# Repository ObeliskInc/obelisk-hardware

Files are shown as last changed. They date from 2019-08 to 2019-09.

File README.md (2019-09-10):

# Obelisk Hardware Files

## Overview
This repository contains the enclosure, control board, and hashing board designs of both generations of Obelisk miners. The files herein give
you the ability to manufacture Obelisk enclosures or PCBs. You are welcome to modify the designs and use them in your own projects.

This repository does not contain the designs for SC1 or DCR1 ASICs, which are proprietary IP.

*NOTE: This document is not yet complete.  We expect to add more information over the following weeks.*

## File Organization

The files in this repository are split into two sections:

* Generation 1 Mining Hardware
* Generation 2 Mining Hardware

Each section includes **Mechanical** and **Electrical** designs.

Mechanical designs include the following file types:

* PDF files: these are typically engineering drawings, which are helpful to manufacturers
* EASM files: these are SolidWorks eDrawings files, which provide a view of the entire assembly that cannot be edited
* DXF files: these are 2-dimentional drawings files, which are typically used for components that are cut (and not bent)
* SLDPRT files: these are SolidWorks part files, which can easily be modified
* SLDASM files: these are SolidWorks assembly files, which references individual SLDPRT files and can be easily modified

To modify our mechanical designs, you can make changes to SLDPRT files in SolidWorks, create a new SLDASM assembly, and generate PDF drawings as needed.
There are numerous tools to convert SolidWorks files to other file formats, some of which can be used by open source CAD editors.

## Generation 1 Mining Hardware

Our first generation of miners, these are also referred to as "Batch 1" hardware. These Gen 1 miners use 120mm fans and resemble
a more traditional ASIC miner form factor.

The Gen 1 enclosure consists of four individual pieces of powder-coated sheet metal, as well as plastic PCB guides and sheet metal airflow guides.

The Gen 1 control board utilizes a SOM (system on module) made by Microchip, and its size is intended to serve as a bottom rest for the hashing boards.

The Gen 1 hashing board consists of 15 ASICs powered in series, each with individual heatsinks.

## Generation 2 Mining hardware

Our second generation of miners, these are also referred to as "Batch 2" or "slim" hardware. These Gen 2 miners use 60mm fans and are approximately half
the width of a traditional ASIC miner. Internally, we referred to Gen 2 miners as the "slimmy" design.

The Gen 2 enclosure consists of five individual pieces of powder-coated sheet metal, and utilizes several standoffs in lieu of screws for easy dissasembly.

The Gen 2 control board is extremely compact and utilizes a microcontroller made by STMicroelectronics.

The Gen 2 hashing board consists of 32 ASICs powered in series, with a large uniform heatsink for better resilience and easier install.

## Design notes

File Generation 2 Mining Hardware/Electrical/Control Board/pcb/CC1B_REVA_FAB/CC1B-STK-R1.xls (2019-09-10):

Customer: |  | Orchid
Project Name: |  | CC1B
 | Revision: | 1.0
Material: |  | IT-180A OR EQUIVALENT
Layer Structure: |  | 8L
Finished Thickness: |  | 72mil+/-10%
Date: |  | 2018-07-30
 |  |  | Stack-up Guideline
Layer |  | Cu Weight | Proposed Nominal Thickness (mils) | Single ended |  | Diff Pairs
 |  |  |  | 50ohm+/-10% |  | 100ohm+/-10%
 |  |  |  | Target LW | Finished LW | Target LW/SP | Finished LW/SP
 | Soldermask
L1 | Top | 1/2oz w/1oz Plating | 2.10 | 5.0 | 5.0 | 4.1/10.9 | 4.1/10.9
 | Prepreg |  | 4.00
L2 | GND | 1/2oz | 0.65
 | Core |  | 6
L3 | Signal | 1/2oz | 0.65 | 5.0 | 4.5 | 4.1/10.9 | 4.1/10.9
 | Prepreg |  | 6.00
L4 | PWR | 1/2oz | 0.65
 | Core |  | 32
L5 | PWR | 1/2oz | 0.65
 | Prepreg |  | 6.00
L6 | Signal | 1/2oz | 0.65 | 5.0 | 4.5 | 4.1/10.9 | 4.1/10.9
 | Core |  | 6
L7 | GND | 1/2oz | 0.65
 | Prepreg |  | 4.00
L8 | Bottom | 1/2oz w/1oz Plating | 2.10 | 5.0 | 5.0 | 4.1/10.9 | 4.1/10.9
 | Soldermask
Finished Thickness (mils) |  |  | 72.10
Stack-up Guideline Notes:
 | Design line width and spacing need to be verified by manufacturing to achieve desired impedance.

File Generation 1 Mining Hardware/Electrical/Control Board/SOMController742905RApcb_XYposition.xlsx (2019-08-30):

PartType | RefDes | PartDecal | Pins | Layer | Orient. | X | Y | SMD | Glued
17-000018 | C1 | CC0603A | 2 | Top | 180 | 190 | 40 | Yes | No
17-000018 | C2 | CC0603A | 2 | Top | 0 | 204.2 | 36.2 | Yes | No
17-000018 | C3 | CC0603A | 2 | Top | 0 | 204.2 | 38 | Yes | No
17-000018 | C4 | CC0603A | 2 | Top | 0 | 200.2 | 32.4 | Yes | No
17-000064 | C5 | 0805 | 2 | Top | 270 | 241.6 | 47.2 | Yes | No
17-000112 | C6 | RAD6_3MM | 2 | Top | 180 | 249.6 | 46 | Yes | No
17-000075 | C7 | CC0402A | 2 | Top | 180 | 149.813 | 33.01 | Yes | No
17-000014 | C8 | CC0402A | 2 | Top | 270 | 83.8 | -48.8 | Yes | No
17-000075 | C9 | CC0402A | 2 | Top | 0 | 103.8 | -31.2 | Yes | No
17-000075 | C10 | CC0402A | 2 | Top | 180 | 91.2 | 4.4 | Yes | No
17-000075 | C11 | CC0402A | 2 | Top | 270 | 106.6 | -23 | Yes | No
17-000075 | C12 | CC0402A | 2 | Top | 180 | 91.2 | 3 | Yes | No
17-000075 | C13 | CC0402A | 2 | Top | 270 | 114.6 | -23 | Yes | No
17-000075 | C14 | CC0402A | 2 | Top | 180 | 91.253 | 5.713 | Yes | No
17-000075 | C15 | CC0402A | 2 | Top | 270 | 146.321 | 14.124 | Yes | No
17-000075 | C16 | CC0402A | 2 | Top | 180 | 67 | 11.6 | Yes | No
17-000075 | C17 | CC0402A | 2 | Top | 0 | 134 | 31.55 | Yes | No
17-000075 | C18 | CC0402A | 2 | Top | 270 | 111.8 | -45 | Yes | No
17-000075 | C19 | CC0402A | 2 | Top | 270 | 33 | -7.6 | Yes | No
17-000090 | C20 | 1206 | 2 | Top | 180 | 18.6 | 8 | Yes | No
17-000075 | C21 | CC0402A | 2 | Top | 0 | 107.75 | -51.1 | Yes | No
17-000075 | C22 | CC0402A | 2 | Top | 180 | 104 | -45 | Yes | No
17-000018 | C23 | CC0603A | 2 | Top | 90 | 186.2 | 36.8 | Yes | No
17-000018 | C24 | CC0603A | 2 | Top | 0 | 194.6 | 30.4 | Yes | No
17-000018 | C25 | CC0603A | 2 | Top | 180 | 205.4 | 30.4 | Yes | No
17-000054 | C26 | CC0402A | 2 | Top | 90 | 106.8 | -45 | Yes | No
17-000079 | C27 | DSK-614 | 2 | Top | 0 | 102.25 | -36.95 | Yes | No
17-000006 | C28 | 0603 | 2 | Top | 0 | 107.55 | -49.3 | Yes | No
17-000080 | C29 | CC0603A | 2 | Top | 180 | 89.665 | 7.142 | Yes | No
17-000080 | C30 | CC0603A | 2 | Top | 270 | 104.8 | -23.2 | Yes | No
17-000080 | C31 | CC0603A | 2 | Top | 180 | 91 | 1.2 | Yes | No
17-000080 | C32 | CC0603A | 2 | Top | 270 | 112.6 | -23.2 | Yes | No
17-000084 | C33 | CC1206 | 2 | Top | 0 | 294.8 | -40.8 | Yes | No
17-000084 | C34 | CC1206 | 2 | Top | 180 | 288.4 | -29.4 | Yes | No
17-000084 | C35 | CC1206 | 2 | Top | 180 | 291.2 | -5.8 | Yes | No
17-000084 | C36 | CC1206 | 2 | Top | 180 | 288.4 | 5.6 | Yes | No
17-000084 | C37 | CC1206 | 2 | Top | 180 | 291.4 | 29.2 | Yes | No
17-000084 | C38 | CC1206 | 2 | Top | 180 | 288.4 | 40.4 | Yes | No
17-000081 | C39 | CC0402A | 2 | Top | 0 | 87 | -42.4 | Yes | No
17-000081 | C40 | CC0402A | 2 | Top | 0 | 296 | -47.8 | Yes | No
17-000018 | C41 | CC0603A | 2 | Top | 180 | 167.132 | -21.908 | Yes | No
17-000075 | C42 | CC0402A | 2 | Top | 180 | 167.45 | -23.495 | Yes | No
17-000054 | C43 | CC0402A | 2 | Top | 180 | 212.25 | -1.5 | Yes | No
17-000054 | C44 | CC0402A | 2 | Top | 180 | 212.25 | -4.5 | Yes | No
17-000054 | C45 | CC0402A | 2 | Top | 180 | 212.25 | -7.5 | Yes | No
17-000054 | C46 | CC0402A | 2 | Top | 180 | 212.25 | -10.5 | Yes | No
17-000054 | C47 | CC0402A | 2 | Top | 0 | 230.75 | -11 | Yes | No
17-000054 | C48 | CC0402A | 2 | Top | 0 | 230.75 | -8 | Yes | No
17-000075 | C49 | CC0402A | 2 | Top | 90 | 223.25 | 0.75 | Yes | No
17-000090 | C50 | 1206 | 2 | Top | 270 | 17.7 | -8.1 | Yes | No
17-000064 | C51 | 0805 | 2 | Top | 270 | 244.4 | 47.2 | Yes | No
17-000036 | C52 | CC0603A | 2 | Top | 0 | 222.5 | 39.25 | Yes | No
17-000083 | C53 | CC1206 | 2 | Top | 180 | 226 | 34.6 | Yes | No
17-000083 | C54 | CC1206 | 2 | Top | 180 | 226 | 32 | Yes | No
17-000084 | C55 | CC1206 | 2 | Top | 180 | 222 | 48.4 | Yes | No
17-000084 | C56 | CC1206 | 2 | Top | 180 | 222 | 45.8 | Yes | No
17-000014 | C57 | CC0402A | 2 | Top | 90 | 298.4 | -48.6 | Yes | No
17-000054 | C58 | CC0402A | 2 | Top | 180 | 80.25 | -39.25 | Yes | No
17-000054 | C59 | CC0402A | 2 | Top | 90 | 265.8 | -46.4 | Yes | No
17-000055 | C60 | CC0402A | 2 | Top | 0 | 72.2 | -38.4 | Yes | No
17-000055 | C61 | CC0402A | 2 | Top | 180 | 277 | -47.4 | Yes | No
17-000036 | C62 | CC0603A | 2 | Top | 180 | 72.25 | -46.25 | Yes | No
17-000036 | C63 | CC0603A | 2 | Top | 180 | 283.5 | -46.5 | Yes | No
17-000075 | C64 | CC0402A | 2 | Top | 270 | 20.2 | -7.6 | Yes | No
17-000075 | C65 | CC0402A | 2 | Top | 90 | 113.4 | -47.8 | Yes | No
17-000075 | C66 | CC0402A | 2 | Top | 180 | 224.6 | 9.6 | Yes | No
53-000021 | D1 | LED2T1_RT | 4 | Top | 90 | 7.24 | -18.27 | No | Yes
34-000023 | D2 | SOT23 | 3 | Top | 270 | 100.2 | -31.2 | Yes | No
34-000024 | D3 | SOD-123F | 2 | Top | 270 | 97.25 | -29.95 | Yes | No
34-000026 | D4 | SMB | 2 | Top | 180 | 295.2 | -29.4 | Yes | No
34-000026 | D5 | SMB | 2 | Top | 180 | 295.2 | 5.6 | Yes | No
34-000026 | D6 | SMB | 2 | Top | 180 | 295.2 | 40.4 | Yes | No
34-000023 | D7 | SOT23 | 3 | Top | 270 | 299.2 | -45.2 | Yes | No
TP-PIN | FID1 | FIDUCIAL-GT | 1 | Top | 0 | 2 | 53 | Yes | No
TP-PIN | FID2 | FIDUCIAL-GT | 1 | Top | 0 | 2 | -53 | Yes | No
TP-PIN | FID3 | FIDUCIAL-GT | 1 | Top | 0 | 318 | 53 | Yes | No
TP-PIN | FID4 | FIDUCIAL-GT | 1 | Bottom | 0 | 2 | 53 | Yes | No
TP-PIN | FID5 | FIDUCIAL-GT | 1 | Bottom | 0 | 2 | -53 | Yes | No
TP-PIN | FID6 | FIDUCIAL-GT | 1 | Bottom | 0 | 318 | 53 | Yes | No
TP-PIN | FID7 | FIDUCIAL-GT | 1 | Top | 0 | 93.34 | 22.66 | Yes | No
TP-PIN | FID8 | FIDUCIAL-GT | 1 | Top | 0 | 136.54 | 22.66 | Yes | No
23-000030 | J1 | AMPHENOL_20021121-00010 | 10 | Top | 0 | 70 | -23.8 | Yes | No
23-000036 | J2 | B04B-PASK | 4 | Top | 0 | 152.083 | -18.098 | No | Yes
23-000046 | J3 | M0850400012 | 34 | Bottom | 0 | 274 | 34.52 | No | Yes
23-000046 | J4 | M0850400012 | 34 | Bottom | 0 | 274 | -0.48 | No | Yes
23-000046 | J5 | M0850400012 | 34 | Bottom | 0 | 274 | -35.48 | No | Yes
23-000052 | J6 | HDR100SIP6 | 6 | Top | 270 | 78.75 | 15.55 | No | No
23-000052 | J7 | HDR100SIP6 | 6 | Top | 270 | 82.75 | 15.55 | No | No
23-000004 | J8 | HDR100SIP3 | 3 | Top | 270 | 74.75 | 14.3 | No | No
23-000026 | J9 | 10118192 | 11 | Top | 0 | 116.25 | -53 | Yes | No
23-000048 | J10 | RJE73-188 | 16 | Top | 270 | 6 | 0 | No | Yes
23-000059 | J11 | FTSH-105-01-F-DV-K | 10 | Top | 90 | 88.2 | -23.7 | Yes | No
OBELISK_LOGO | J12 | OBELISK_LOGO | 0 | Bottom | 0 | 162 | 42 | Yes | No
23-000053 | J13 | HDR20P2X10-FEMALE | 20 | Top | 270 | 195 | -27 | No | No
23-000051 | J14 | M0470531000 | 5 | Bottom | 0 | 78 | -48.75 | No | No
23-000051 | J15 | M0470531000 | 5 | Bottom | 0 | 289.25 | -48.75 | No | No
23-000053 | J16 | HDR20P2X10-FEMALE | 20 | Top | 270 | 159 | -27 | No | Yes
23-000006 | JP1 | HDR100SIP2RA | 2 | Top | 0 | 135.8 | -21.6 | No | No
23-000006 | JP2 | HDR100SIP2RA | 2 | Top | 90 | 145.36 | 7.031 | No | No
41-000027 | L1 | LC0805 | 2 | Top | 90 | 184 | 37.2 | Yes | No
41-000027 | L2 | LC0805 | 2 | Top | 270 | 76.75 | -45.08 | Yes | No
41-000022 | L3 | LC1210 | 2 | Top | 180 | 189.4 | 33.2 | Yes | No
41-000023 | L4 | 0603 | 2 | Top | 180 | 107.6 | -47.6 | Yes | No
41-000027 | L5 | LC0805 | 2 | Top | 270 | 191.4 | 29 | Yes | No
41-000022 | L6 | LC1210 | 2 | Top | 180 | 195.4 | 33.2 | Yes | No
41-000027 | L7 | LC0805 | 2 | Top | 270 | 208.4 | 29 | Yes | No
41-000022 | L8 | LC1210 | 2 | Top | 0 | 205 | 33.2 | Yes | No
41-000023 | L9 | 0603 | 2 | Top | 0 | 6.75 | 9.5 | Yes | No
41-000023 | L10 | 0603 | 2 | Top | 90 | 123.2 | -50.6 | Yes | No
41-000029 | L11 | L7165 | 2 | Top | 90 | 227.8 | 39.8 | Yes | No
41-000027 | L12 | LC0805 | 2 | Top | 270 | 288 | -45.08 | Yes | No
41-000030 | L13 | 0603 | 2 | Top | 270 | 79.25 | -45.5 | Yes | No
41-000030 | L14 | 0603 | 2 | Top | 270 | 81.75 | -45.75 | Yes | No
41-000030 | L15 | 0603 | 2 | Top | 270 | 290.5 | -45.4 | Yes | No
41-000030 | L16 | 0603 | 2 | Top | 270 | 293 | -45.2 | Yes | No
41-000031 | L17 | LC0805 | 2 | Top | 0 | 166.878 | -19.368 | Yes | No
41-000023 | L18 | 0603 | 2 | Top | 0 | 120 | -48.2 | Yes | No
57-000014 | MH1 | MH093PTH | 1 | Top | 0 | 5 | -50 | No | Yes
57-000014 | MH2 | MH093PTH | 1 | Top | 0 | 5 | 50 | No | Yes
57-000014 | MH3 | MH093PTH | 1 | Top | 0 | 315 | 50 | No | Yes
57-000014 | MH4 | MH093PTH | 1 | Top | 0 | 315 | -50 | No | Yes
57-000014 | MH5 | MH093PTH | 1 | Top | 0 | 160 | 0 | No | Yes
57-000014 | MH6 | MH093PTHA | 1 | Top | 0 | 57.5 | 31.1 | No | Yes
42-000071 | MOD1 | SAMA5D27_SOM1 | 176 | Top | 0 | 115 | 0 | Yes | Yes
87-000021 | Q1 | SOT-23 | 3 | Top | 90 | 11 | -22.8 | Yes | No
87-000021 | Q2 | SOT-23 | 3 | Top | 90 | 11 | -19.3 | Yes | No
87-000021 | Q3 | SOT-23 | 3 | Top | 90 | 87 | -44.9 | Yes | No
87-000021 | Q4 | SOT-23 | 3 | Top | 90 | 295.8 | -45.2 | Yes | No
87-000021 | Q5 | SOT-23 | 3 | Top | 270 | 65 | -41 | Yes | No
87-000021 | Q6 | SOT-23 | 3 | Top | 180 | 271.4 | -49.6 | Yes | No
87-000022 | Q7 | SOT-23 | 3 | Top | 270 | 72.2 | -41 | Yes | No
87-000022 | Q8 | SOT-23 | 3 | Top | 90 | 277 | -45 | Yes | No
62-000042 | R1 | RC0402A | 2 | Top | 0 | 139.954 | 1.27 | Yes | No
62-000041 | R2 | RC0402A | 2 | Top | 0 | 215.25 | 0 | Yes | No
62-000041 | R3 | RC0402A | 2 | Top | 0 | 215.25 | -3 | Yes | No
62-000041 | R4 | RC0402A | 2 | Top | 0 | 215.25 | -6 | Yes | No
62-000041 | R5 | RC0402A | 2 | Top | 0 | 215.25 | -9 | Yes | No
62-000041 | R6 | RC0402A | 2 | Top | 180 | 227.75 | -9.5 | Yes | No
62-000103 | R7 | RC0402A | 2 | Top | 90 | 83.8 | -45.6 | Yes | No
62-000103 | R8 | RC0402A | 2 | Top | 180 | 296 | -49.4 | Yes | No
62-000096 | R9 | RC0402A | 2 | Top | 180 | 188.6 | 35.8 | Yes | No
62-000096 | R10 | RC0402A | 2 | Top | 90 | 206.2 | 28 | Yes | No
62-000097 | R11 | RC0402A | 2 | Top | 0 | 191.6 | 35.8 | Yes | No
62-000097 | R12 | RC0402A | 2 | Top | 90 | 204.6 | 28 | Yes | No
62-000096 | R13 | RC0402A | 2 | Top | 90 | 193.8 | 28 | Yes | No
62-000097 | R14 | RC0402A | 2 | Top | 90 | 195.4 | 28 | Yes | No
62-000044 | R15 | RC0402A | 2 | Top | 90 | 221.75 | 7 | Yes | No
62-000041 | R16 | RC0402A | 2 | Top | 180 | 15 | -25.4 | Yes | No
62-000100 | R17 | RC0402A | 2 | Top | 0 | 64.8 | -20.8 | Yes | No
62-000100 | R18 | RC0402A | 2 | Top | 0 | 64.8 | -22.3 | Yes | No
62-000100 | R19 | RC0402A | 2 | Top | 0 | 64.8 | -23.8 | Yes | No
62-000100 | R20 | RC0402A | 2 | Top | 0 | 64.8 | -25.3 | Yes | No
62-000100 | R21 | RC0402A | 2 | Top | 0 | 75.5 | -20.9 | Yes | No
62-000100 | R22 | RC0402A | 2 | Top | 0 | 75.5 | -22.4 | Yes | No
62-000114 | R23 | RC0402A | 2 | Top | 270 | 4.8 | -21.2 | Yes | No
62-000114 | R24 | RC0402A | 2 | Top | 270 | 7.2 | -21.2 | Yes | No
62-000114 | R25 | RC0402A | 2 | Top | 0 | 13.667 | 6.952 | Yes | No
62-000014 | R26 | RC0402A | 2 | Top | 270 | 110.2 | -45 | Yes | No
62-000041 | R27 | RC0402A | 2 | Top | 0 | 194.2 | 41.6 | Yes | No
62-000091 | R28 | RC0402A | 2 | Top | 270 | 67.8 | -41 | Yes | No
62-000091 | R29 | RC0402A | 2 | Top | 180 | 277 | -50.6 | Yes | No
62-000041 | R30 | RC0402A | 2 | Top | 90 | 203.2 | 40.4 | Yes | No
62-000110 | R31 | RC0402A | 2 | Top | 270 | 23.2 | 7.4 | Yes | No
62-000110 | R32 | RC0402A | 2 | Top | 270 | 29.6 | 7.4 | Yes | No
62-000028 | R33 | 1206 | 2 | Top | 0 | 72.25 | -44 | Yes | No
62-000044 | R34 | RC0402A | 2 | Top | 90 | 110.6 | -22.8 | Yes | No
62-000028 | R35 | 1206 | 2 | Top | 0 | 283.5 | -44 | Yes | No
62-000041 | R36 | RC0402A | 2 | Top | 0 | 65.6 | -36.8 | Yes | No
62-000041 | R37 | RC0402A | 2 | Top | 0 | 83 | -26.45 | Yes | No
62-000041 | R38 | RC0402A | 2 | Top | 270 | 145 | 14.05 | Yes | No
62-000041 | R39 | RC0402A | 2 | Top | 180 | 134 | 30.05 | Yes | No
62-000041 | R40 | RC0402A | 2 | Top | 0 | 120.2 | 29 | Yes | No
62-000013 | R41 | RC0402A | 2 | Top | 180 | 141.35 | 8.6 | Yes | No
62-000041 | R42 | RC0402A | 2 | Top | 180 | 96 | -46.5 | Yes | No
62-000041 | R43 | RC0402A | 2 | Top | 90 | 86.015 | 4.285 | Yes | No
62-000041 | R44 | RC0402A | 2 | Top | 90 | 270.6 | -46.4 | Yes | No
62-000041 | R45 | RC0402A | 2 | Top | 0 | 96 | -48 | Yes | No
62-000041 | R46 | RC0402A | 2 | Top | 180 | 227.75 | -6.5 | Yes | No
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

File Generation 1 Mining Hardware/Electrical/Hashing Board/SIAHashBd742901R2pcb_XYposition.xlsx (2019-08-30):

PartType | RefDes | PartDecal | Pins | Layer | Orient. | X | Y | SMD | Glued
17-000073 | C1 | 0805 | 2 | Top | 90 | 128.4 | 93.6 | Yes | Yes
17-000073 | C2 | 0805 | 2 | Top | 90 | 128.4 | 55.6 | Yes | Yes
17-000073 | C3 | 0805 | 2 | Top | 0 | 134.8 | 96.4 | Yes | Yes
17-000074 | C4 | CC0603 | 2 | Top | 180 | 106.25 | 115 | Yes | Yes
17-000074 | C5 | CC0603 | 2 | Top | 90 | 128.8 | 114.6 | Yes | Yes
17-000074 | C6 | CC0603 | 2 | Top | 0 | 106.25 | 77 | Yes | Yes
17-000074 | C7 | CC0603 | 2 | Top | 90 | 128.8 | 76.6 | Yes | Yes
17-000074 | C8 | CC0603 | 2 | Top | 0 | 155.75 | 74 | Yes | Yes
17-000074 | C9 | CC0603 | 2 | Top | 270 | 133.4 | 74.6 | Yes | Yes
17-000086 | C10 | CC0603A | 2 | Bottom | 180 | 113.4 | 109.4 | Yes | Yes
17-000086 | C11 | CC0603A | 2 | Bottom | 0 | 119.8 | 97.8 | Yes | Yes
17-000086 | C12 | CC0603A | 2 | Top | 0 | 113 | 93 | Yes | Yes
17-000086 | C13 | CC0603A | 2 | Top | 90 | 105.6 | 97.8 | Yes | Yes
17-000086 | C14 | CC0603A | 2 | Bottom | 180 | 113.4 | 71.4 | Yes | Yes
17-000086 | C15 | CC0603A | 2 | Bottom | 0 | 119.8 | 59.8 | Yes | Yes
17-000086 | C16 | CC0603A | 2 | Top | 0 | 113 | 55 | Yes | Yes
17-000086 | C17 | CC0603A | 2 | Top | 90 | 105.6 | 59.8 | Yes | Yes
17-000086 | C18 | CC0603A | 2 | Bottom | 0 | 148.6 | 79.6 | Yes | Yes
17-000086 | C19 | CC0603A | 2 | Bottom | 180 | 142.2 | 91.2 | Yes | Yes
17-000086 | C20 | CC0603A | 2 | Top | 180 | 149 | 96 | Yes | Yes
17-000086 | C21 | CC0603A | 2 | Top | 270 | 156.4 | 91.2 | Yes | Yes
17-000087 | C22 | CC0402A | 2 | Top | 180 | 128.4 | 104 | Yes | Yes
17-000087 | C23 | CC0402A | 2 | Top | 180 | 128.4 | 98 | Yes | Yes
17-000087 | C24 | CC0402A | 2 | Bottom | 270 | 117 | 101.6 | Yes | Yes
17-000087 | C25 | CC0402A | 2 | Bottom | 270 | 117 | 104 | Yes | Yes
17-000087 | C26 | CC0402A | 2 | Bottom | 270 | 117 | 106.4 | Yes | Yes
17-000087 | C27 | CC0402A | 2 | Top | 180 | 121.2 | 93 | Yes | Yes
17-000087 | C28 | CC0402A | 2 | Top | 0 | 107 | 93 | Yes | Yes
17-000087 | C29 | CC0402A | 2 | Bottom | 180 | 118.2 | 109 | Yes | Yes
17-000087 | C30 | CC0402A | 2 | Bottom | 0 | 120.6 | 109 | Yes | Yes
17-000087 | C31 | CC0402A | 2 | Bottom | 0 | 113.4 | 98.2 | Yes | Yes
17-000087 | C32 | CC0402A | 2 | Bottom | 180 | 115.8 | 98.2 | Yes | Yes
17-000087 | C33 | CC0402A | 2 | Top | 180 | 128.4 | 66 | Yes | Yes
17-000087 | C34 | CC0402A | 2 | Bottom | 270 | 117 | 63.6 | Yes | Yes
17-000087 | C35 | CC0402A | 2 | Bottom | 270 | 117 | 66 | Yes | Yes
17-000087 | C36 | CC0402A | 2 | Bottom | 270 | 117 | 68.4 | Yes | Yes
17-000087 | C37 | CC0402A | 2 | Top | 180 | 128.4 | 60 | Yes | Yes
17-000087 | C38 | CC0402A | 2 | Top | 0 | 121.4 | 55 | Yes | Yes
17-000087 | C39 | CC0402A | 2 | Bottom | 180 | 118.2 | 71 | Yes | Yes
17-000087 | C40 | CC0402A | 2 | Bottom | 0 | 120.6 | 71 | Yes | Yes
17-000087 | C41 | CC0402A | 2 | Bottom | 0 | 113.4 | 60.2 | Yes | Yes
17-000087 | C42 | CC0402A | 2 | Bottom | 180 | 115.8 | 60.2 | Yes | Yes
17-000087 | C43 | CC0402A | 2 | Top | 0 | 107 | 55 | Yes | Yes
17-000087 | C44 | CC0402A | 2 | Bottom | 180 | 148.6 | 90.8 | Yes | Yes
17-000087 | C45 | CC0402A | 2 | Bottom | 0 | 146.2 | 90.8 | Yes | Yes
17-000087 | C46 | CC0402A | 2 | Top | 180 | 155 | 96 | Yes | Yes
17-000087 | C47 | CC0402A | 2 | Top | 0 | 141 | 96 | Yes | Yes
17-000087 | C48 | CC0402A | 2 | Bottom | 90 | 145 | 87.4 | Yes | Yes
17-000087 | C49 | CC0402A | 2 | Bottom | 90 | 145 | 85 | Yes | Yes
17-000087 | C50 | CC0402A | 2 | Bottom | 90 | 145 | 82.6 | Yes | Yes
17-000087 | C51 | CC0402A | 2 | Top | 0 | 133.8 | 91 | Yes | Yes
17-000087 | C52 | CC0402A | 2 | Top | 0 | 133.8 | 85 | Yes | Yes
17-000087 | C53 | CC0402A | 2 | Bottom | 0 | 143.8 | 80 | Yes | Yes
17-000087 | C54 | CC0402A | 2 | Bottom | 180 | 141.4 | 80 | Yes | Yes
17-000013 | C55 | CC0402A | 2 | Top | 270 | 115.4 | 115.2 | Yes | Yes
17-000013 | C56 | CC0402A | 2 | Top | 270 | 112.6 | 115.2 | Yes | Yes
17-000013 | C57 | CC0402A | 2 | Top | 270 | 114 | 115.2 | Yes | Yes
17-000013 | C58 | CC0402A | 2 | Top | 270 | 116.6 | 115.2 | Yes | Yes
17-000013 | C59 | CC0402A | 2 | Top | 270 | 115.4 | 77.2 | Yes | Yes
17-000013 | C60 | CC0402A | 2 | Top | 270 | 112.6 | 77.2 | Yes | Yes
17-000013 | C61 | CC0402A | 2 | Top | 270 | 114 | 77.2 | Yes | Yes
17-000013 | C62 | CC0402A | 2 | Top | 270 | 116.6 | 77.2 | Yes | Yes
17-000013 | C63 | CC0402A | 2 | Top | 90 | 146.6 | 73.8 | Yes | Yes
17-000013 | C64 | CC0402A | 2 | Top | 90 | 149.4 | 73.8 | Yes | Yes
17-000013 | C65 | CC0402A | 2 | Top | 90 | 148 | 73.8 | Yes | Yes
17-000013 | C66 | CC0402A | 2 | Top | 90 | 145.4 | 73.8 | Yes | Yes
17-000073 | C67 | 0805 | 2 | Top | 270 | 133.4 | 133.4 | Yes | Yes
17-000074 | C68 | CC0603 | 2 | Top | 0 | 155.75 | 112 | Yes | Yes
17-000074 | C69 | CC0603 | 2 | Top | 270 | 133.4 | 112.6 | Yes | Yes
17-000086 | C70 | CC0603A | 2 | Bottom | 0 | 148.6 | 117.6 | Yes | Yes
17-000086 | C71 | CC0603A | 2 | Bottom | 180 | 142.2 | 129.2 | Yes | Yes
17-000086 | C72 | CC0603A | 2 | Top | 180 | 145 | 134 | Yes | Yes
17-000086 | C73 | CC0603A | 2 | Top | 0 | 157.425 | 127.825 | Yes | Yes
17-000087 | C74 | CC0402A | 2 | Bottom | 180 | 148.6 | 128.8 | Yes | Yes
17-000087 | C75 | CC0402A | 2 | Bottom | 0 | 146.2 | 128.8 | Yes | Yes
17-000087 | C76 | CC0402A | 2 | Top | 0 | 152 | 134 | Yes | Yes
17-000087 | C77 | CC0402A | 2 | Top | 0 | 139 | 134 | Yes | Yes
17-000087 | C78 | CC0402A | 2 | Bottom | 90 | 145 | 125.4 | Yes | Yes
17-000087 | C79 | CC0402A | 2 | Bottom | 90 | 145 | 123 | Yes | Yes
17-000087 | C80 | CC0402A | 2 | Bottom | 90 | 145 | 120.6 | Yes | Yes
17-000087 | C81 | CC0402A | 2 | Top | 0 | 133.8 | 129 | Yes | Yes
17-000087 | C82 | CC0402A | 2 | Top | 0 | 133.8 | 123 | Yes | Yes
17-000087 | C83 | CC0402A | 2 | Bottom | 0 | 143.8 | 118 | Yes | Yes
17-000087 | C84 | CC0402A | 2 | Bottom | 180 | 141.4 | 118 | Yes | Yes
17-000013 | C85 | CC0402A | 2 | Top | 90 | 146.6 | 111.8 | Yes | Yes
17-000013 | C86 | CC0402A | 2 | Top | 90 | 149.4 | 111.8 | Yes | Yes
17-000013 | C87 | CC0402A | 2 | Top | 90 | 148 | 111.8 | Yes | Yes
17-000013 | C88 | CC0402A | 2 | Top | 90 | 145.4 | 111.8 | Yes | Yes
17-000073 | C89 | 0805 | 2 | Top | 90 | 184.4 | 93.6 | Yes | Yes
17-000074 | C90 | CC0603 | 2 | Top | 180 | 162.25 | 115 | Yes | Yes
17-000074 | C91 | CC0603 | 2 | Top | 90 | 184.4 | 114.6 | Yes | Yes
17-000086 | C92 | CC0603A | 2 | Bottom | 180 | 169.4 | 109.4 | Yes | Yes
17-000086 | C93 | CC0603A | 2 | Bottom | 0 | 175.8 | 97.8 | Yes | Yes
17-000086 | C94 | CC0603A | 2 | Top | 0 | 169 | 93 | Yes | Yes
17-000086 | C95 | CC0603A | 2 | Top | 90 | 161.6 | 97.8 | Yes | Yes
17-000087 | C96 | CC0402A | 2 | Bottom | 0 | 169.4 | 98.2 | Yes | Yes
17-000087 | C97 | CC0402A | 2 | Bottom | 180 | 171.8 | 98.2 | Yes | Yes
17-000087 | C98 | CC0402A | 2 | Top | 180 | 184.4 | 104 | Yes | Yes
17-000087 | C99 | CC0402A | 2 | Top | 180 | 184.4 | 98 | Yes | Yes
17-000087 | C100 | CC0402A | 2 | Bottom | 270 | 173 | 101.6 | Yes | Yes
17-000087 | C101 | CC0402A | 2 | Bottom | 270 | 173 | 104 | Yes | Yes
17-000087 | C102 | CC0402A | 2 | Bottom | 270 | 173 | 106.4 | Yes | Yes
17-000087 | C103 | CC0402A | 2 | Top | 180 | 177.4 | 93 | Yes | Yes
17-000087 | C104 | CC0402A | 2 | Top | 0 | 163 | 93 | Yes | Yes
17-000087 | C105 | CC0402A | 2 | Bottom | 180 | 174.2 | 109 | Yes | Yes
17-000087 | C106 | CC0402A | 2 | Bottom | 0 | 176.6 | 109 | Yes | Yes
17-000013 | C107 | CC0402A | 2 | Top | 270 | 171.4 | 115.2 | Yes | Yes
17-000013 | C108 | CC0402A | 2 | Top | 270 | 168.6 | 115.2 | Yes | Yes
17-000013 | C109 | CC0402A | 2 | Top | 270 | 170 | 115.2 | Yes | Yes
17-000013 | C110 | CC0402A | 2 | Top | 270 | 172.6 | 115.2 | Yes | Yes
17-000073 | C111 | 0805 | 2 | Top | 270 | 184.4 | 55.6 | Yes | Yes
17-000074 | C112 | CC0603 | 2 | Top | 180 | 162.25 | 77 | Yes | Yes
17-000074 | C113 | CC0603 | 2 | Top | 90 | 184.4 | 76.6 | Yes | Yes
17-000086 | C114 | CC0603A | 2 | Bottom | 180 | 169.4 | 71.4 | Yes | Yes
17-000086 | C115 | CC0603A | 2 | Bottom | 0 | 175.8 | 59.8 | Yes | Yes
17-000086 | C116 | CC0603A | 2 | Top | 0 | 169 | 55 | Yes | Yes
17-000086 | C117 | CC0603A | 2 | Top | 90 | 161.6 | 59.8 | Yes | Yes
17-000087 | C118 | CC0402A | 2 | Bottom | 0 | 169.4 | 60.2 | Yes | Yes
17-000087 | C119 | CC0402A | 2 | Bottom | 180 | 171.8 | 60.2 | Yes | Yes
17-000087 | C120 | CC0402A | 2 | Top | 180 | 184.4 | 66 | Yes | Yes
17-000087 | C121 | CC0402A | 2 | Top | 0 | 184.4 | 59 | Yes | Yes
17-000087 | C122 | CC0402A | 2 | Bottom | 270 | 173 | 63.6 | Yes | Yes
17-000087 | C123 | CC0402A | 2 | Bottom | 270 | 173 | 66 | Yes | Yes
17-000087 | C124 | CC0402A | 2 | Bottom | 270 | 173 | 68.4 | Yes | Yes
17-000087 | C125 | CC0402A | 2 | Top | 0 | 177.4 | 55 | Yes | Yes
17-000087 | C126 | CC0402A | 2 | Top | 0 | 163 | 55 | Yes | Yes
17-000087 | C127 | CC0402A | 2 | Bottom | 180 | 174.2 | 71 | Yes | Yes
17-000087 | C128 | CC0402A | 2 | Bottom | 0 | 176.6 | 71 | Yes | Yes
17-000013 | C129 | CC0402A | 2 | Top | 270 | 171.4 | 77.2 | Yes | Yes
17-000013 | C130 | CC0402A | 2 | Top | 270 | 168.6 | 77.2 | Yes | Yes
17-000013 | C131 | CC0402A | 2 | Top | 270 | 170 | 77.2 | Yes | Yes
17-000013 | C132 | CC0402A | 2 | Top | 270 | 172.6 | 77.2 | Yes | Yes
17-000073 | C133 | 0805 | 2 | Top | 180 | 190.8 | 96.4 | Yes | Yes
17-000074 | C134 | CC0603 | 2 | Top | 0 | 211.8 | 74 | Yes | Yes
17-000074 | C135 | CC0603 | 2 | Top | 270 | 189.6 | 74.6 | Yes | Yes
17-000086 | C136 | CC0603A | 2 | Bottom | 0 | 204.6 | 79.6 | Yes | Yes
17-000086 | C137 | CC0603A | 2 | Bottom | 180 | 198.2 | 91.2 | Yes | Yes
17-000086 | C138 | CC0603A | 2 | Top | 180 | 205 | 96 | Yes | Yes
17-000086 | C139 | CC0603A | 2 | Top | 270 | 212.4 | 91.2 | Yes | Yes
17-000087 | C140 | CC0402A | 2 | Bottom | 180 | 204.6 | 90.8 | Yes | Yes
17-000087 | C141 | CC0402A | 2 | Bottom | 0 | 202.2 | 90.8 | Yes | Yes
17-000087 | C142 | CC0402A | 2 | Top | 180 | 189.8 | 85 | Yes | Yes
17-000087 | C143 | CC0402A | 2 | Top | 180 | 189.8 | 91.9 | Yes | Yes
17-000087 | C144 | CC0402A | 2 | Bottom | 90 | 201 | 87.4 | Yes | Yes
17-000087 | C145 | CC0402A | 2 | Bottom | 90 | 201 | 85 | Yes | Yes
17-000087 | C146 | CC0402A | 2 | Bottom | 90 | 201 | 82.6 | Yes | Yes
17-000087 | C147 | CC0402A | 2 | Top | 180 | 196.7 | 95.9 | Yes | Yes
17-000087 | C148 | CC0402A | 2 | Top | 180 | 211 | 96 | Yes | Yes
17-000087 | C149 | CC0402A | 2 | Bottom | 0 | 199.8 | 80 | Yes | Yes
17-000087 | C150 | CC0402A | 2 | Bottom | 180 | 197.4 | 80 | Yes | Yes
17-000013 | C151 | CC0402A | 2 | Top | 90 | 202.6 | 73.8 | Yes | Yes
17-000013 | C152 | CC0402A | 2 | Top | 90 | 205.4 | 73.8 | Yes | Yes
17-000013 | C153 | CC0402A | 2 | Top | 90 | 204 | 73.8 | Yes | Yes
17-000013 | C154 | CC0402A | 2 | Top | 90 | 201.4 | 73.8 | Yes | Yes
17-000073 | C155 | 0805 | 2 | Top | 270 | 189.4 | 133.4 | Yes | Yes
17-000074 | C156 | CC0603 | 2 | Top | 0 | 211.75 | 112 | Yes | Yes
17-000074 | C157 | CC0603 | 2 | Top | 270 | 189.4 | 112.6 | Yes | Yes
17-000086 | C158 | CC0603A | 2 | Bottom | 0 | 204.6 | 117.6 | Yes | Yes
17-000086 | C159 | CC0603A | 2 | Bottom | 180 | 198.2 | 129.2 | Yes | Yes
17-000086 | C160 | CC0603A | 2 | Top | 180 | 201 | 134 | Yes | Yes
17-000086 | C161 | CC0603A | 2 | Top | 0 | 213.4 | 127.8 | Yes | Yes
17-000087 | C162 | CC0402A | 2 | Bottom | 180 | 204.6 | 128.8 | Yes | Yes
17-000087 | C163 | CC0402A | 2 | Bottom | 0 | 202.2 | 128.8 | Yes | Yes
17-000087 | C164 | CC0402A | 2 | Top | 180 | 189.8 | 123 | Yes | Yes
17-000087 | C165 | CC0402A | 2 | Top | 0 | 189.8 | 129 | Yes | Yes
17-000087 | C166 | CC0402A | 2 | Bottom | 90 | 201 | 125.4 | Yes | Yes
17-000087 | C167 | CC0402A | 2 | Bottom | 90 | 201 | 123 | Yes | Yes
17-000087 | C168 | CC0402A | 2 | Bottom | 90 | 201 | 120.6 | Yes | Yes
17-000087 | C169 | CC0402A | 2 | Top | 0 | 194.5 | 134 | Yes | Yes
17-000087 | C170 | CC0402A | 2 | Top | 0 | 207.5 | 134 | Yes | Yes
17-000087 | C171 | CC0402A | 2 | Bottom | 0 | 199.8 | 118 | Yes | Yes
17-000087 | C172 | CC0402A | 2 | Bottom | 180 | 197.4 | 118 | Yes | Yes
17-000013 | C173 | CC0402A | 2 | Top | 90 | 202.6 | 111.8 | Yes | Yes
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

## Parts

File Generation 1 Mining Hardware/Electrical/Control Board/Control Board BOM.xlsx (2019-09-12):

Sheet: RevHist
Obelisk Miner Controller PCB BOM
Client: | Obelisk
Project: | Digital Currency Miner
Job: | 06009-00
Contact: | Mr. Zach Herbert
File: | BOM_06009_Obelisk_Controller PCB
Rev: | 2018-07-24
SCOPE; | This spreadsheet contains BOM and component catalog information for the Obelisk Digital Currency Miner
NOTES:
 | 1. Customer, Project, Job etc (B3 - B8) are entered on this sheet only!!
 | 2. R27A to be placed on top of R27
REVISION HISTORY:
 | RevA: 06/13/18: MPL Production release BOM imported from 742902Rev5 Prototype release with Updates
 | RevB: 07/23/188: MPL Production Revision Modified to correct issue with U1 power up

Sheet: REV B - Production Revision
Obelisk Blake2B Control Board
Client: | Obelisk
Project: | Blake2Miner
Date: | 2018-07-23
Schematic: | 742904
Revision: | B
Build
Job | 6009
 |  |  |  |  |  |  |  | 100K Piece Price |  | Price | Order |  |  |  |  | Comments
Item | TechEn P/N | Qty | Reference | Schematic Value | Part Description | Manufacturer | MFG Part number | Cost | Ext Cost | Source | Qty | Vendor | Vendor Part Number | Vendor Part Number | Footprint
1 | 17-000014 | 2 | , R27 | 1µF | CAP CER 1UF 16V X5R 0402 | Kemet | C0402C105K4PAC7867 | $0.02200 | $0.04400 | On-Line |  | Digi-Key | 399-12289-1-ND | 399-12289-2-ND | CC0402A | Qty Change
 |  |  |  |  |  | TDK | C1005X6S1C105K050BC
2 | 17-000018 | 8 | C1, C2, C3, C4, C23, C24, C25, C41 | 10µF | CAP CER 10UF 16V X5R 0603 | Murata | GRM188R61C106MA73D | $0.09201 | $0.73608 | On-Line |  | Digi-Key | 490-7201-1-ND | 490-7201-2-ND | CC0603
 |  |  |  |  |  | Taiyo Yuden | EMK107BBJ106MA-T
3 | 17-000036 | 3 | C52, C62, C63 | 0.1uF | CAP CER 0.1UF 25V X7R 0603 | Murata | GRM188R71E104KA01D | $0.08325 | $0.24975 | On-Line |  | Digi-Key | 490-1524-1-ND | 490-1524-2-ND | CC0603
 |  |  |  |  |  | Murata | GRM188R71E104KA01D
 |  |  |  |  |  | Murata | GCM188R71E104KA57D
 |  |  |  |  |  | TDK | C1608X8R1E104K080AA
4 | 17-000054 | 2 | C58, C59 | 100pF | Capacitor Ceramic 100pF ±5% 50V C0G, NP0 0402 | Murata | GRM1555C1H101JA01D | $0.02200 | $0.04400 | On-Line |  | Digi-Key | 490-5922-1-ND | 490-5922-2-ND | CC0402A
 |  |  |  |  |  | AVX CORPORATION | 04025A101FAT2A
5 | 17-000055 | 2 | C60, C61 | 0.01uF | Capacitor Ceramic 10000pF ±10% 50V X7R 0402 | Murata | GRM155R71H103KA88D | $0.09201 | $0.18402 | On-Line |  | Digi-Key | 490-4516-1-ND | 490-4516-2-ND | CC0402A
6 | 17-000064 | 2 | C5, C51 | 0.1µF | Capacitor Ceramic 0.1µF ±10% 25V X7R 0805 | AVX | 08053C104KAT2A | $0.08325 | $0.16650 | On-Line |  | Digi-Key | 478-3755-1-ND | 478-3755-2-ND | CC0805
 |  |  |  |  |  | AVX CORPORATION | 08051C104JAT2A
7 | 17-000075 | 13 | C9, C10, C11, C12, C13, C14, C15, C17, C19, C42, C49, C64, C66 | 0.1µF | CAP CER 0.1UF 16V X7R 0402 | Murata | GRM155R71C104KA88J | $0.01838 | $0.23894 | On-Line |  | Digi-Key | 490-6328-1-ND | 490-6328-2-ND | CC0402A
 |  |  |  |  |  | TDK CORPORATION | C1005X7R1H104K050BB
 |  |  |  |  |  | TDK CORPORATION | CGJ2B2X7R1C104K050BA
8 | 17-000080 | 4 | C29, C30, C31, C32 | 2.2uF | Capacitor Ceramic 2.2µF ±10% 10V X7R 0603 | Taiyo Yuden | LMK107B7225KA-T | $0.05940 | $0.23760 | On-Line |  | Digi-Key | 587-2983-1-ND | 587-2983-2-ND | CC0603
 |  |  |  |  |  | TDK CORPORATION (VA) | C1608X7R1A225K080AC
9 | 17-000081 | 2 | C39, C40 | 1200pF | Capacitor Ceramic 1200pF ±10% 50V X7R 0402 | Samsung | CL05B122KB5NNNC | $0.00341 | $0.00682 | On-Line |  | Digi-Key | 1276-1515-1-ND | 1276-1515-2-ND | CC0402A
10 | 17-000083 | 2 | C53, C54 | 22uF | Capacitor Ceramic 22µF ±20% 10V Ceramic X7R 1206 | Taiyo Yuden | LMK316AB7226ML-TR | $0.12915 | $0.25830 | On-Line |  | Digi-Key | 587-2782-1-ND | 587-2782-2-ND | CC1206
 |  |  |  |  |  | Taiyo Yuden | EMK316BB7226ML-T
11 | 17-000084 | 8 | C33, C34, C35, C36, C37, C38, C55, C56 | 10uF | Capacitor Ceramic 10µF ±10% 25V X7R 1206 | Samsung | CL31B106KAHNNNE | $0.05960 | $0.47680 | On-Line |  | Digi-Key | 1276-1804-1-ND | 1276-1804-2-ND | CC1206
 |  |  |  |  |  | TDK CORPORATION | C3216X7R1E106K160AB
12 | 17-000090 | 2 | C20, C50 | 1000pF | Capacitor Ceramic 1000pF ±10% 2kV X7R 1206 | Knowles Novacap | 1206B102K202NT | $0.12854 | $0.25708 | On-Line |  | Digi-Key | 1763-1102-1-ND | 1763-1102-2-ND | CC1206
 |  |  |  |  |  | AVX CORPORATION | 1206GC102KAZ1A
13 | 17-000112 | 1 | C6 | 100µF | Capacitor Radial Aluminum Polymer 100µF 16V Can SMD | Panasonic | 16SVPC100M | $0.25500 | $0.25500 | On-Line |  | Digi-Key | P16468CT-ND | P16468TR-ND | RAD6_3MM
14 | 23-000015 | 1 | SD1 |  | CONN MICRO SD CARD PUSH-PULL R/A | Molex | 5040771891 | $0.94962 | $0.94962 | On-Line |  | Digi-Key | WM9315CT-ND | WM9315TR-ND | MOLEXMICROSD
15 | 23-000046 | 3 | J3, J4, J5 | DIN 32P | Connector DIN41612 32P Style B/2 FEMALE | Molex | 0850400012 | $1.27778 | $3.83334 | On-Line |  | Digi-Key | WM4350-ND |  | M0850400012
 |  |  |  |  |  | TE | 5650858-5
 |  |  |  |  |  | Harting | 09222326825
16 | 23-000048 | 1 | J10 |  | Jack Modular Connector 8p8c RJ45 RtAng Shielded, EMI Finger | Amphenol | RJE73-188-00410 | $2.22460 | $2.22460 | On-Line |  | Digi-Key | RJE73-188-00410CT-ND | RJE73-188-00410TR-ND | RJE73-188
 |  |  |  |  |  | Amphenol | RJE73-188-00310
17 | 23-000051 | 2 | J14, J15 | CON4 | Connector Header 4 Positions 0.100" Through Hole Tin | Molex | 0470531000 | $0.18320 | $0.36640 | On-Line |  | Digi-Key | WM4330-ND |  | M0470531000
18 | 23-000053 | 1 | J16 |  | 20 Position Header Connector 0.100" (2.54mm) Through Hole Tin | Sullins | PPTC102LFBN-RC | $0.64870 | $0.64870 | On-Line |  | Digi-Key | S7078-ND |  | HDR20P2X10-FEMALE
19 | 34-000023 | 1 | D2 | Schottky | Diode Array 1 Pair Common Cathode Schottky 30V 200mA SOT-23-3 | Diodes Inc | BAT54C-7-F | $0.03238 | $0.03238 | On-Line |  | Digi-Key | BAT54C-FDICT-ND | BAT54C-FDITR-ND | SOT23
20 | 34-000026 | 3 | D4, D5, D6 | CGRB201 | Diode Standard 50V 2A Surface Mount DO-214AA (SMB) | Comchip | CGRB201-G | $0.05880 | $0.17640 | On-Line |  | Digi-Key | 641-1165-1-ND | 641-1165-2-ND | SMB
21 | 41-000022 | 3 | L3, L6, L8 | 1µH | Inductor Unshielded Wirewound 1µH 2.2A 51.6 mOhm Max 1210 | Taiyo Yuden | BRL3225T1R0M | $0.08525 | $0.25575 | On-Line |  | Digi-Key | 587-2164-1-ND | 587-2164-2-ND | LC1210
22 | 41-000023 | 1 | L9 | BLM18 | FERRITE BEAD 180 OHM 0603 1LN | Murata | BLM18PG181SN1D | $0.01932 | $0.01932 | On-Line |  | Digi-Key | 490-5263-1-ND | 490-5263-2-ND | 603
 |  |  |  |  |  | Abracon LLC | AISC-1210H-1R0N-T
23 | 41-000027 | 5 | L1, L2, L5, L7, L12 | MPZ2012 | FERRITE BEAD 220 OHM 0805 1LN | TDK | MPZ2012S221AT000 | $0.02352 | $0.11760 | On-Line |  | Digi-Key | 445-1568-1-ND | 445-1568-2-ND | LC0805
24 | 41-000029 | 1 | L11 | 3.3uH | Inductor Wirewound 3.3µH Shielded 6.8A 29.7 mOhm | TDK | SPM6530T-3R3M | $0.52500 | $0.52500 | On-Line |  | Digi-Key | 445-4119-1-ND | 445-4119-2-ND | L7165
25 | 41-000030 | 4 | L13, L14, L15, L16 | MMZ1608 | FERRITE BEAD 1 KOHM 0603 1LN | TDK | MMZ1608S102ATA00 | $0.01560 | $0.06240 | On-Line |  | Digi-Key | 445-1550-1-ND | 445-1550-2-ND | 603
26 | 41-000031 | 1 | L17 | 10uH | Inductor Multilayer 10µH Shielded 500mA 390 mOhm Max 0805 | TDK | MLZ2012N100LT000 | $0.04250 | $0.04250 | On-Line |  | Digi-Key | 445-6762-1-ND | 445-6762-2-ND | LC0805
27 | 42-000071 | 1 | MOD1 | ATSAMA5D27-SOM1 | IC, Embedded Module ARM® Cortex®-A5 500MHz 1Gb (128K x 8) 64Mb Flash, 1Kb EEPROM | Microchip | ATSAMA5D27-SOM1 | $28.60000 | $28.60000 | Factory |  | Digi-Key | ATSAMA5D27-SOM1-ND |  | SAMA5D27_SOM1
28 | 42-000072 | 1 | U1 | MIC23451 | IC Buck Switching Regulator Positive Adjustable 1V 3 Output 2A | Microchip | MIC23451-AAAYFL-T5 | $1.8800 | $1.88000 | On-Line |  | Digi-Key | 576-4355-1-ND | 576-4355-2-ND | QFN26_4X4MM_2PADS
29 | 42-000076 | 2 | U4, U14 | NL17SZ125 | IC Buffer, Non-Inverting 1 Element 1 Bit per Element Push-Pull Output SOT23-5 | ON Semi | NL17SZ125DTT1G | $0.0747 | $0.14940 | On-Line |  | Digi-Key | NL17SZ125DTT1GOSCT-ND | NL17SZ125DTT1GOSTR-ND | SOT23-5
30 | 42-000082 | 1 | U3 | TCA9546A | IC I2C Bus Switch 2 x 1:4 16-TSSOP | Texas Instruments | TCA9546APWR | $0.54131 | $0.54131 | On-Line |  | Digi-Key | 296-40578-1-ND | 296-40578-2-ND | TSSOP16
31 | 42-000090 | 1 | U2 | TPS563208 | IC Buck Switching Regulator Positive Adjustable 0.768V 1 Output 3A SOT-23-6 | Texas Instruments | TPS563208DDCR | $0.68400 | $0.68400 | On-Line |  | Digi-Key | 296-44844-1-ND | 296-44844-2-ND | SOT23-6
32 | 42-000095 | 1 | U9 | MX25L25635 | IC FLASH - NAND Memory 256Mb (32M x 8) SPI 8-U-PDFN (8x6) | Macronix | MX25L25635FZ2I-10G | $4.61358 | $4.61358 | On-Line |  | Digi-Key | 1092-1150-ND |  | 8WSON_8X6
33 | 53-000021 | 1 | D1 | 5530121F | LED, Circuit Board Indicator 2, High Green / Red Diffused, Tinted 2.1V Green, 2V Red 10mA Round with Domed Top, 3mm (T-1) Through Hole, Right Angle | Dialight | 5530121F | $0.54600 | $0.54600 | On-Line |  | Digi-Key | 350-1822-ND |  | LED2T1_RT
34 | 57-000006 | 0 | TP28, TP81, TP82, TP130, TP131 |  | PCB Feature Test Point - 65mil Sq pad / 20mil drill |  |  | $0.00000 | $0.00000 | On-Line |  |  |  |  | TP_PTH65D20
35 | 57-000014 | 0 | MH1, MH2, MH3, MH4, MH5, MH6 |  | PCB Feature, Mounting Hole MH093PTH |  |  | $0.00000 | $0.00000 | On-Line |  |  |  |  | MH093PTH
36 | 57-000017 | 0 | TP1, TP2, TP3, TP4, TP5, TP6, TP7, TP8, TP9, TP10, TP11, TP12, TP13, TP14, TP15, TP16, TP17, TP18, TP19, TP20, TP21, TP22, TP23, TP24, TP25, TP26, TP27, TP29, TP30, TP31, TP32, TP33, TP34, TP35, TP36, TP37, TP38, TP39, TP40, TP41, TP42, TP43, TP44, TP45, TP46, TP47, TP48, TP49, TP50, TP51, TP52, TP53, TP54, TP55, TP56, TP57, TP58, TP59, TP60, TP61, TP62, TP63, TP64, TP65, TP66, TP67, TP68, TP69, TP70, TP71, TP72, TP73, TP74, TP75, TP76, TP77, TP78, TP79, TP80, TP83, TP84, TP89, TP90, TP91, TP92, TP93, TP94, TP95, TP96, TP97, TP98, TP99, TP100, TP101, TP102, TP103, TP104, TP105, TP106, TP107, TP108, TP109, TP110, TP111, TP112, TP113, TP114, TP115, TP116, TP117, TP118, TP119, TP120, TP121, TP122, TP123, TP124, TP125, TP126, TP127, TP128, TP129, TP132, TP133, TP134, TP135, TP136, TP137, TP138, TP139, TP140, TP141, TP142 |  | PCB Feature, Test point PTH .025" pad .012" drill |  |  | $0.00000 | $0.00000 | On-Line |  |  |  |  | PAD25RD12D
37 | 62-000012 | 3 | R75, R76, R98 | 0 | RES SMD 0.0OHM JUMPER 1/16W 0402 | Yageo | RC0402FR-070RL | $0.00255 | $0.00765 | On-Line |  | Digi-Key |  | 311-0.0LRTR-ND | RC0402A | Qty Change
 |  |  |  |  |  | PANASONIC | ERJ-2GE0R00X
38 | 62-000013 | 3 | R41, R60, R61 | 1K | RES SMD 1K OHM 1% 1/16W 0402 | Yageo | RC0402FR-071KL | $0.00127 | $0.00381 | On-Line |  | Digi-Key | 311-1.00KLRCT-ND | 311-1.00KLRTR-ND | RC0402A
39 | 62-000014 | 10 | R26, R89, R90, R91, R120, R121, R122, R123, R124, R135 | 100K | RES SMD 100K OHM 1% 1/16W 0402 | Yageo | RC0402FR-07100KL | $0.00127 | $0.01270 | On-Line |  | Digi-Key | 311-100KLRCT-ND | 311-100KLRTR-ND | RC0402A
40 | 62-000017 | 6 | R99, R100, R101, R102, R103, R104 | 49.9 | RES SMD 49.9 OHM 1% 1/16W 0402 | Yageo | RC0402FR-0749R9L | $0.00127 | $0.00762 | On-Line |  | Digi-Key | 311-49.9LRCT-ND | 311-49.9LRTR-ND | RC0402A
41 | 62-000041 | 28 | R2, R3, R4, R5, R6, R30, R36, R38, R39, R40, R42, R43, R45, R46, R47, R48, R49, R50, R62, R63, R77, R78, R79, R80, R109, R132, R133, R134 | 10K | Resistor Chip 10KOhm ±1% 1/16W 0402 Thick Film | Yageo | RC0402FR-0710KL | $0.00124 | $0.03472 | On-Line |  | Digi-Key | 311-10.0KLRCT-ND | 311-10.0KLRTR-ND | RC0402A
42 | 62-000042 | 1 | R1 | 20 | Resistor Chip 20 Ohm ±1% 1/16W 0402 Thick Film | Yageo | RC0402FR-0720RL | $0.00124 | $0.00124 | On-Line |  | Digi-Key | 311-20LRCT-ND | 311-20LRTR-ND | RC0402A
43 | 62-000043 | 6 | R51, R52, R53, R54, R55, R56 | 10 | Resistor Chip 10 Ohm ±1% 1/16W 0402 Thick Film | Yageo | RC0402FR-0710RL | $0.00127 | $0.00762 | On-Line |  | Digi-Key | 311-10.0LRCT-ND | 311-10.0LRTR-ND | RC0402A
44 | 62-000044 | 18 | R15, R64, R66, R67, R69, R70, R71, R72, R96, R115, R116, R117, R118, R119, R126, R127, R128, R130 | 100 | Resistor Chip 100 Ohm ±1% 1/16W 0402 Thick Film | Yageo | RC0402FR-07100RL | $0.00124 | $0.02232 | On-Line |  | Digi-Key | 311-100LRCT-ND | 311-100LRTR-ND | RC0402A
45 | 62-000045 | 4 | R73, R83, R88, R97 | 56K | Resistor Chip 56k Ohm ±1% 1/16W 0402 Thick Film | Yageo | RC0402FR-0756KL | $0.00138 | $0.00552 | On-Line |  | Digi-Key | 311-56.0KLRCT-ND | 311-56.0KLRTR-ND | RC0402A
46 | 62-000086 | 2 | R74, R110 | 54.9 KOhms | Resistor Chip 54.9 KOhms ±1% 1/16W 0402 Thick Film | Vishay Dale | CRCW040254K9FKED | $0.00454 | $0.00908 | On-Line |  | Digi-Key | 541-54.9KLCT-ND | 541-54.9KLTR-ND | RC0402A | Qty Change
47 | 62-000091 | 2 | R28, R29 | 2.00K | Resistor Chip 2 KOhms ±1% 1/16W 0402 Thick Film | Yageo | RC0402FR-072KL | $0.00158 | $0.00316 | On-Line |  | Digi-Key | 311-2KLRCT-ND | 311-2KLRTR-ND | RC0402A
48 | 62-000096 | 3 | R9, R10, R13 | 309K | Resistor Chip 309 KOhms ±1% 1/16W 0402 Moisture Resistant Thick Film | Yageo | RC0402FR-07309KL | $0.00122 | $0.00366 | On-Line |  | Digi-Key | YAG3108CT-ND | YAG3108TR-ND | RC0402A
49 | 62-000097 | 3 | R11, R12, R14 | 71.5K | Resistor Chip 71.5 KOhms ±1% 1/16W 0402 Moisture Resistant Thick Film | Yageo | RC0402FR-0771K5L | $0.00122 | $0.00366 | On-Line |  | Digi-Key | YAG3222CT-ND | YAG3222TR-ND | RC0402A
50 | 62-000103 | 2 | R7, R8 | 3.30K | Resistor Chip 3.3 KOhms ±1% 1/16W 0402 Moisture Resistant Thick Film | Yageo | RC0402FR-073K3L | $0.00158 | $0.00316 | On-Line |  | Digi-Key | 311-3.30KLRCT-ND | 311-3.30KLRTR-ND | RC0402A
51 | 62-000110 | 2 | R31, R32 | 75 | Resistor Chip 75 Ohms ±1% 1/16W 0402 Moisture Resistant Thick Film | Yageo | RC0402FR-0775RL | $0.00158 | $0.00316 | On-Line |  | Digi-Key | 311-75.0LRCT-ND | 311-75.0LRTR-ND | RC0402A
52 | 62-000114 | 4 | R23, R24, R25, R93 | 220 | Resistor Chip 220 Ohms ±1% 1/16W 0402 Thick Film | Yageo | RC0402FR-07220RL | $0.00158 | $0.00632 | On-Line |  | Digi-Key | 311-220LRCT-ND | 311-220LRTR-ND | RC0402A
53 | 77-000010 | 2 | S3,S4 |  | Switch Tactile SPST-NO Side Actuated Through Hole, Right Angle | Panasonic | EVQ-PF008K | $0.10585 | $0.21170 | On-Line |  | Digi-Key | P10880S-ND |  | SW_EVQ-PF008K
54 | 79-000002 | 1 | U8 | LAN 10/100 Base-T | MODULE XFRMR LAN 10/100B-TX SMD | Bel Fuse | S558-5999-U7-F | $1.08750 | $1.08750 | On-Line |  | Digi-Key | 507-1463-1-ND | 507-1463-2-ND | QBS001
55 | 87-000021 | 6 | Q1, Q2, Q3, Q4, Q5, Q6 |  | MOSFET N-Channel 50V 200mA 350mW SOT23-3 | ON Semi | BSS138L | $0.04391 | $0.26346 | On-Line |  | Digi-Key | BSS138LCT-ND | BSS138LTR-ND | SOT-23
56 | 87-000022 | 2 | Q7, Q8 | AO3407A | MOSFET P-Channel 30V 4.3A (Ta) 1.4W (Ta) SOT-23 | Alpha & Omega | AO3407A | $0.09315 | $0.18630 | On-Line |  | Digi-Key | 785-1006-1-ND | 785-1006-2-ND | SOT-23
57 | TP-PIN | 0 | FID1, FID2, FID3, FID4, FID5, FID6, FID7, FID8 |  |  |  |  | $0.00000 | $0.00000 |  |  |  |  |  | FIDUCIAL-GT
NEW | 62-000016 | 1 | R27A | 20.0K | RES SMD 20K OHM 1% 1/16W 0402 | Yageo | RC0402FR-0720KL | $0.00122 | $0.00122 | On-Line |  | Digi-Key | 311-20.0KLRCT-ND | 311-20.0KLRTR-ND | RC0402A | Place R27A on top of R27 (item1)
58 | 17-000006 | DNI | C28 | 10µF | CAP CER 10UF 6.3V X5R 0603 | Murata | GRM188R60J106ME47J |  |  |  |  | Digi-Key | 490-6405-1-ND | 490-6405-2-ND | CC0603
59 | 17-000054 | DNI | C26, C43, C44, C45, C46, C47, C48 | 100pF | Capacitor Ceramic 100pF ±5% 50V C0G, NP0 0402 | Murata | GRM1555C1H101JA01D |  |  |  |  | Digi-Key | 490-5922-1-ND | 490-5922-2-ND | CC0402A
60 | 17-000075 | DNI | C7, C16, C18, C21, C22, C65 | 0.1µF | CAP CER 0.1UF 16V X7R 0402 | Murata | GRM155R71C104KA88J |  |  |  |  | Digi-Key | 490-6328-1-ND | 490-6328-2-ND | CC0402A
61 | 17-000079 | DNI | C27 | 200mF | Super capacitor 200mF (EDLC) 3.3V Coin, Wide Terminals2 00 Ohm | Elna | DSK-3R3H204T614-H2L |  |  |  |  | Digi-Key | 604-1147-1-ND | 604-1147-2-ND | DSK-614
62 | 23-000004 | DNI | J8 |  | CONN HEADER VERT SGL 3POS GOLD | 3M | 961103-6404-AR |  |  |  |  | Digi-Key | 3M9448-ND |  | HDR100SIP3
63 | 23-000006 | DNI | JP1, JP2 |  | CONN HEADR BRKWAY .100 02POS R/A | TE | 9-146305-0-02 |  |  |  |  |  | A34265-02-ND |  | HEADER02
64 | 23-000026 | DNI | J9 |  | Connector Micro B USB 2.0 Receptacle 5 Position Surface Mount, Right Angle W Flange | Amphenol FCI | 10118192-0001LF |  |  |  |  | Digi-Key | 609-4613-1-ND | 609-4613-2-ND | 10118192
65 | 23-000030 | DNI | J1 |  | Connector Header 10 Positions 0.050" SMD Gold | Amphenol | 20021121-00010C4LF |  |  |  |  | Digi-Key | 609-3695-1-ND | 609-3695-2-ND | AMPHENOL_20021121-00010
66 | 23-000036 | DNI | J2 | CON4 | Connector Header 4 Positions 2.00mm Through Hole Tin | JST | B04B-PASK(LF)(SN) |  |  |  |  | Digi-Key | 455-1819-ND |  | B04B-PASK
67 | 23-000052 | DNI | J6, J7 | CON6 | 6 Positions Header Connector Through Hole | 3M | 961106-6404-AR |  |  |  |  | Digi-Key | 3M9457-06-ND |  | HDR100SIP6
68 | 23-000053 | DNI | J13 |  | 20 Position Header Connector 0.100" (2.54mm) Through Hole Tin | Sullins | PPTC102LFBN-RC |  |  |  |  | Digi-Key | S7078-ND |  | HDR20P2X10-FEMALE
69 | 23-000059 | DNI | J11 |  | CONN HEADER 10POS DUAL .05" SMD | Samtec Inc. | FTSH-105-01-F-DV-K |  |  |  |  | Digi-Key | SAM8796-ND |  | FTSH-105-01-F-DV-K | Changed
70 | 34-000023 | DNI | D7 | Schottky | Diode Array 1 Pair Common Cathode Schottky 30V 200mA SOT-23-3 | Diodes Inc | BAT54C-7-F |  |  |  |  | Digi-Key | BAT54C-FDICT-ND | BAT54C-FDITR-ND | SOT23
71 | 34-000024 | DNI | D3 | SDM160 | Diode Schottky 60V 1A SOD-123F | Diodes Inc | SDM160S1FQ-7 |  |  |  |  | Digi-Key | SDM160S1FQ-7DICT-ND | SDM160S1FQ-7DITR-ND | SOD-123F
72 | 41-000023 | DNI | L4, L10, L18 | BLM18 | FERRITE BEAD 180 OHM 0603 1LN | Murata | BLM18PG181SN1D |  |  |  |  | Digi-Key | 490-5263-1-ND | 490-5263-2-ND | 603
73 | 42-000077 | DNI | U5 | ATECC508A | IC Authentication Chip Networking and Communications 8-SOIC | Microchip | ATECC508A-SSHDA-T |  |  |  |  | Digi-Key | ATECC508A-SSHDA-TCT-ND | ATECC508A-SSHDA-TTR-ND | SOIC8
74 | 42-000078 | DNI | U13 | MIC2025 | IC DISTRIBUTION SW SGL 8-SOIC | Microchip | MIC2025-1YM-TR |  |  |  |  | Digi-Key | MIC2025-1YM-CT-ND | MIC2025-1YM-TR-ND | SOIC8
75 | 42-000096 | DNI | U9A | MX25L25673GM2 | IC FLASH - NAND Memory 256Mb (32M x 8) SPI 8SOIC (.208") | Macronix | MX25L25673GM2I-08G |  |  |  |  | Digi-Key | MX25L25673GM2I-08G-ND |  | SOIC08-200
76 | 62-000012 | DNI | R82, R85, R86, R87, R129 | 0 | RES SMD 0.0OHM JUMPER 1/16W 0402 | Yageo | RC0402FR-070RL |  |  |  |  | Digi-Key |  | 311-0.0LRTR-ND | RC0402A
77 | 62-000017 | DNI | R105, R106, R107, R108, R125 | 49.9 | RES SMD 49.9 OHM 1% 1/16W 0402 | Yageo | RC0402FR-0749R9L |  |  |  |  | Digi-Key | 311-49.9LRCT-ND | 311-49.9LRTR-ND | RC0402A
78 | 62-000028 | DNI | R33, R35 | 0 | RES SMD 0.0 OHM JUMPER 1/2W 1206 | Vishay Dale | CRCW12060000Z0EAHP |  |  |  |  | Digi-Key | 541-0.0UBCT-ND | 541-0.0UBTR-ND | RC1206
79 | 62-000041 | DNI | R16, R37, R44, R81, R94, R95, R131 | 10K | Resistor Chip 10KOhm ±1% 1/16W 0402 Thick Film | Yageo | RC0402FR-0710KL |  |  |  |  | Digi-Key | 311-10.0KLRCT-ND | 311-10.0KLRTR-ND | RC0402A
80 | 62-000042 | DNI | R84, R111, R112, R113 | 20 | Resistor Chip 20 Ohm ±1% 1/16W 0402 Thick Film | Yageo | RC0402FR-0720RL |  |  |  |  | Digi-Key | 311-20LRCT-ND | 311-20LRTR-ND | RC0402A
81 | 62-000043 | DNI | R57, R58, R59, R114 | 10 | Resistor Chip 10 Ohm ±1% 1/16W 0402 Thick Film | Yageo | RC0402FR-0710RL |  |  |  |  | Digi-Key | 311-10.0LRCT-ND | 311-10.0LRTR-ND | RC0402A
82 | 62-000044 | DNI | R34, R65, R68 | 100 | Resistor Chip 100 Ohm ±1% 1/16W 0402 Thick Film | Yageo | RC0402FR-07100RL |  |  |  |  | Digi-Key | 311-100LRCT-ND | 311-100LRTR-ND | RC0402A
83 | 62-000045 | DNI | R92 | 56K | Resistor Chip 56k Ohm ±1% 1/16W 0402 Thick Film | Yageo | RC0402FR-0756KL |  |  |  |  | Digi-Key | 311-56.0KLRCT-ND | 311-56.0KLRTR-ND | RC0402A
84 | 62-000100 | DNI | R17, R18, R19, R20, R21, R22 | 330 | Resistor Chip 330 Ohms ±1% 1/16W 0402 Thick Film | Yageo | RC0402FR-07330RL |  |  |  |  | Digi-Key | 311-330LRCT-ND | 311-330LRTR-ND | RC0402A
85 | 77-000008 | DNI | S1,S2 |  | Tactile Switch SPST-NO Top Actuated SMD | C&K | PTS645SM43SMTR92 LFS |  |  |  |  | Digi-Key | CKN9112CT-ND | CKN9112TR-ND | SW_PTS645
85 | 14-742905rA | 1 | PCB |  | PCB, 12.6" X 4.33" X 0.062", 4 layer, 1 Oz Cu, FR4 |  | 742905rA | $15.00000 | $15.00000 | est | 5760
 |  |  |  |  |  |  |  |  | $66.30877
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

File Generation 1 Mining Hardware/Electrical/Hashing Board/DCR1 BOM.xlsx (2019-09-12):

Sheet: Rev02.3
Obelisk Blake256 Decred (DCR1) Hashing Board Production Release
Client: | Obelisk
Project: | Blake2Miner
Date: | 2018-06-28
Assemby | 742909
Revision: | 2.3
Build | 11000
Job | 6009
Item | TechEn P/N | Qty | Reference | Schematic Value | Part Description | Manufacturer | MFG Part number | Vendor | Vendor Part Number | Vendor Part Number | Footprint | Comments
1 | 17-000013 | 60 | C55, C56, C57, C58, C59, C60, C61, C62, C63, C64, C65, C66, C85, C86, C87, C88, C107, C108, C109, C110, C129, C130, C131, C132, C151, C152, C153, C154, C173, C174, C175, C176, C195, C196, C197, C198, C217, C218, C219, C220, C239, C240, C241, C242, C261, C262, C263, C264, C283, C284, C285, C286, C305, C306, C307, C308, C332, C333, C334, C335 | 10000pF | CAP CER 10000PF 16V X7R 0402 | Kemet | C0402C103J4RACTU | Digi-Key | 399-1039-1-ND | 399-1039-2-ND | CC0402A
 |  |  |  |  |  | Murata | GCM155R71H103KA55D
 |  |  |  |  |  | AVX Corporation | 0402YC103MAT2A
 |  |  |  |  |  | Murata | GCM155R71E103KA37D
2 | 17-000014 | 1 | C417 | 1µF | CAP CER 1UF 16V X5R 0402 | Kemet | C0402C105K4PAC7867 | Digi-Key | 399-12289-1-ND | 399-12289-2-ND | CC0402A
 |  |  |  |  |  | AVX | CGB2A1X5R1E105K033BC
3 | 17-000015 | 14 | C403, C404, C405, C406, C407, C408, C409, C410, C411, C412, C413, C414, C415, C416 | 1000pF | CAP CER 1000PF 16V X7R 0402 | Kemet | C0402C102J4RACTU | Digi-Key | 399-7753-1-ND | 399-7753-2-ND | CC0402A
 |  |  |  |  |  | Samsung | CL05B102KO5NNNC
 |  |  |  |  |  | Kemet | C0402C102J3GACTU
4 | 17-000018 | 1 | C345 | 10µF | CAP CER 10UF 16V X5R 0603 | Murata | GRM188R61C106MA73D | Digi-Key | 490-7201-1-ND | 490-7201-2-ND | CC0603
 |  |  |  |  |  | Taiyo Yuden | EMK107BBJ106MA-T
5 | 17-000025 | 2 | C314, C338 | 0.10µF | CAP CER 0.1UF 25V X7R 0603 | TDK Corporation | C1608X7R1E104K080AA | Digi-Key | 445-1316-1-ND | 445-1316-2-ND | CC0603 | Qty Change
 |  |  |  |  |  | TDK | CGJ3E2X7R1C104K080AA
6 | 17-000029 | 2 | C309, C385 | 1µF | CAP CER 1UF 25V X5R 0603 | TDK | C1608X5R1E105K080AC | Digi-Key | 445-5146-1-ND | 445-5146-2-ND | CC0603
 |  |  |  |  |  | TDK | C1608X7R1E105K080AB
7 | 17-000036 | 2 | C310, C350 | 0.1UF | CAP CER 0.1UF 25V X7R 0603 | Murata | GRM188R71E104KA01D | Digi-Key | 490-1524-1-ND | 490-1524-2-ND | CC0603
 |  |  |  |  |  | TDK | CGJ3E2X7R1C104K080AA
8 | 17-000043 | 3 | C377, C378, C379 | 1000pF | CAP CER 1000PF 16V X7R 0603 | KEMET | C0603C102K4RACTU | Digi-Key | 399-7835-1-ND | 399-7835-2-ND | 603
 |  |  |  |  |  | Murata | GRM188R71H102KA01D
9 | 17-000053 | 1 | C384 | 1000pF | Capacitor Ceramic 1000pF ±10% 50V X7R 0402 | Murata | GRM155R71H102KA01D | Digi-Key | 490-1303-1-ND | 490-1303-2-ND | CC0402A
 |  |  |  |  |  | TDK | C1005X7R1E102K050BA
 |  |  |  |  |  | TDK | CGA2B2X7R1H102K050BE
10 | 17-000073 | 17 | C1, C2, C3, C67, C89, C111, C133, C155, C177, C199, C221, C243, C265, C287, C311, C346, C370 | 10µF | Capacitor Ceramic 10µF ±20% 16V X7R 0805 | Taiyo Yuden | EMK212BB7106MG-T | Digi-Key | 587-3319-1-ND | 587-3319-2-ND | 805
 |  |  |  |  |  | Kemet | C0805C106M4PACTU
 |  |  |  |  |  | TDK | C2012X6S1C106M085AC
11 | 17-000074 | 36 | C4, C5, C6, C7, C8, C9, C68, C69, C90, C91, C112, C113, C134, C135, C156, C157, C178, C179, C200, C201, C222, C223, C244, C245, C266, C267, C288, C289, C312, C313, C371, C372, C373, C374, C375, C376 | 1µF | Capacitor Ceramic 1µF ±10% 16V X7R 0603 | AVX | 0603YC105KAT2A | Digi-Key | 478-5010-1-ND | 478-5010-2-ND | CC0603
 |  |  |  |  |  | TDK | C1608X7R1E105K080AB
 |  |  |  |  |  | Taiyo Yuden | TMK107B7105KA-T
 |  |  |  |  |  | Kemet | C0603X105M4RAC7411
12 | 17-000086 | 51 | C12, C13, C16, C17, C20, C21, C72, C73, C94, C95, C116, C117, C138, C139, C160, C161, C182, C183, C204, C205, C226, C227, C248, C249, C270, C271, C292, C293, C319, C320, C348, C349, C351, C352, C353, C354, C355, C356, C357, C358, C359, C360, C361, C362, C363, C364, C365, C366, C367, C368, C369 | 0.1µF | CAP CER 0.1UF 10V X7R 0603 | KEMET | C0603X104K8RACTU | Digi-Key | 399-5343-1-ND | 399-5343-2-ND | CC0603
 |  |  |  |  |  | TDK | CGJ3E2X7R1C104K080AA
 |  |  |  |  |  | Vishay | C1608X8R1E104K080AA
 |  |  |  |  |  | Murata | CL10B104KO8NNND
 |  |  |  |  |  | Murata | GCM188R71C104KA37D
13 | 17-000087 | 61 | C22, C23, C27, C28, C33, C37, C38, C43, C46, C47, C51, C52, C76, C77, C81, C82, C98, C99, C103, C104, C120, C121, C125, C126, C142, C143, C147, C148, C164, C165, C169, C170, C186, C187, C191, C192, C208, C209, C213, C214, C230, C231, C235, C236, C252, C253, C257, C258, C274, C275, C279, C280, C296, C297, C301, C302, C323, C324, C329, C330, C402 | 0.1µF | CAP CER 0.1UF 10V X7R 0402 | KEMET | C0402C104J8RACTU | Digi-Key | 399-8942-1-ND | 399-8942-2-ND | CC0402A
 |  |  |  |  |  | Murata | GCM155R71C104KA55D
14 | 17-000115 | 1 | C340 | 1500pF | Capacitor Ceramic 1500pF 50V C0G, NP0 0603 | KEMET | C0603C152J5GACTU | Digi-Key | 399-9010-1-ND | 399-9010-2-ND | CC0603 | NEW
 |  |  |  |  |  | Murata | GCM1885C1H152JA16D
15 | 17-000089 | 1 | C341 | 390PF | CAP CER 390PF 50V C0G/NP0 0603 | SAMSUNG | CL10C391JB8NNNC | Digi-Key | 1276-1297-1-ND | 1276-1297-2-ND | CC0603
16 | 17-000091 | 2 | C382, C383 | 0.1UF | CAP CER 0.1UF 25V X7R 0805 | KEMET | C0805C104K3RACTU | Digi-Key | 399-1168-1-ND | 399-1168-2-ND | CC0805
 |  |  |  |  |  | Murata | GRM21BR71E104KA01L
17 | 17-000100 | 2 | C387, C388 | 270UF | CAP ALUM POLY 270UF 20% 25V SMD | Nichicon | PCV1E271MCL2GS | Digi-Key | 493-4543-1-ND | 493-4543-2-ND | RAD10MM
18 | 17-000101 | 4 | C389, C390, C391, C392 | 22UF | CAP CER 22UF 25V X7R 1210 | Taiyo Yuden | TMK325B7226MM-TR | Digi-Key | 587-2784-1-ND | 587-2784-2-ND | CC1210
 |  |  |  |  |  | Taiyo Yuden | TMK325BJ226MM-T
19 | 17-000103 | 1 | C393 | 0.056uF | CAP CER 0.056UF 6.3V X7R 0402 | KEMET | C0402C563K9RACTU | Digi-Key | 399-4903-1-ND | 399-4903-2-ND | CC0402A
20 | 17-000105 | 1 | C397 | 4.7UF | CAP CER 4.7UF 16V X7R 0805 | TDK Corporation | CGA4J1X7R1C475K125AC | Digi-Key | 445-12738-1-ND | 445-12738-2-ND | CC0805
 |  |  |  |  |  | Taiyo Yuden | TMK212AB7475KG-T
 |  |  |  |  |  | Kemet | C0805X475J4RACAUTO
21 | 17-000107 | 2 | C400, C401 | 470UF | CAP ALUM POLY 470UF 20% 16V SMD | Wurth Electronics Inc. | 875115000000 | Digi-Key | 732-6461-1-ND | 732-6461-2-ND | RAD10MM
 |  |  |  |  |  | Nichicon | PCG1C471MCL1GS
22 | 17-000108 | 1 | C380 | 100PF | CAP CER 100PF 50V X7R 0402 | KEMET | C0402C101K5RAC7867 | Digi-Key | 399-15291-1-ND | 399-15291-2-ND | CC0402A
 |  |  |  |  |  | Kemet | C0402C101K5RACAUTO
23 | 17-000109 | 1 | C396 | 56pF | CAP CER 56PF 50V C0G/NPO 0402 | Yageo | CC0402JRNPO9BN560 | Digi-Key | 311-1022-1-ND | 311-1022-2-ND | CC0402A
24 | 17-000110 | 2 | C315, C316 | 1000PF | CAP CER 1000PF 25V C0G/NP0 0603 | KEMET | C0603C102K3GACTU | Digi-Key | 399-7833-1-ND | 399-7833-2-ND | CC0603
25 | 17-000111 | 2 | C394, C395 | 220pF | CAP CER 220PF 25V X7R 0402 | KEMET | C0402C221K3RAC7867 | Digi-Key | 399-15311-1-ND | 399-15311-2-ND | CC0402A
26 | 23-000038 | 2 | J1, J2 |  | Connector Header 6 Positions 0.165" Through Hole, Right Angle Tin | Molex | 455580003 | Digi-Key | WM10869-ND |  | M455580003
27 | 23-000047 | 1 | J3 |  | Connector DIN 41612 Male 32Pin RtAng | Molex | 850010012 | Digi-Key | WM3570-ND |  | M0850010012
 |  |  |  |  |  | Harting | 9221326921
 |  |  |  |  |  | TE | 5536053-5
28 | 34-000025 | 1 | D78 | SCHOTTKY | DIODE SCHOTTKY 40V 1A SOD123 | DIODES INC | 1N5819HW-7-F | Digi-Key | 1N5819HW-FDICT-ND | 1N5819HW-FDITR-ND | SOD123_12
29 | 34-000027 | 78 | D1, D2, D3, D4, D5, D6, D7, D8, D9, D10, D11, D12, D13, D14, D15, D16, D17, D18, D19, D20, D21, D22, D23, D24, D25, D26, D27, D28, D29, D30, D31, D32, D33, D34, D35, D36, D37, D38, D39, D40, D41, D42, D43, D44, D45, D46, D47, D48, D49, D50, D51, D52, D53, D54, D55, D56, D57, D58, D59, D60, D61, D62, D63, D64, D65, D66, D67, D68, D69, D70, D71, D72, D73, D74, D75, D79, D80, D81 | Schottky | DIODE ARRAY SCHOTTKY 30V SOT323 | Nexperia | BAT54SW,115 | Digi-Key | 1727-2905-1-ND | 1727-2905-2-ND | SC-70
30 | 34-000028 | 1 | D76 | Standard | DIODE ARRAY GP 75V 300MA SOT23-3 | Diodes Inc | BAV99-7-F | Digi-Key | BAV99-FDICT-ND | BAV99-FDITR-ND | SOT23
31 | 41-000024 | 3 | FB1, FB2, FB3 | 120 Ohms @ 100MHz | FERRITE BEAD 120 OHM 0804 4LN | Murata | BLA2AAG121SN4D | Digi-Key | 490-4006-1-ND | 490-4006-2-ND | FB_BLA2AA_4LN
 |  |  |  |  |  | Panasonic | EXC-28BB121U
32 | 41-000036 | 1 | L1 | 1.0uH | Inductor 1µH Shielded Molded 48A 1.38 mOhm Max Nonstandard | Vishay Dale | IHLP6767GZER1R0M01 | Digi-Key | 541-1250-1-ND | 541-1250-2-ND | L_IHLP6767
 |  |  |  |  |  | Vishay Dale | IHLP6767GZER1R0M51
33 | 42-000058-32 | 15 | U1, U2, U3, U4, U5, U6, U7, U8, U9, U10, U11, U12, U13, U14, U15 |  | Custom ASIC, BLAKE256, Decred | CSS | BLAKE256 | Custom | NA |  | BGA144C80P12X12_1100X1100X140A
34 | 42-000062 | 1 | U18 |  | IC Voltage Level Translator Bidirectional 2 Circuit 2 Channel 380Mbps 16-TSSOP | Nexperia | 74AVC4T245PW,118 | Digi-Key | 1727-6573-1-ND | 1727-6573-2-ND | TSSOP16-4.4MM
 |  |  |  |  |  | TI | SN74AVC4T245PWR
35 | 42-000063 | 6 | U19, U20, U21, U22, U23, U24 |  | IC Voltage Level Translator Bidirectional 1 Circuit 8 Channel 380Mbps 24-TSSOP | Nexperia | 74AVC8T245PW,118 | Digi-Key | 1727-4181-1-ND | 1727-4181-2-ND | TSSOP24-4.4mm
 |  |  |  |  |  | TI | SN74AVC8T245PWR
36 | 42-000065 | 1 | U36 |  | IC AND Gate IC 1 Channel 5-TSSOP | Nexperia | 74LVC1G08GV,125 | Digi-Key | 1727-4115-1-ND | 1727-4115-2-ND | SC-74A
37 | 42-000066 | 1 | U35 | MCP4017 | IC Digital Potentiometer 5k Ohm 1 Circuit 128 Taps I²C SC-70-6 | Microchip | MCP4017T-502E/LT | Digi-Key | MCP4017T-502E/LTCT-ND | MCP4017T-502E/LTTR-ND | SC-70-6
38 | 42-000070 | 1 | U16 |  | IC General Purpose Amplifier 1 Circuit Rail-to-Rail SOT-23-5 | Texas Instruments | LM7321MF/NOPB | Digi-Key | LM7321MF/NOPBCT-ND | 296-35181-2-ND | SOT23-5
39 | 42-000080 | 2 | U25, U26 |  | IC GATE AND 4CH 2-INP 14-SO | Nexperia | 74LVC08AD,118 | Digi-Key | 1727-3078-2-ND | 1727-3078-1-ND | SOIC14
 |  |  |  |  |  | TI | SN74LVC08ADR
40 | 42-000083 | 3 | U27, U28, U29 |  | IC I/O EXPANDER SPI 16B 28SOIC | Microchip | MCP23S17T-E/SO | Digi-Key | MCP23S17T-E/SOTR-ND |  | SOIC28-W_MC
41 | 42-000085 | 1 | U30 |  | IC REG LIN POS ADJ 1A UDFN3030-8 | DIODES INC | AP7361C-FGE-7 | Digi-Key | AP7361C-FGE-7DITR-ND |  | UDFN3030-8
42 | 42-000086 | 1 | U31 |  | IC INVERTER HEX 1-INPUT 14SOIC | Texas Instrument | SN74LVC04ADRG3 | Digi-Key | 296-27875-1-ND |  | SOIC14
 |  |  |  |  |  | Nexperia | 74LVC04AD,118
 |  |  |  |  |  | ON Semiconductor | 74LVC04ADTR2G
43 | 42-000087 | 1 | U32 |  | IC 3-8 DECOD/DEMUX INV 16-TSSOP | Nexperia | 74LVC138APW,118 | Digi-Key | 1727-4026-1-ND | 1727-4026-2-ND | TSSOP16-4.4MM
 |  |  |  |  |  | TI | SN74LVC138APWR
44 | 42-000091 | 1 | U17 |  | IC TRIPLE TEMP SENSOR 10VDFN | Microchip Technology | MCP9903T-AE/9Q | Digi-Key | MCP9903T-AE/9QCT-ND | MCP9903T-AE/9QTR-ND | VFDN10_3X3MM
45 | 42-000092 | 1 | U33 |  | IC ADC 12BIT I2C INTRFC 10QFN | Texas Instrument | ADS1015IRUGT | Digi-Key | 296-25172-1-ND | 296-25172-2-ND | X2QFN10
46 | 42-000093 | 1 | U34 |  | IC REG CTRLR BUCK 20VQFN | Texas Instruments | TPS40170RGYR | Digi-Key | 296-37672-1-ND | 296-37672-2-ND | VQFN20TI
 |  |  |  |  |  | TI | TPS40170RGYT
 |  |  |  |  |  | TI | TPS40170QRGYRQ1
47 | 42-000094 | 1 | U37 |  | IC EEPROM 2KBIT 400KHZ SOT23-5 | Microchip Technology | 24AA02UIDT-I/OT | Digi-Key | 24AA02UIDT-I/OTCT-ND | 24AA02UIDT-I/OTTR-ND | SOT23-5
48 | 57-000004 | 0 | TP1, TP2, TP3, TP4, TP5, TP6, TP7, TP8, TP9, TP10, TP11, TP12, TP13, TP14, TP15, TP16, TP17, TP18, TP19, TP20, TP21, TP22, TP23, TP24, TP25, TP26, TP27, TP28, TP29, TP30, TP31, TP32, TP33, TP34, TP35, TP36, TP37, TP38, TP39, TP40, TP41, TP42, TP43, TP44, TP45, TP46, TP47, TP48, TP49, TP50, TP51, TP52, TP53, TP54, TP55, TP56, TP57, TP58, TP59, TP60, TP61, TP62, TP63, TP64, TP65, TP66, TP67, TP68, TP69, TP70, TP71, TP72, TP73, TP74, TP75, TP76, TP77, TP78, TP79, TP80, TP81, TP82, TP83, TP84, TP85, TP86, TP87, TP88, TP89, TP90, TP91, TP92, TP93, TP94, TP95, TP96, TP97, TP98, TP99, TP100, TP101, TP102, TP103, TP104, TP105, TP106, TP107, TP108, TP109, TP110, TP111, TP112, TP113, TP114, TP115, TP116, TP117, TP118, TP119, TP120, TP121, TP122, TP123, TP124, TP125, TP126, TP127, TP128, TP129, TP130, TP131, TP132, TP133, TP134, TP135, TP136, TP137, TP138, TP139, TP140 |  | PCB Feature, Test Point, SMD, Round 40mil |  |  |  |  |  | PAD40RD
49 | 62-000002 | 1 | R36 | 100 | RES SMD 100 OHM 1% 1/10W 0603 | Yageo | RC0603FR-07100RL | Digi-Key | 311-100HRCT-ND | 311-100HRTR-ND | RC0603
 |  |  |  |  |  | Panasonic | ERJ-3EKF1000V
50 | 62-000008 | 1 | R254 | 10K | RES SMD 10K OHM 1% 1/10W 0603 | Yageo | RC0603FR-0710KL | Digi-Key | 311-10.0KHRCT-ND | 311-10.0KHRTR-ND | RC0603
51 | 62-000009 | 1 | R45 | 1K | RES SMD 1K OHM 1% 1/10W 0603 | Yageo | RC0603FR-071KL | Digi-Key | 311-1.00KHRCT-ND | 311-1.00KHRTR-ND | RC0603
 |  |  |  |  |  | Panasonic | ERJ-3EKF1001V
52 | 62-000012 | 7 | R429, R450, R451, R452, R453, R488, R512 | 0 | RES SMD 0.0OHM JUMPER 1/16W 0402 | Yageo | RC0402FR-070RL | Digi-Key |  | 311-0.0LRTR-ND | RC0402A
 |  |  |  |  |  | Panasonic | ERJ-2GE0R00X
53 | 62-000013 | 32 | R55, R56, R57, R58, R59, R60, R100, R101, R127, R128, R154, R155, R181, R182, R208, R209, R235, R236, R262, R263, R289, R290, R316, R317, R343, R344, R370, R371, R402, R403, R424, R481 | 1K | RES SMD 1K OHM 1% 1/16W 0402 | Yageo | RC0402FR-071KL | Digi-Key | 311-1.00KLRCT-ND | 311-1.00KLRTR-ND | RC0402A
54 | 62-000014 | 76 | R63, R64, R65, R66, R67, R70, R71, R72, R73, R74, R77, R78, R79, R80, R81, R104, R105, R106, R107, R108, R131, R132, R133, R134, R135, R156, R159, R160, R161, R162, R183, R186, R187, R188, R189, R210, R213, R214, R215, R216, R239, R240, R241, R242, R243, R264, R267, R268, R269, R270, R291, R294, R295, R296, R297, R318, R319, R320, R321, R322, R347, R348, R349, R350, R351, R372, R375, R376, R377, R378, R404, R407, R408, R409, R410, R486 | 100K | RES SMD 100K OHM 1% 1/16W 0402 | Yageo | RC0402FR-07100KL | Digi-Key | 311-100KLRCT-ND | 311-100KLRTR-ND | RC0402A
 |  |  |  |  |  | Panasonic | ERJ-2RKF1003X
55 | 62-000016 | 15 | R436, R439, R440, R441, R442, R443, R444, R445, R464, R465, R466, R469, R490, R504, R505 | 20K | RES SMD 20K OHM 1% 1/16W 0402 | Yageo | RC0402FR-0720KL | Digi-Key | 311-20.0KLRCT-ND | 311-20.0KLRTR-ND | RC0402A
 |  |  |  |  |  | Panasonic | ERJ-2RKF2002X
56 | 62-000017 | 1 | R457 | 49.9 | RES SMD 49.9 OHM 1% 1/16W 0402 | Yageo | RC0402FR-0749R9L | Digi-Key | 311-49.9LRCT-ND | 311-49.9LRTR-ND | RC0402A
57 | 62-000037 | 2 | R245, R246 | 19.1K | RES SMD 19.1K OHM 1% 1/10W 0603 | Panasonic | ERJ-3EKF1912V | Digi-Key | P19.1KHCT-ND | P19.1KHTR-ND | 603
58 | 62-000040 | 1 | R485 | 4.99K | Resistor Chip 4.99K Ohm ±1% 1/16W 0402 Thick Film | Yageo | RC0402FR-074K99L | Digi-Key | 311-4.99KLRCT-ND | 311-4.99KLRTR-ND | RC0402A
59 | 62-000041 | 38 | R20, R21, R23, R24, R26, R27, R89, R90, R116, R117, R142, R143, R169, R170, R196, R197, R224, R225, R250, R251, R277, R278, R305, R306, R332, R333, R358, R359, R389, R390, R421, R423, R428, R435, R479, R480, R482, R506 | 10K | Resistor Chip 10KOhm ±1% 1/16W 0402 Thick Film | Yageo | RC0402FR-0710KL | Digi-Key | 311-10.0KLRCT-ND | 311-10.0KLRTR-ND | RC0402A | Qty Change
 |  |  |  |  |  | Panasonic | ERJ-2RKF1002X
60 | 62-000042 | 4 | R446, R447, R448, R449 | 20 | Resistor Chip 20 Ohm ±1% 1/16W 0402 Thick Film | Yageo | RC0402FR-0720RL | Digi-Key | 311-20LRCT-ND | 311-20LRTR-ND | RC0402A
61 | 62-000043 | 12 | R392, R411, R412, R413, R414, R430, R431, R432, R433, R434, R491, R492 | 10 | Resistor Chip 10 Ohm ±1% 1/16W 0402 Thick Film | Yageo | RC0402FR-0710RL | Digi-Key | 311-10.0LRCT-ND | 311-10.0LRTR-ND | RC0402A
62 | 62-000044 | 113 | R28, R29, R30, R31, R32, R33, R34, R35, R38, R39, R40, R41, R42, R43, R44, R46, R48, R49, R50, R51, R52, R53, R61, R68, R75, R93, R94, R95, R96, R97, R98, R102, R118, R119, R121, R122, R123, R124, R125, R129, R145, R148, R150, R151, R152, R153, R157, R172, R174, R177, R178, R179, R180, R184, R199, R204, R205, R206, R207, R211, R226, R227, R228, R230, R231, R232, R233, R237, R253, R256, R257, R259, R260, R261, R265, R280, R282, R284, R286, R287, R288, R292, R307, R311, R313, R314, R315, R323, R334, R336, R337, R340, R341, R342, R345, R361, R364, R367, R368, R369, R373, R393, R395, R399, R400, R401, R405, R419, R425, R426, R427, R503, R507 | 100 | Resistor Chip 100 Ohm ±1% 1/16W 0402 Thick Film | Yageo | RC0402FR-07100RL | Digi-Key | 311-100LRCT-ND | 311-100LRTR-ND | RC0402A | QTY CHANGE
 |  |  |  |  |  | Panasonic | ERJ-2RKF1000X
63 | 62-000074 | 9 | R415, R416, R417, R418, R437, R438, R459, R460, R474 | 200K | Resistor Chip 200KOhm ±1%, 1/16W 0402 Thick Film | Yageo | RC0402FR-07200KL | Digi-Key | 311-200KLRCT-ND | 311-200KLRTR-ND | RC0402A
64 | 62-000075 | 45 | R10, R11, R12, R13, R14, R15, R16, R17, R18, R85, R86, R87, R112, R113, R114, R139, R140, R141, R166, R167, R168, R193, R194, R195, R220, R221, R222, R247, R248, R249, R274, R275, R276, R301, R302, R303, R328, R329, R330, R355, R356, R357, R386, R387, R388 | 1 MOhms | Resistor Chip 1 MOhms ±1% 1/16W 0402 Thick Film | Yageo | RC0402FR-071ML | Digi-Key | 311-1.00MLRCT-ND | 311-1.00MLRTR-ND | RC0402A
 |  |  |  |  |  | Panasonic | ERJ-2RKF1004X
65 | 62-000088 | 1 | R468 | 1.5K | Resistor Chip 1.5 KOhms ±1% 1/16W 0402 Thick Film | Yageo | RC0402FR-071K5L | Digi-Key | 311-1.50KLRCT-ND | 311-1.50KLRTR-ND | RC0402A
 |  |  |  |  |  | Panasonic | ERJ-2RKF1501X
66 | 62-000091 | 1 | R467 | 2.00K | Resistor Chip 2 KOhms ±1% 1/16W 0402 Thick Film | Yageo | RC0402FR-072KL | Digi-Key | 311-2KLRCT-ND | 311-2KLRTR-ND | RC0402A
 |  |  |  |  |  | Panasonic | ERJ-2RKF2001X
67 | 62-000093 | 3 | R379, R380, R381 | 2.74 KOhms | Resistor Chip 2.74 KOhms ±1% 1/16W 0402 Thick Film | Yageo | RC0402FR-072K74L | Digi-Key | YAG3104CT-ND | YAG3104TR-ND | RC0402A
 |  |  |  |  |  | Panasonic | ERJ-2RKF2741X
68 | 62-000106 | 8 | RN1, RN2, RN3, RN4, RN5, RN6, RN7, RN8 | 0R | RES ARRAY 4 RES ZERO OHM 1206 | Panasonic | EXB-V8VR000V | Digi-Key | Y4000TR-ND |  | EXBV8_4R
 |  |  |  |  |  | Bourns | CAY16-000J4LF
69 | 62-000107 | 2 | R4, R5 | 1.5K | RES SMD 1.5K OHM 1% 1/10W 0603 | Yageo | RC0603FR-071K5L | Digi-Key | 311-1.50KHRTR-ND |  | RC0603A
70 | 62-000115 | 3 | R461, R462, R463 | 60.4 kOhms | RES SMD 60.4K OHM 1% 1/16W 0402 | Yageo | RC0402FR-0760K4L | Digi-Key | 311-60.4KLRCT-ND | 311-60.4KLRTR-ND | RC0402A
71 | 62-000118 | 1 | R477 | 48.7K | Resistor Chip 48.7 KOhms ±1% 1/16W 0402 Thick Film | Yageo | RC0402FR-0748K7L | Digi-Key | YAG3169CT-ND | YAG3169TR-ND | 402
72 | 62-000120 | 2 | R470, R471 | 22.1 kOhms | RES SMD 22.1K OHM 1% 1/16W 0402 | Yageo | RC0402FR-0722K1L | Digi-Key | 311-22.1KLRCT-ND | 311-22.1KLRTR-ND | RC0402A
73 | 62-000121 | 2 | R475, R478 | 35.7K | RES SMD 35.7K OHM 1% 1/10W 0402 | PANASONIC | ERJ-2RKF3572X | Digi-Key | P35.7KLCT-ND | P35.7KLTR-ND | RC0402A
74 | 62-000123 | 1 | R487 | 12.1K | RES SMD 12.1K OHM 1% 1/16W 0402 | Yageo | RC0402FR-0712K1L | Digi-Key | 311-12.1KLRCT-ND | 311-12.1KLRTR-ND | RC0402A
75 | 62-000124 | 1 | R476 | 7.50K | RES SMD 7.5K OHM 1% 1/16W 0402 | Yageo | RC0402FR-077K5L | Digi-Key | 311-7.50KLRCT-ND | 311-7.50KLRTR-ND | RC0402A
76 | 62-000127 | 2 | R8, R9 | 5.49K | Resistor Chip 5.49 KOhms ±1% 1/10W 0603 Thick Film | Yageo | RC0603FR-075K49L | Digikey | 311-5.49KHRCT-ND | 311-5.49KHRTR-ND | RC0603
 |  |  |  |  |  | Panasonic | ERJ-2RKF5491X
77 | 62-000128 | 2 | R83, R84 | 7.32K | Resistor Chip 7.32 KOhms ±1% 1/10W 0603 Thick Film | Yageo | RC0603FR-077K32L | Digikey | 311-7.32KHRCT-ND | 311-7.32KHRTR-ND | RC0603
78 | 62-000131 | 2 | R137, R138 | 11.0K | Resistor Chip 11.0 KOhms ±1% 1/10W 0603 Thick Film | Yageo | RC0603FR-0711KL | Digikey | 311-11.0KHRCT-ND | 311-11.0KHRTR-ND | RC0603
79 | 62-000133 | 2 | R164, R165 | 13.0K | Resistor Chip 13.0 KOhms ±1% 1/10W 0603 Thick Film | Yageo | RC0603FR-0713KL | Digikey | 311-13.0KHRCT-ND | 311-13.0KHRTR-ND | RC0603
 |  |  |  |  |  | Panasonic | ERJ-2RKF1302X
80 | 62-000134 | 3 | R191, R192, R362 | 15.0K | Resistor Chip 15.0 KOhms ±1% 1/10W 0603 Thick Film | Yageo | RC0603FR-0715KL | Digikey | 311-15.0KHRCT-ND | 311-15.0KHRTR-ND | RC0603
81 | 62-000135 | 2 | R218, R219 | 16.9K | Resistor Chip 16.9 KOhms ±1% 1/10W 0603 Thick Film | Yageo | RC0603FR-0716K9L | Digikey | 311-16.9KHRCT-ND | 311-16.9KHRTR-ND | RC0603
 |  |  |  |  |  | Panasonic | ERJ-2RKF1692X
82 | 62-000138 | 2 | R272, R273 | 21.0K | Resistor Chip 21.0 KOhms ±1% 1/10W 0603 Thick Film | Yageo | RC0603FR-0721KL | Digikey | 311-21.0KHRCT-ND | 311-21.0KHRTR-ND | RC0603
83 | 62-000139 | 2 | R299, R300 | 22.6K | Resistor Chip 22.6 KOhms ±1% 1/10W 0603 Thick Film | Yageo | RC0603FR-0722K6L | Digikey | 311-22.6KHRCT-ND | 311-22.6KHRTR-ND | RC0603
84 | 62-000141 | 2 | R326, R327 | 24.9K | Resistor Chip 24.9 KOhms ±1% 1/10W 0603 Thick Film | Yageo | RC0603FR-0724K9L | Digikey | 311-24.9KHRCT-ND | 311-24.9KHRTR-ND | RC0603
85 | 62-000142 | 2 | R353, R354 | 26.7K | Resistor Chip 26.7 KOhms ±1% 1/10W 0603 Thick Film | Yageo | RC0603FR-0726K7L | Digikey | 311-26.7KHRCT-ND | 311-26.7KHRTR-ND | RC0603
 |  |  |  |  |  | Panasonic | ERJ-2RKF2672X
86 | 62-000144 | 2 | R383, R384 | 28.7K | Resistor Chip 28.7 KOhms ±1% 1/10W 0603 Thick Film | Yageo | RC0603FR-0728K7L | Digikey | 311-28.7KHRCT-ND | 311-28.7KHRTR-ND | RC0603
 |  |  |  |  |  | Panasonic | ERJ-2RKF2872X
87 | 62-000147 | 1 | R54 | 2.32K | Resistor Chip 2.32 KOhms ±1% 1/10W 0603 Thick Film | Yageo | RC0603FR-072K32L | Digikey | 311-2.32KHRCT-ND | 311-2.32KHRTR-ND | RC0603
88 | 62-000148 | 3 | R6, R7, R99 | 3.48K | Resistor Chip 3.48 KOhms ±1% 1/10W 0603 Thick Film | Yageo | RC0603FR-073K48L | Digikey | 311-3.48KHRCT-ND | 311-3.48KHRTR-ND | RC0603
89 | 62-000149 | 1 | R126 | 4.64K | Resistor Chip 4.64 KOhms ±1% 1/10W 0603 Thick Film | Yageo | RC0603FR-074K64L | Digikey | 311-4.64KHRCT-ND | 311-4.64KHRTR-ND | RC0603
90 | 62-000151 | 1 | R146 | 5.90K | Resistor Chip 5.90 KOhms ±1% 1/10W 0603 Thick Film | Yageo | RC0603FR-075K9L | Digikey | 311-5.90KHRCT-ND | 311-5.90KHRTR-ND | RC0603
91 | 62-000153 | 1 | R92 | 6.98K | Resistor Chip 6.98 KOhms ±1% 1/10W 0603 Thick Film | Yageo | RC0603FR-076K98L | Digikey | 311-6.98KHRCT-ND | 311-6.98KHRTR-ND | RC0603
92 | 62-000155 | 1 | R200 | 8.20K | Resistor Chip 8.20 KOhms ±1% 1/10W 0603 Thick Film | Yageo | RC0603FR-078K2L | Digikey | 311-8.20KHRCT-ND | 311-8.20KHRTR-ND | RC0603
 |  |  |  |  |  | Panasonic | ERJ-2RKF8201X
93 | 62-000156 | 3 | R110, R111, R234 | 9.31K | Resistor Chip 9.31 KOhms ±1% 1/10W 0603 Thick Film | Yageo | RC0603FR-079K31L | Digikey | 311-9.31KHRCT-ND | 311-9.31KHRTR-ND | RC0603
 |  |  |  |  |  | Panasonic | ERJ-2RKF9311X
94 | 62-000157 | 1 | R281 | 11.8K | Resistor Chip 11.8 KOhms ±1% 1/10W 0603 Thick Film | Yageo | RC0603FR-0711K8L | Digikey | 311-11.8KHRCT-ND | 311-11.8KHRTR-ND | RC0603
95 | 62-000158 | 1 | R308 | 12.7K | Resistor Chip 12.7 KOhms ±1% 1/10W 0603 Thick Film | Yageo | RC0603FR-0712K7L | Digikey | 311-12.7KHRCT-ND | 311-12.7KHRTR-ND | RC0603
96 | 62-000159 | 1 | R335 | 14.0K | Resistor Chip 14.0 KOhms ±1% 1/10W 0603 Thick Film | Yageo | RC0603FR-0714KL | Digikey | 311-14.0KHRCT-ND | 311-14.0KHRTR-ND | RC0603
97 | 62-000161 | 1 | R394 | 16.2K | Resistor Chip 16.2 KOhms ±1% 1/10W 0603 Thick Film | Yageo | RC0603FR-0716K2L | Digikey | 311-16.2KHRCT-ND | 311-16.2KHRTR-ND | RC0603
 |  |  |  |  |  | Panasonic | ERJ-2RKF1622X
98 | 62-000162 | 15 | R1, R2, R3, R82, R109, R136, R163, R190, R217, R244, R271, R298, R325, R352, R382 | 5.1 Ohms | RES SMD 5.1 OHM 5% 1/2W 1210 | Panasonic | ERJ-14YJ5R1U | Digikey | P5.1VCT-ND | P5.1VTR-ND | 1210
 |  |  |  |  |  | Vishay | CRCW12105R10JNEA
99 | 62-000165 | 1 | R483 | 3.01 kOhms | RES SMD 3.01K OHM 1% 1/16W 0402 | Yageo | RC0402FR-073K01L | Digikey | 311-3.01KLRCT-ND | 311-3.01KLRTR-ND | RC0402A
100 | 87-000001 | 46 | Q7, Q8, Q9, Q10, Q11, Q12, Q13, Q14, Q15, Q18, Q19, Q20, Q23, Q24, Q25, Q28, Q29, Q30, Q33, Q34, Q35, Q38, Q39, Q40, Q43, Q44, Q45, Q48, Q49, Q50, Q53, Q54, Q55, Q58, Q59, Q60, Q63, Q64, Q65, Q68, Q69, Q70, Q73, Q74, Q75, Q78 |  | TRANS NPN 40V 0.2A SOT323 | ON Semiconductor | MMBT3904WT1G | Digi-Key | MMBT3904WT1GOSCT-ND | MMBT3904WT1GOSTR-ND | SC-70
101 | 87-000016 | 31 | Q1, Q2, Q3, Q4, Q5, Q6, Q16, Q17, Q21, Q22, Q26, Q27, Q31, Q32, Q36, Q37, Q41, Q42, Q46, Q47, Q51, Q52, Q56, Q57, Q61, Q62, Q66, Q67, Q71, Q72, Q77 |  | Bipolar (BJT) Transistor PNP 40V 200mA 250MHz 150mW SMD SC-70 | ON Semi | MMBT3906WT1G | Digi-Key | MMBT3906WT1GOSCT-ND | MMBT3906WT1GOSTR-ND | SC-70
 |  |  |  |  |  | ON Semiconductor | SMMBT3906WT1G
102 | 87-000024 | 4 | Q79, Q80, Q81, Q82 |  | MOSFET N-CH 25V 100A 8-SON | Texas Instruments | CSD16321Q5 | Digi-Key | 296-24517-1-ND | 296-24517-2-ND | 8DFN_6X5MM_EP1
103 | 17-000017 | DNI | C339, C342, C343, C344 | 47pF | CAP CER 47PF 50V NP0 0402 | Murata | GRM1555C1H470FA01D | Digi-Key | 490-6241-1-ND | 490-6241-2-ND | CC0402A
104 | 17-000025 | DNI | C338 | 0.10µF | CAP CER 0.1UF 25V X7R 0603 | TDK Corporation | C1608X7R1E104K080AA | Digi-Key | 445-1316-1-ND | 445-1316-2-ND | CC0603
105 | 17-000027 | DNI | C347 | 2200pF | CAP CER 2200PF 16V X7R 0402 | Murata | GRM155R71C222KA01D | Digi-Key | 490-6330-1-ND | 490-6330-2-ND | CC0402A
106 | 17-000053 | DNI | C381 | 1000pF | Capacitor Ceramic 1000pF ±10% 50V X7R 0402 | Murata | GRM155R71H102KA01D | Digi-Key | 490-1303-1-ND | 490-1303-2-ND | CC0402A
107 | 17-000058 | DNI | C336, C337 | 10pF | CAP CER 10PF 50V C0G/NP0 0402 | Murata | GRM1555C1H100JA01D | Digi-Key | 490-5921-1-ND | 490-5921-2-ND | CC0402A
108 | 17-000086 | DNI | C10, C11, C14, C15, C18, C19, C70, C71, C92, C93, C114, C115, C136, C137, C158, C159, C180, C181, C202, C203, C224, C225, C246, C247, C268, C269, C290, C291, C317, C318 | 0.1µF | CAP CER 0.1UF 10V X7R 0603 | KEMET | C0603X104K8RACTU | Digi-Key | 399-5343-1-ND | 399-5343-2-ND | CC0603
109 | 17-000087 | DNI | C24, C25, C26, C29, C30, C31, C32, C34, C35, C36, C39, C40, C41, C42, C44, C45, C48, C49, C50, C53, C54, C74, C75, C78, C79, C80, C83, C84, C96, C97, C100, C101, C102, C105, C106, C118, C119, C122, C123, C124, C127, C128, C140, C141, C144, C145, C146, C149, C150, C162, C163, C166, C167, C168, C171, C172, C184, C185, C188, C189, C190, C193, C194, C206, C207, C210, C211, C212, C215, C216, C228, C229, C232, C233, C234, C237, C238, C250, C251, C254, C255, C256, C259, C260, C272, C273, C276, C277, C278, C281, C282, C294, C295, C298, C299, C300, C303, C304, C321, C322, C325, C326, C327, C328, C331 | 0.1µF | CAP CER 0.1UF 10V X7R 0402 | KEMET | C0402C104J8RACTU | Digi-Key | 399-8942-1-ND | 399-8942-2-ND | CC0402A
110 | 17-000114 | DNI | C418, C419, C420, C421, C422, C423, C424, C425, C426, C427, C428, C429, C430, C431, C432 | 1000pF | CAP CER 1000PF 25V C0G/NP0 0402 | Samsung | CL05C102JA5NNNC | Digi-Key | 1276-1634-1-ND | 1276-1634-2-ND | CC0402A
111 | 53-000022 | DNI | LED1, LED2 |  | LED GREEN CLEAR 0402 SMD | Kingbright | APHHS1005CGCK | Digi-Key | 754-1101-1-ND | 754-1101-2-ND | LED0402A
112 | 62-000014 | DNI | R62, R69, R76, R103, R130, R158, R185, R212, R238, R266, R293, R324, R346, R374, R406 | 100K | RES SMD 100K OHM 1% 1/16W 0402 | Yageo | RC0402FR-07100KL | Digi-Key | 311-100KLRCT-ND | 311-100KLRTR-ND | RC0402A
113 | 57-000015 | DNI | MP1, MP2, MP3, MP4, MP5, MP6, MP7, MP8, MP9, MP10, MP11, MP12, MP13, MP14, MP15 | 5019 | PCB Test Point, Miniature Phosphor Bronze, Silver Plating Surface Mount Mounting Type |  |  | Digi-Key | 36-5019CT-ND | 36-5019TR-ND | TP_5019
114 | 57-000016 | DNI | MP16, MP17, MP18, MP19, MP20, MP21, MP22, MP23, MP24, MP25, MP26, MP27, MP28, MP29, MP30, MP31, MP32, MP33, MP34, MP35, MP36, MP37, MP38, MP39, MP40, MP41, MP42, MP43, MP44, MP45 | 5017 | PCB Test Point, Miniature Phosphor Bronze, Silver Plating Surface Mount Mounting Type |  |  | Digi-Key | 36-5017CT-ND | 36-5017TR-ND | TP_5017
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

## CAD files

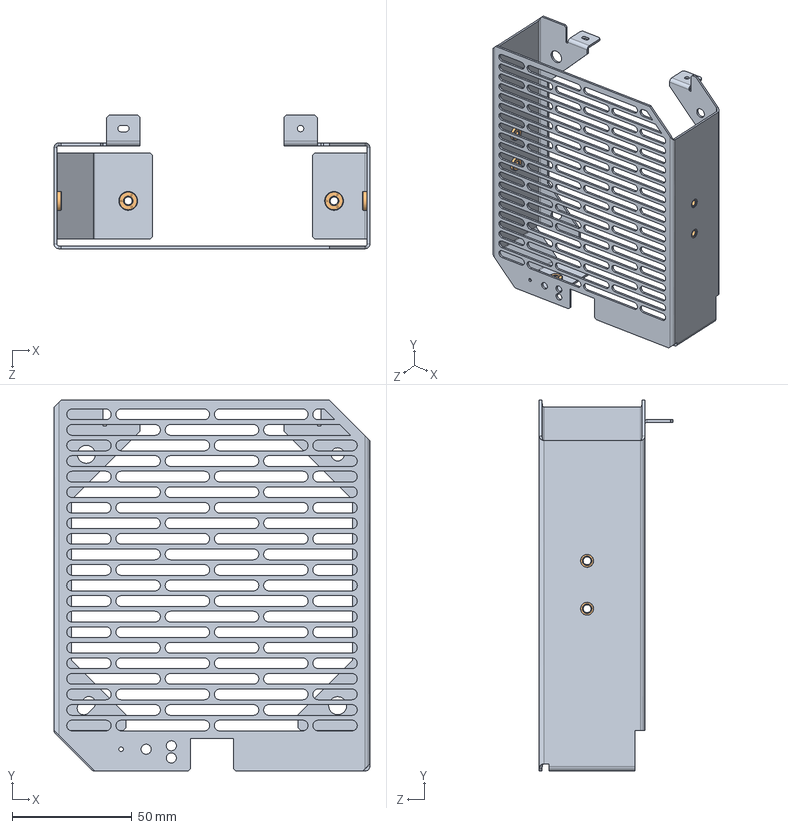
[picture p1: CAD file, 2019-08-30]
Generation 1 Mining Hardware/Mechanical/TE-1719_742921-02_SC1-Assem_PRELIM_051818/TE-1719_742926-04_SC1-Front-Grill.SLDASM
132.0 x 155.0 x 55.8 mm
TE-1719_742926-04_742928-04_MASTER-MODEL_SC1-FRONT-REAR
PEM-Nut_S-M4-1ZI x 6

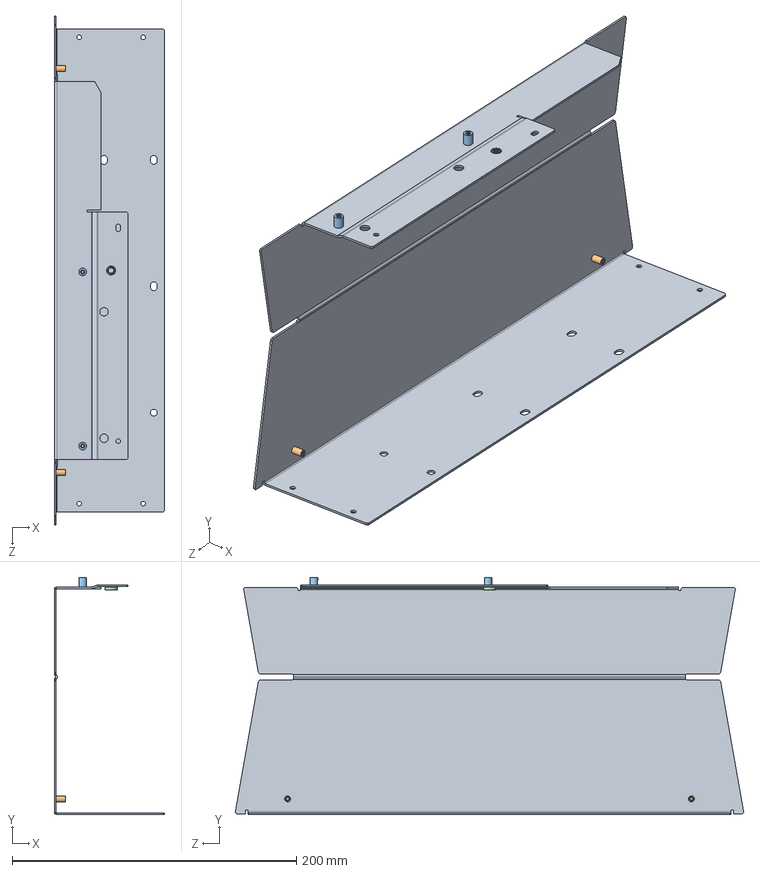
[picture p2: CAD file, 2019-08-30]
Generation 2 Mining Hardware/Mechanical – Slim/OB_1735100-F_W2-Assem_2018-10-01/OB_1735304-E_W2-Chassis-Left.SLDASM
77.7 x 166.7 x 357.7 mm
OB_1735304-E_W2-Chassis-Left
93090A420_PRESS-FIT FEMALE ROUND STANDOFFS x 2
Standoff_4-40x312_JHP-BSO644010D x 2
95185A185_ZNC-PLTD STL PRESS-IN NUTS FOR SHEET MTL

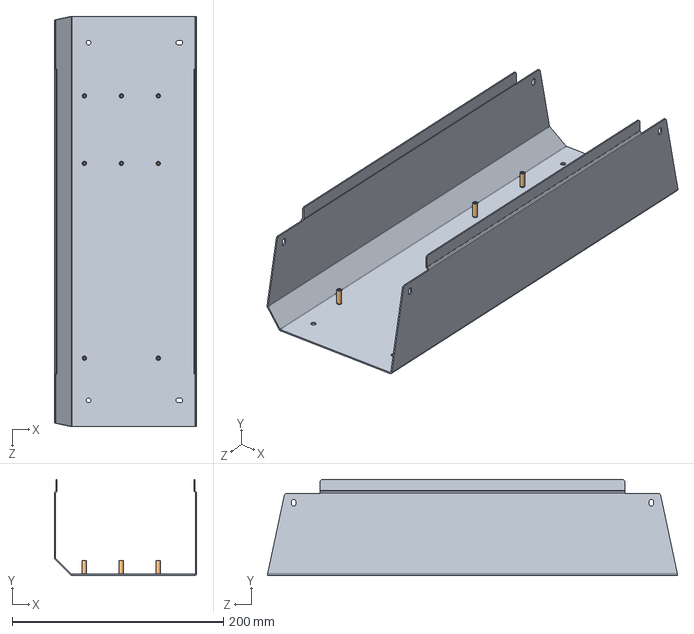
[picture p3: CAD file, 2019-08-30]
Generation 1 Mining Hardware/Mechanical/TE-1719_742921-02_SC1-Assem_PRELIM_051818/TE-1719_742923-02_SC1-Base.SLDASM
135.0 x 91.0 x 388.5 mm
TE-1719_742923-02_SC1-Base
PEM-Standoff_BSO-440-18ZI x 8

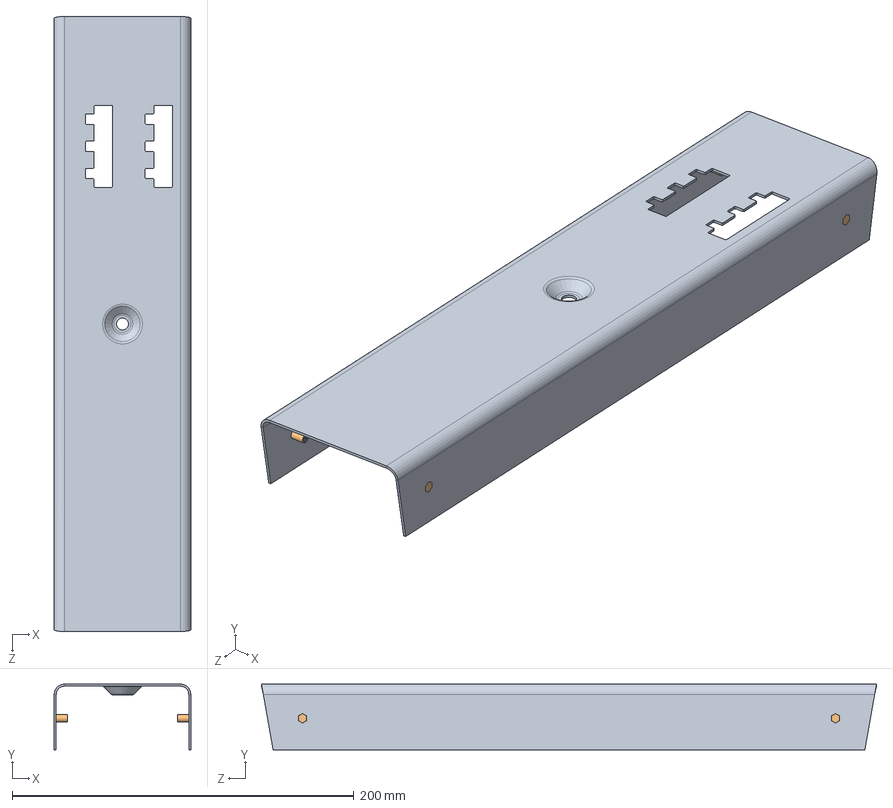
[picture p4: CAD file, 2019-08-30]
Generation 2 Mining Hardware/Mechanical – Slim/OB_1735100-F_W2-Assem_2018-10-01/OB_1735302-D_W2-Cover.SLDASM
80.0 x 38.5 x 360.0 mm
OB_1735302-D_W2-Cover
93090A420_PRESS-FIT FEMALE ROUND STANDOFFS x 4

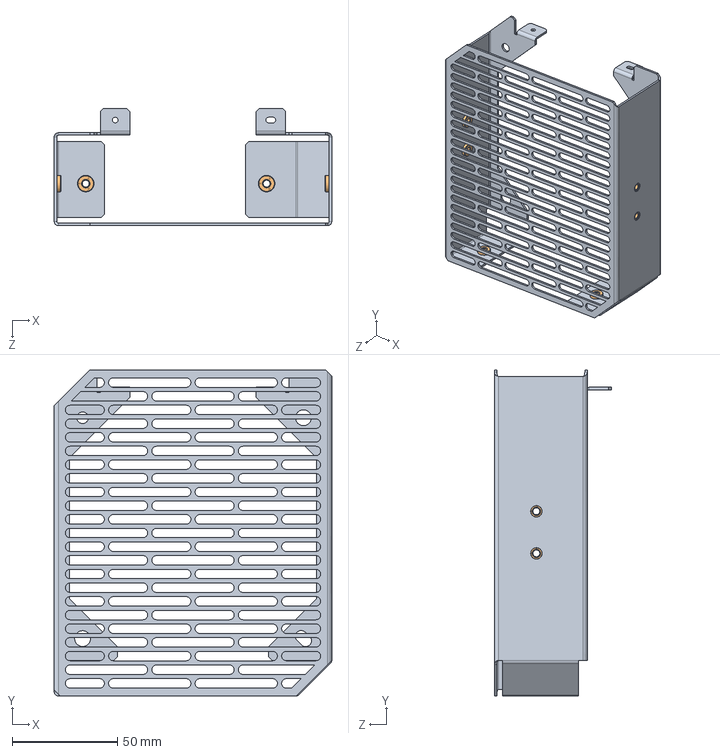
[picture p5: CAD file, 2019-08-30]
Generation 1 Mining Hardware/Mechanical/TE-1719_742921-02_SC1-Assem_PRELIM_051818/TE-1719_742928-04_SC1-Rear-Grill.SLDASM
132.0 x 155.0 x 55.8 mm
TE-1719_742926-04_742928-04_MASTER-MODEL_SC1-FRONT-REAR
PEM-Nut_S-M4-1ZI x 6

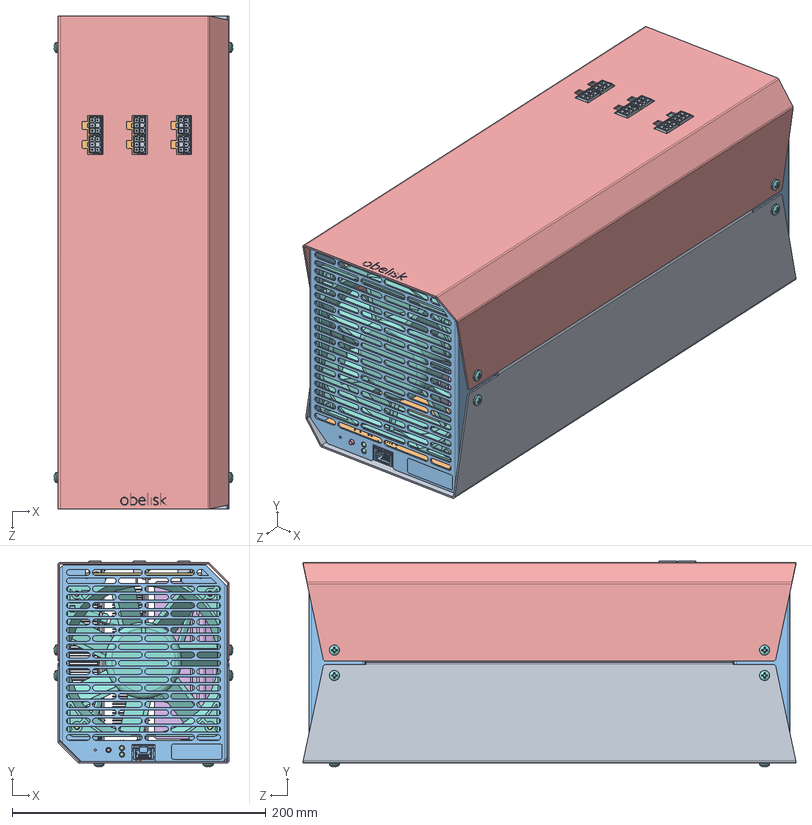
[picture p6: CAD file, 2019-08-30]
Generation 1 Mining Hardware/Mechanical/TE-1719_742921-02_SC1-Assem_PRELIM_051818/TE-1719_742921-02_SC1-Assem_PRELIM.SLDASM
141.0 x 162.1 x 388.5 mm
TE-1719_742923-02_SC1-Base
PEM-Standoff_BSO-440-18ZI x 8
TE-1719_742926-04_742928-04_MASTER-MODEL_SC1-FRONT-REAR x 2
PEM-Nut_S-M4-1ZI x 12
TE-1719_742924-02_SC1-Cover
TE-1719_742933-00_SC1-AIRFLOW-GUIDE x 2
TE-1719_742929-01_SC1-Upper-Guide x 2
FAN_Jaro_JCD1203812LBBA0D(4600) x 2
SIAHashBd742901R0pcb_03-26-18 x 3
PCB_Main-Control-Board_REF-02
M-RJE73-188-00XX0-REVG1
LED_Dual-3mm_Dialight
EVQPF008K x 2
SCREW_4-40x250_SEMS-SCREW_90402A106 x 8
SCREW_10-14X750_THREAD-FORM_99461A460 x 8
SCREW_M4X6_NYLON-PATCH_BLACK_95911A254 x 12
RIVET_3-32_97447A110 x 4
RIVET-WASHER_3-32_90183A308 x 4
STICKER_FRONT

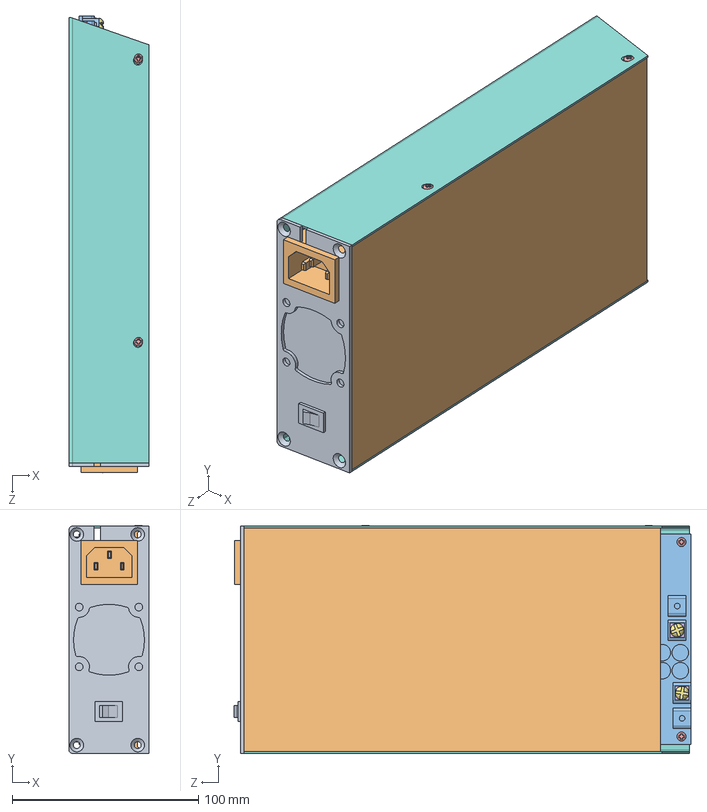
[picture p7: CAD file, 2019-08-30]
Generation 2 Mining Hardware/Mechanical – Immersion/OB_1735102-D_1U-Rack-Sled-Assem_2018-01-07/APS-Power-Supply_Assem_02.SLDASM
43.0 x 122.3 x 245.1 mm
MP1000-1121 ON OFF KEY
MP1000-1121 ON CABLE TERMINAL
MP1000-1121 PCB
MP1000-1121 PCB SPACER x 2
MP1000-1121 BODY SCREW 1 x 6
MP1000-1121 PCB WASHER x 2
MP1000-1121 PCB SCREW x 2
BASE
BACK
TOP

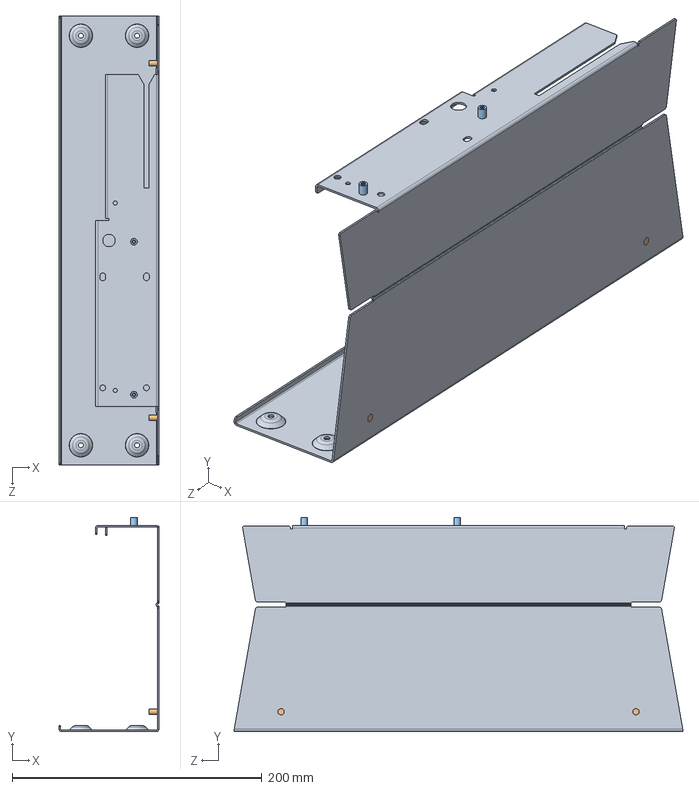
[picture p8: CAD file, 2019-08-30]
Generation 2 Mining Hardware/Mechanical – Slim/OB_1735100-F_W2-Assem_2018-10-01/OB_1735303-E_W2-Chassis-Right.SLDASM
80.0 x 171.7 x 359.6 mm
OB_1735303-E_W2-Chassis-Right
93090A420_PRESS-FIT FEMALE ROUND STANDOFFS x 2
Standoff_4-40x312_JHP-BSO644010D x 2

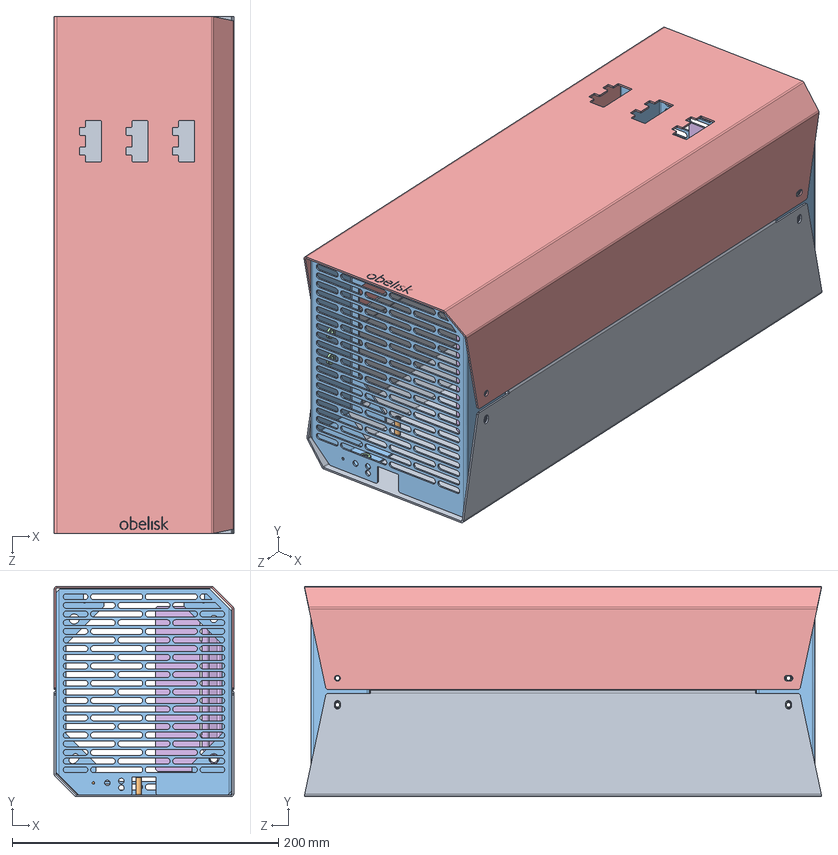
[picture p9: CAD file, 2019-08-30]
Generation 1 Mining Hardware/Mechanical/TE-1719_742921-02_SC1-Assem_PRELIM_051818/TE-1719_742931-04_SC1-Sheet-Metal-Subassem.SLDASM
135.0 x 158.0 x 388.5 mm
TE-1719_742923-02_SC1-Base
PEM-Standoff_BSO-440-18ZI x 8
TE-1719_742926-04_742928-04_MASTER-MODEL_SC1-FRONT-REAR x 2
PEM-Nut_S-M4-1ZI x 12
TE-1719_742933-00_SC1-AIRFLOW-GUIDE x 2

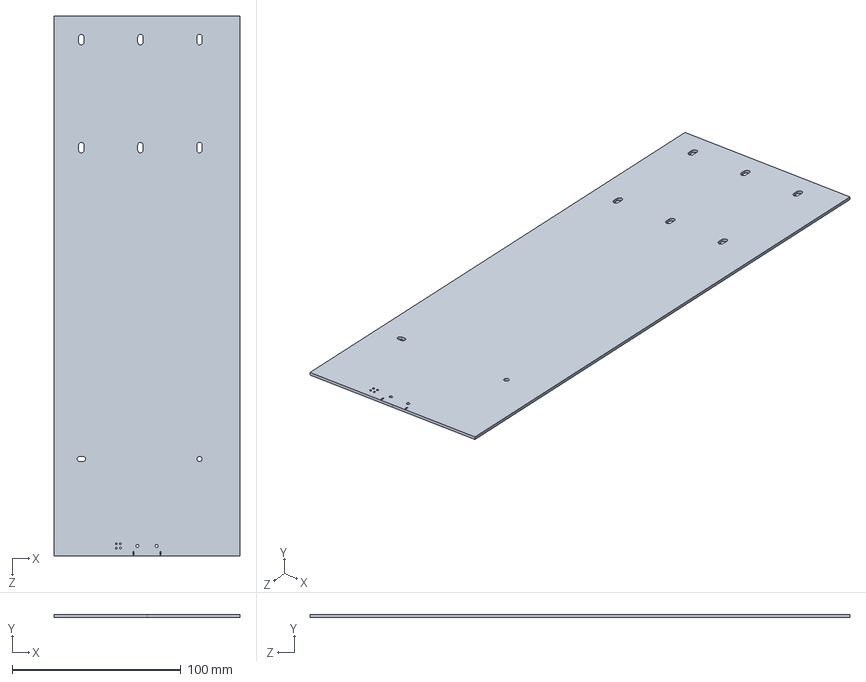
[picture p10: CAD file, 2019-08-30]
Generation 1 Mining Hardware/Mechanical/TE-1719_742921-02_SC1-Assem_PRELIM_051818/PCB_Main-Control-Board_REF-02.SLDPRT
110.0 x 1.60 x 320.0 mm

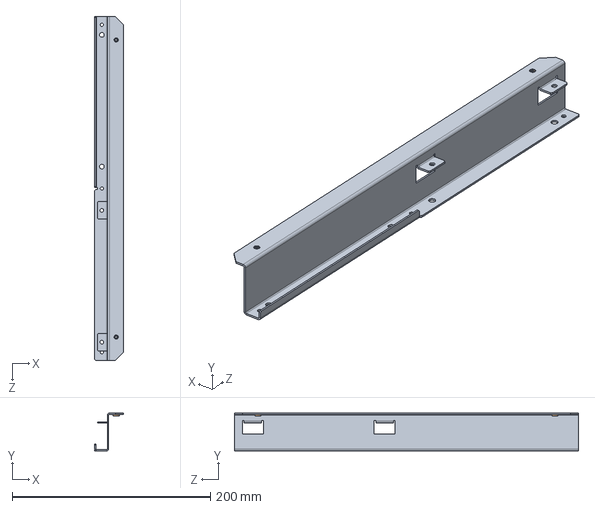
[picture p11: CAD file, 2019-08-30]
Generation 2 Mining Hardware/Mechanical – Immersion/OB_1735102-D_1U-Rack-Sled-Assem_2018-01-07/OB_1735314-C_1U-Inner-Bracket.SLDASM
28.8 x 38.1 x 347.0 mm
OB_1735314-C_1U-Inner-Bracket
S-440-1ZI_SELF-CLINCHING-NUT x 2

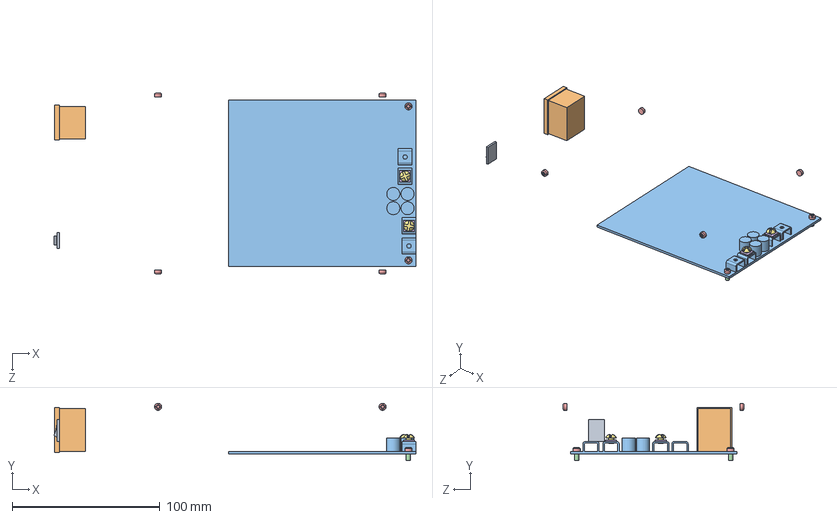
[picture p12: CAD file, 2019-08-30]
Generation 2 Mining Hardware/Mechanical – Immersion/OB_1735102-D_1U-Rack-Sled-Assem_2018-01-07/MP1000-1121 ASSEMBLY.SLDASM
245.1 x 38.9 x 122.3 mm
MP1000-1121 ON OFF KEY
MP1000-1121 ON CABLE TERMINAL
MP1000-1121 PCB
MP1000-1121 PCB SPACER x 2
MP1000-1121 BODY SCREW 1 x 6
MP1000-1121 PCB WASHER x 2
MP1000-1121 PCB SCREW x 2

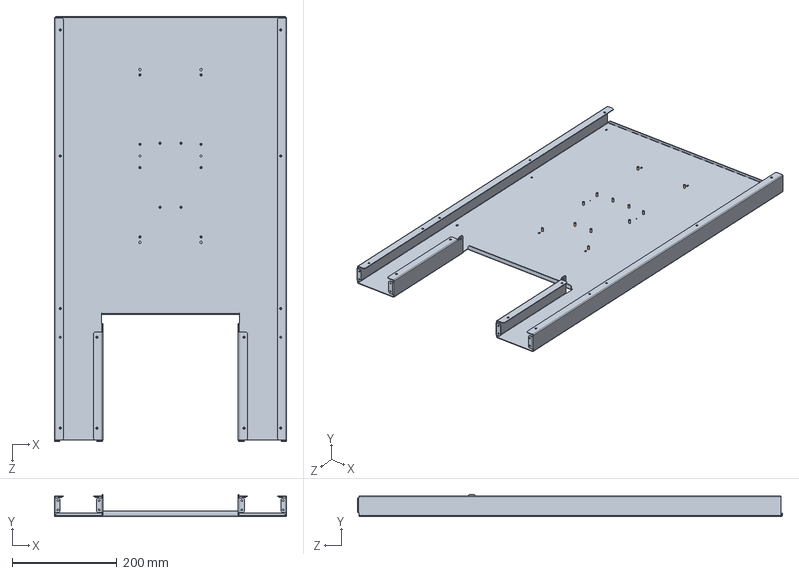
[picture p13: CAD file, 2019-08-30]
Generation 2 Mining Hardware/Mechanical – Immersion/OB_1735102-D_1U-Rack-Sled-Assem_2018-01-07/OB_1735311-C_1U-Housing.SLDASM
444.5 x 42.2 x 812.8 mm
OB_1735311-C_1U-Housing
PEM-STANDOFF_BSO-440-10ZI x 12
S-440-1ZI_SELF-CLINCHING-NUT x 14

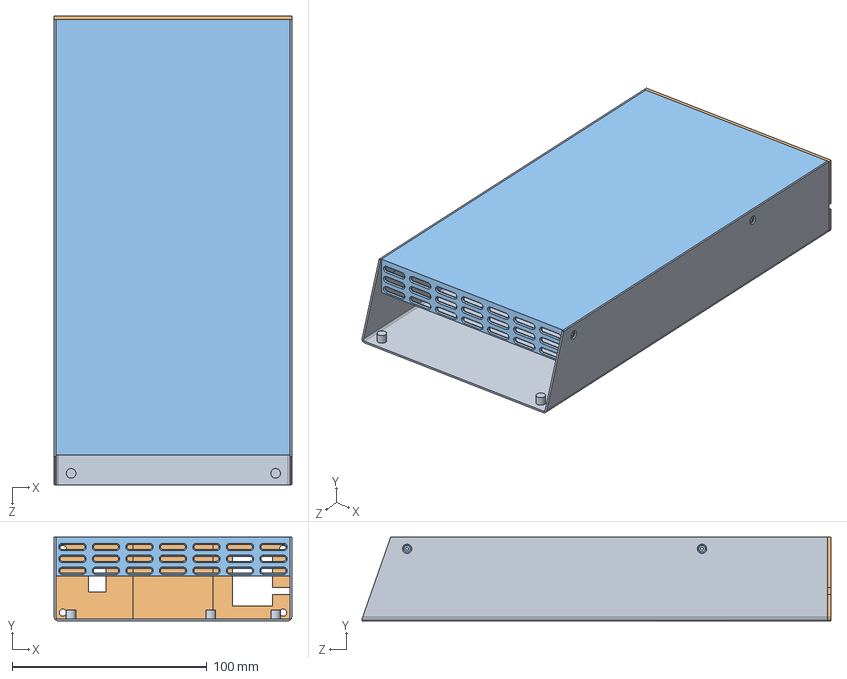
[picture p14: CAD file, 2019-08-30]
Generation 2 Mining Hardware/Mechanical – Immersion/OB_1735102-D_1U-Rack-Sled-Assem_2018-01-07/MP1000-FACTORY SPEC.SLDASM
122.0 x 43.0 x 240.8 mm
BASE
BACK
TOP

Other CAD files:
Generation 2 Mining Hardware/Mechanical – Immersion/OB_1735102-D_1U-Rack-Sled-Assem_2018-01-07/MP-1000_2018-12-10.sldasm
Generation 1 Mining Hardware/Mechanical/TE-1719_742929-01_SC1-Upper-Guide.DXF
Generation 2 Mining Hardware/Heatsink/Heatsink.SLDPRT
Generation 2 Mining Hardware/Mechanical – Immersion/OB_1735102-D_1U-Rack-Sled-Assem_2018-01-07/FOAM_062_NEOPRENE-ADHESIVE.SLDPRT
Generation 1 Mining Hardware/Mechanical/TE-1719_742921-02_SC1-Assem_PRELIM_051818/EVQPF008K.SLDPRT
Generation 1 Mining Hardware/Mechanical/TE-1719_742921-02_SC1-Assem_PRELIM_051818/FAN_Jaro_JCD1203812LBBA0D(4600).SLDPRT
Generation 1 Mining Hardware/Mechanical/TE-1719_742921-02_SC1-Assem_PRELIM_051818/LED_Dual-3mm_Dialight.SLDPRT
Generation 1 Mining Hardware/Mechanical/TE-1719_742921-02_SC1-Assem_PRELIM_051818/M-RJE73-188-00XX0-REVG1.SLDPRT
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

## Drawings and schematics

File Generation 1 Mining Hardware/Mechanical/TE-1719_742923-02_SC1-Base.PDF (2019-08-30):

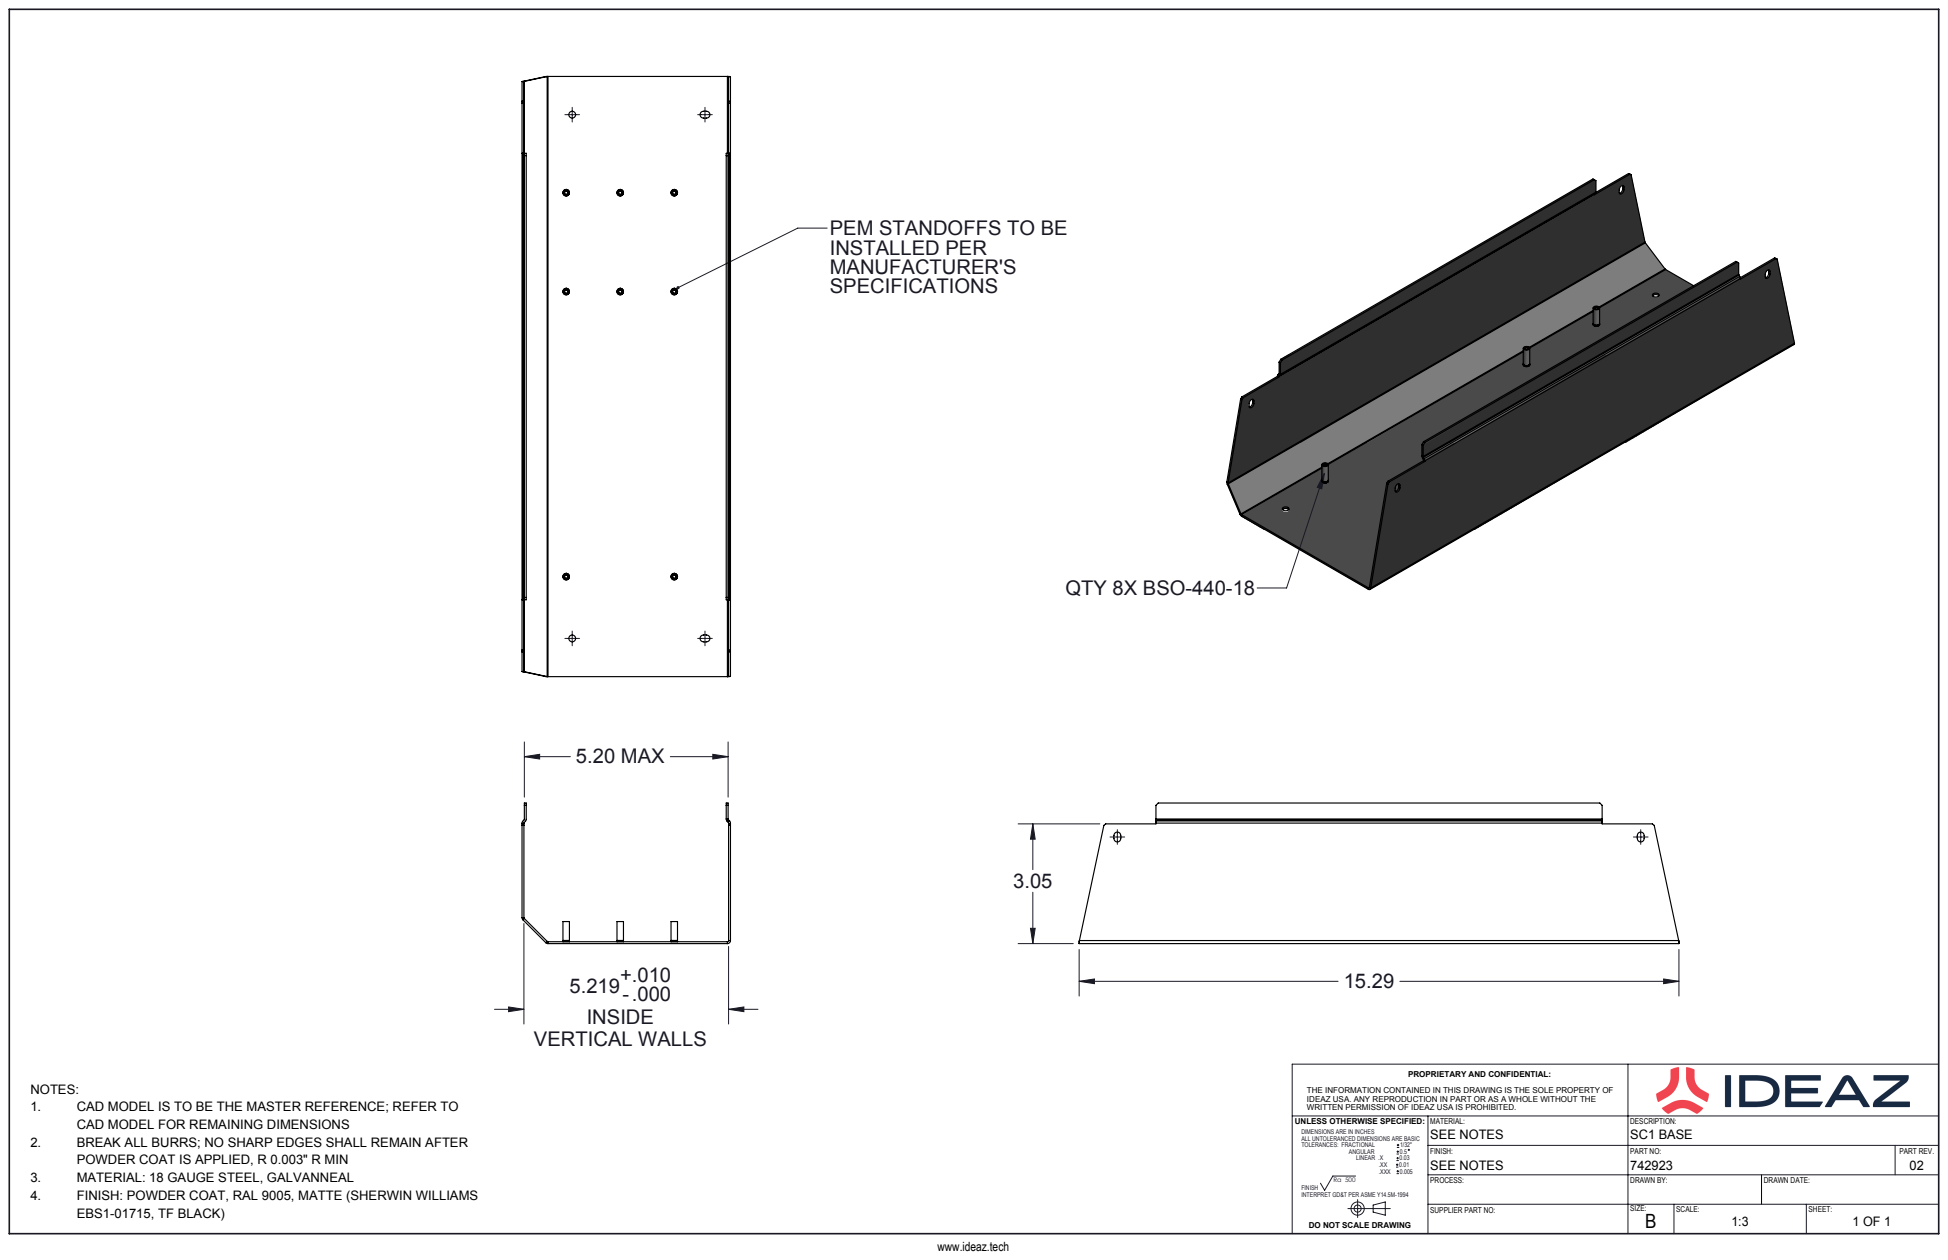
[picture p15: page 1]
VERTICAL WALLS; 5.20 MAX; QTY 8X BSO-440-18; EBS1-01715, TF BLACK)

PEM STANDOFFS TO BE
INSTALLED PER
MANUFACTURER'S
SPECIFICATIONS

PROPRIETARY AND CONFIDENTIAL: THE INFORMATION CONTAINED IN THIS DRAWING IS THE SOLE PROPERTY OF IDEAZ USA. ANY REPRODUCTION IN PART OR AS A WHOLE WITHOUT THE WRITTEN PERMISSION OF IDEAZ USA IS PROHIBITED.

NOTES:
1. CAD MODEL IS TO BE THE MASTER REFERENCE; REFER TO
CAD MODEL FOR REMAINING DIMENSIONS
2. BREAK ALL BURRS; NO SHARP EDGES SHALL REMAIN AFTER
POWDER COAT IS APPLIED, R 0.003" R MIN
3. MATERIAL: 18 GAUGE STEEL, GALVANNEAL
4. FINISH: POWDER COAT, RAL 9005, MATTE (SHERWIN WILLIAMS

UNLESS OTHERWISE SPECIFIED: DIMENSIONS ARE IN INCHES ALL UNTOLERANCED DIMENSIONS ARE BASIC TOLERANCES: FRACTIONAL 1/32" ANGULAR 0.5 LINEAR .X 0.03 .XX 0.01 .XXX 0.005 Ra 500 FINISH INTERPRET GD&T PER ASME Y14.5M-1994 DO NOT SCALE DRAWING | MATERIAL: SEE NOTES | DESCRIPTION: SC1 BASE

FINISH: SEE NOTES | PART NO: PART REV. 742923 02

PROCESS: | DRAWN BY: | DRAWN DATE:
SUPPLIER PART NO: | SIZE: B | SCALE: | SHEET:

www.ideaz.tech

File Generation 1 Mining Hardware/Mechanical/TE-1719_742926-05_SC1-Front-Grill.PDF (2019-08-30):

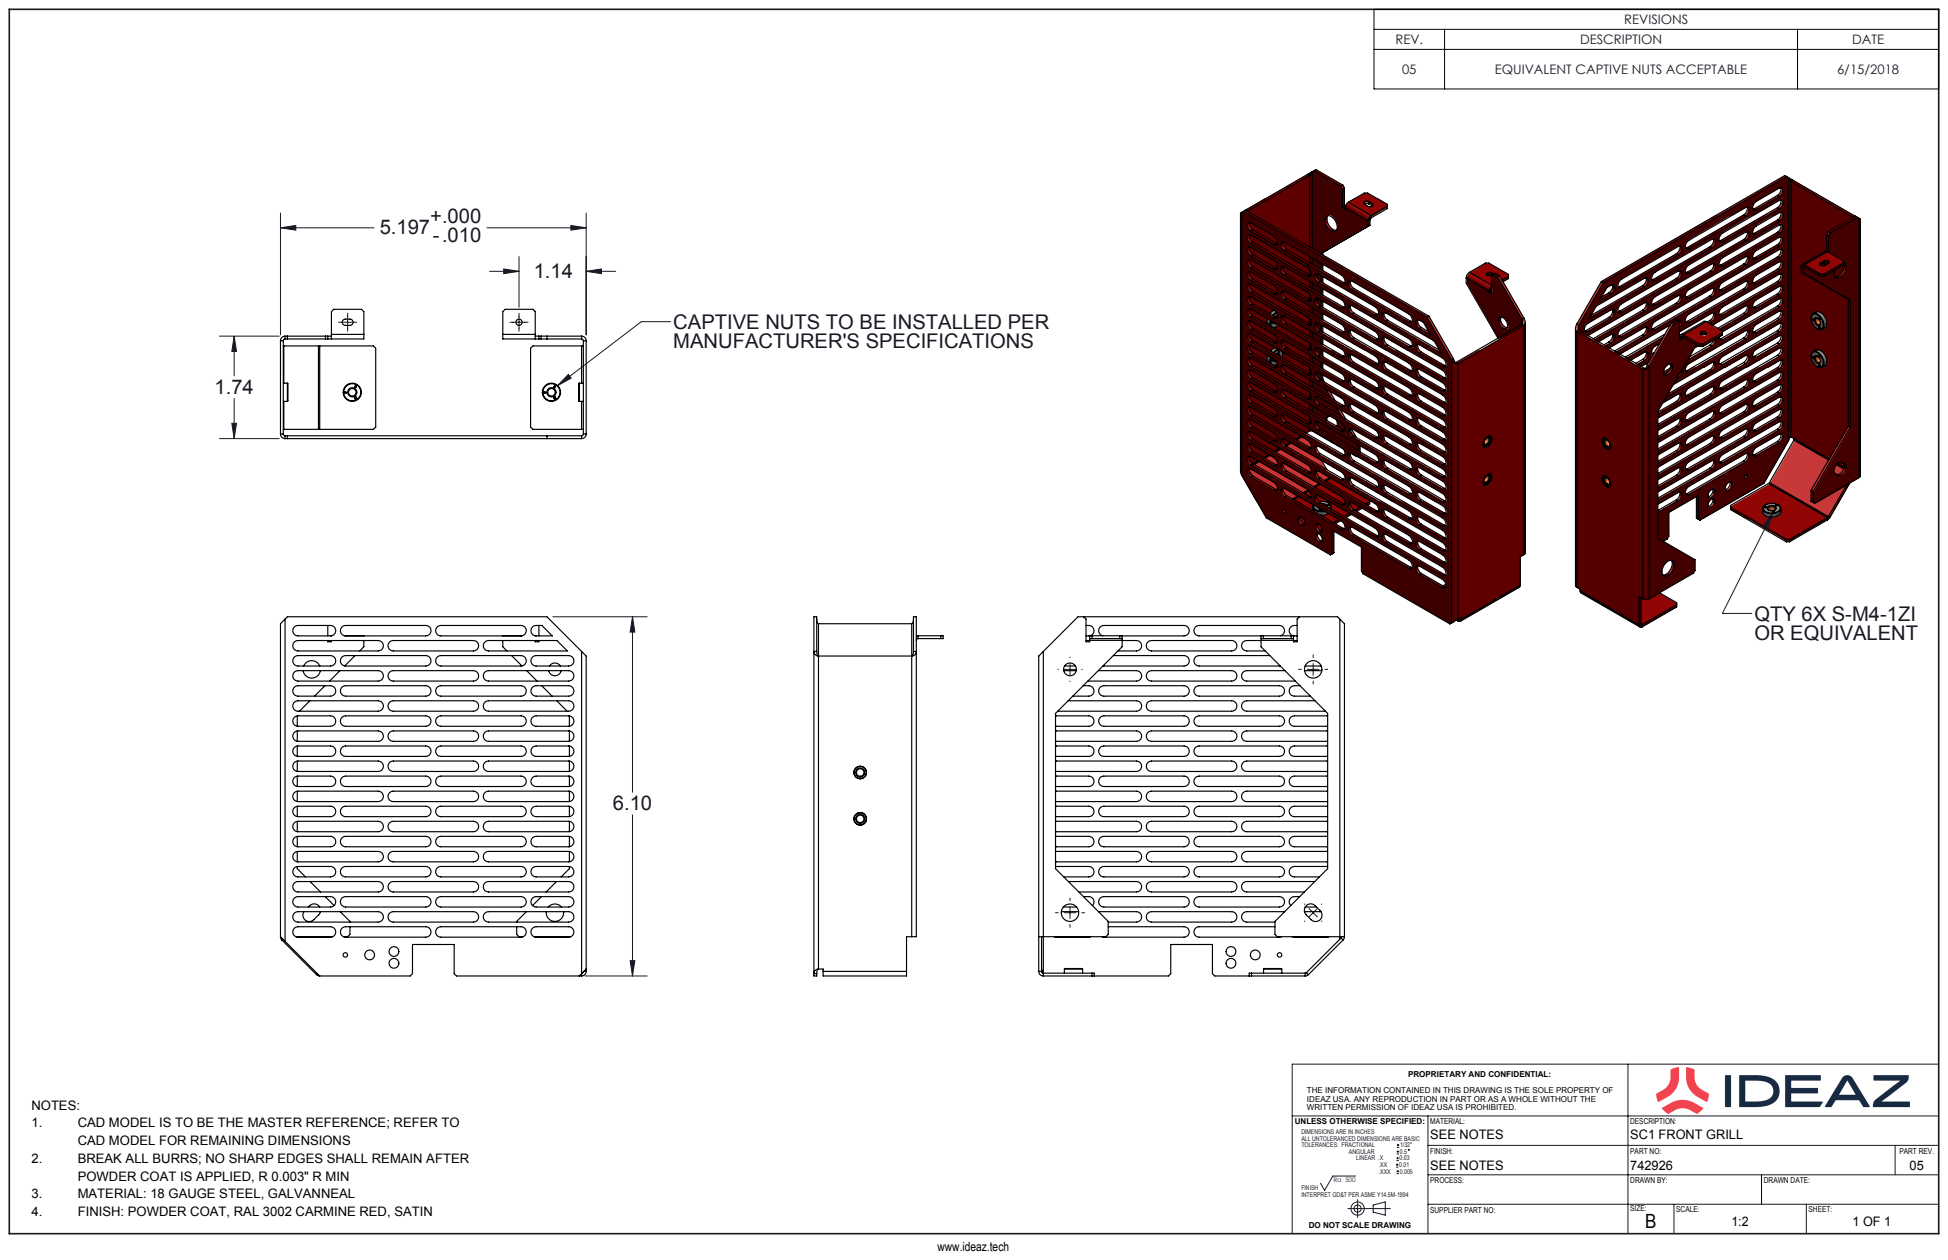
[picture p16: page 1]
QTY 6X S-M4-1ZI OR EQUIVALENT

REVISIONS

REV. | DESCRIPTION | DATE
05 | EQUIVALENT CAPTIVE NUTS ACCEPTABLE | 6/15/2018

CAPTIVE NUTS TO BE INSTALLED PER
MANUFACTURER'S SPECIFICATIONS

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

NOTES:
1. CAD MODEL IS TO BE THE MASTER REFERENCE; REFER TO
CAD MODEL FOR REMAINING DIMENSIONS
2. BREAK ALL BURRS; NO SHARP EDGES SHALL REMAIN AFTER
POWDER COAT IS APPLIED, R 0.003" R MIN
3. MATERIAL: 18 GAUGE STEEL, GALVANNEAL
4. FINISH: POWDER COAT, RAL 3002 CARMINE RED, SATIN

UNLESS OTHERWISE SPECIFIED: DIMENSIONS ARE IN INCHES ALL UNTOLERANCED DIMENSIONS ARE BASIC TOLERANCES: FRACTIONAL 1/32" ANGULAR 0.5 LINEAR .X 0.03 .XX 0.01 .XXX 0.005 Ra 500 FINISH INTERPRET GD&T PER ASME Y14.5M-1994 DO NOT SCALE DRAWING | MATERIAL: SEE NOTES | DESCRIPTION: SC1 FRONT GRILL

FINISH: SEE NOTES | PART NO: PART REV. 742926 05

PROCESS: | DRAWN BY: | DRAWN DATE:
SUPPLIER PART NO: | SIZE: B | SCALE: 1:2 | SHEET: 1 OF 1

www.ideaz.tech

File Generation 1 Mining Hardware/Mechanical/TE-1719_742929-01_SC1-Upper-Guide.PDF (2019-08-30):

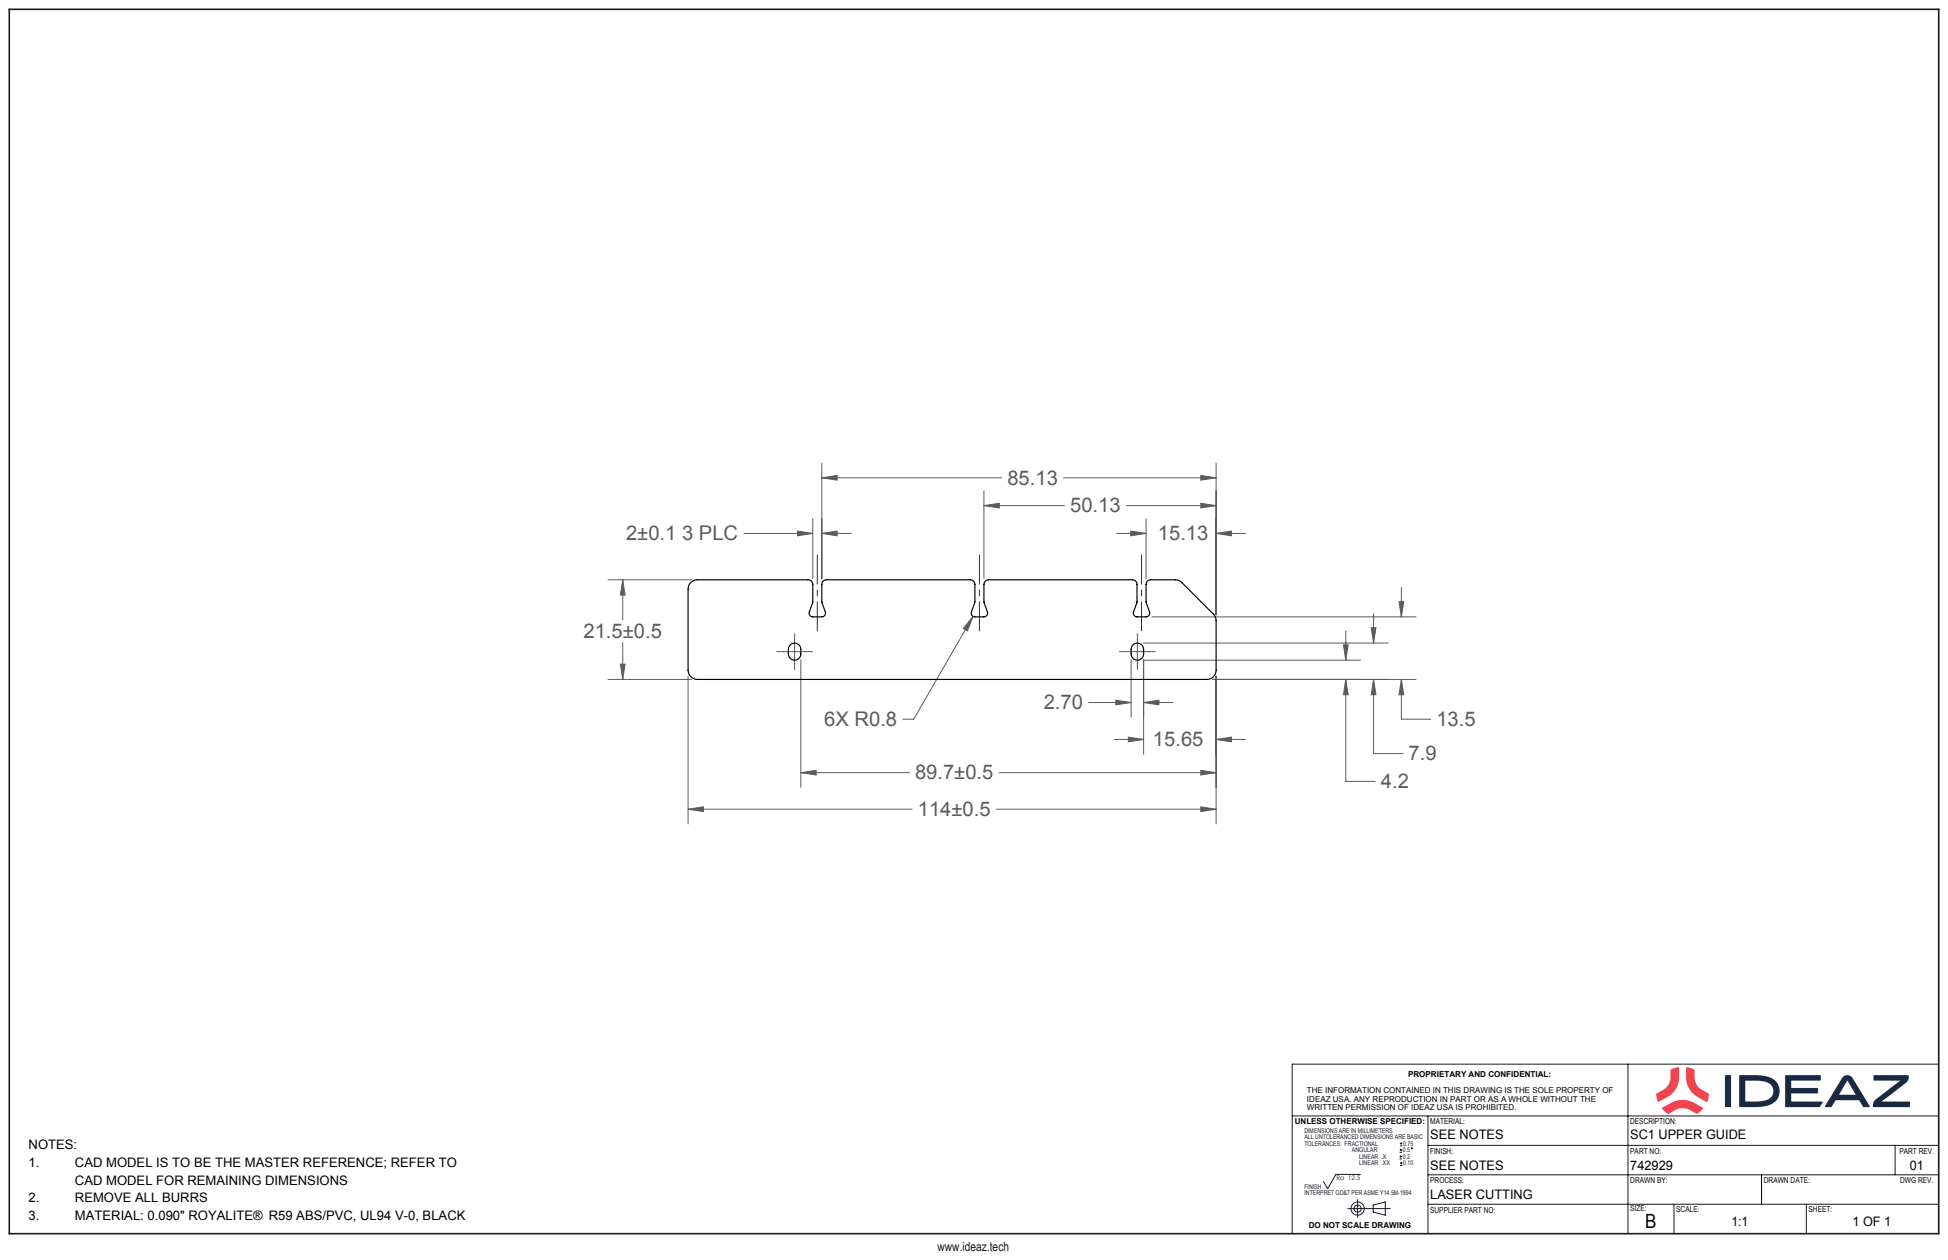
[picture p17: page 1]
2±0.1 3 PLC; MATERIAL: 0.090" ROYALITE® R59 ABS/PVC, UL94 V-0, BLACK

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

UNLESS OTHERWISE SPECIFIED: DIMENSIONS ARE IN MILLIMETERS ALL UNTOLERANCED DIMENSIONS ARE BASIC TOLERANCES: FRACTIONAL 0.75 ANGULAR 0.5 LINEAR .X 0.2 LINEAR .XX 0.10 Ra 12.5 FINISH INTERPRET GD&T PER ASME Y14.5M-1994 DO NOT SCALE DRAWING | MATERIAL: SEE NOTES | DESCRIPTION: SC1 UPPER GUIDE

NOTES:
1. CAD MODEL IS TO BE THE MASTER REFERENCE; REFER TO
CAD MODEL FOR REMAINING DIMENSIONS
2. REMOVE ALL BURRS

FINISH: SEE NOTES | PART NO: 742929 | PART REV. 01

PROCESS: LASER CUTTING | DRAWN BY: | DRAWN DATE: DWG REV.
SUPPLIER PART NO: | SIZE: B | SCALE: | SHEET:

www.ideaz.tech

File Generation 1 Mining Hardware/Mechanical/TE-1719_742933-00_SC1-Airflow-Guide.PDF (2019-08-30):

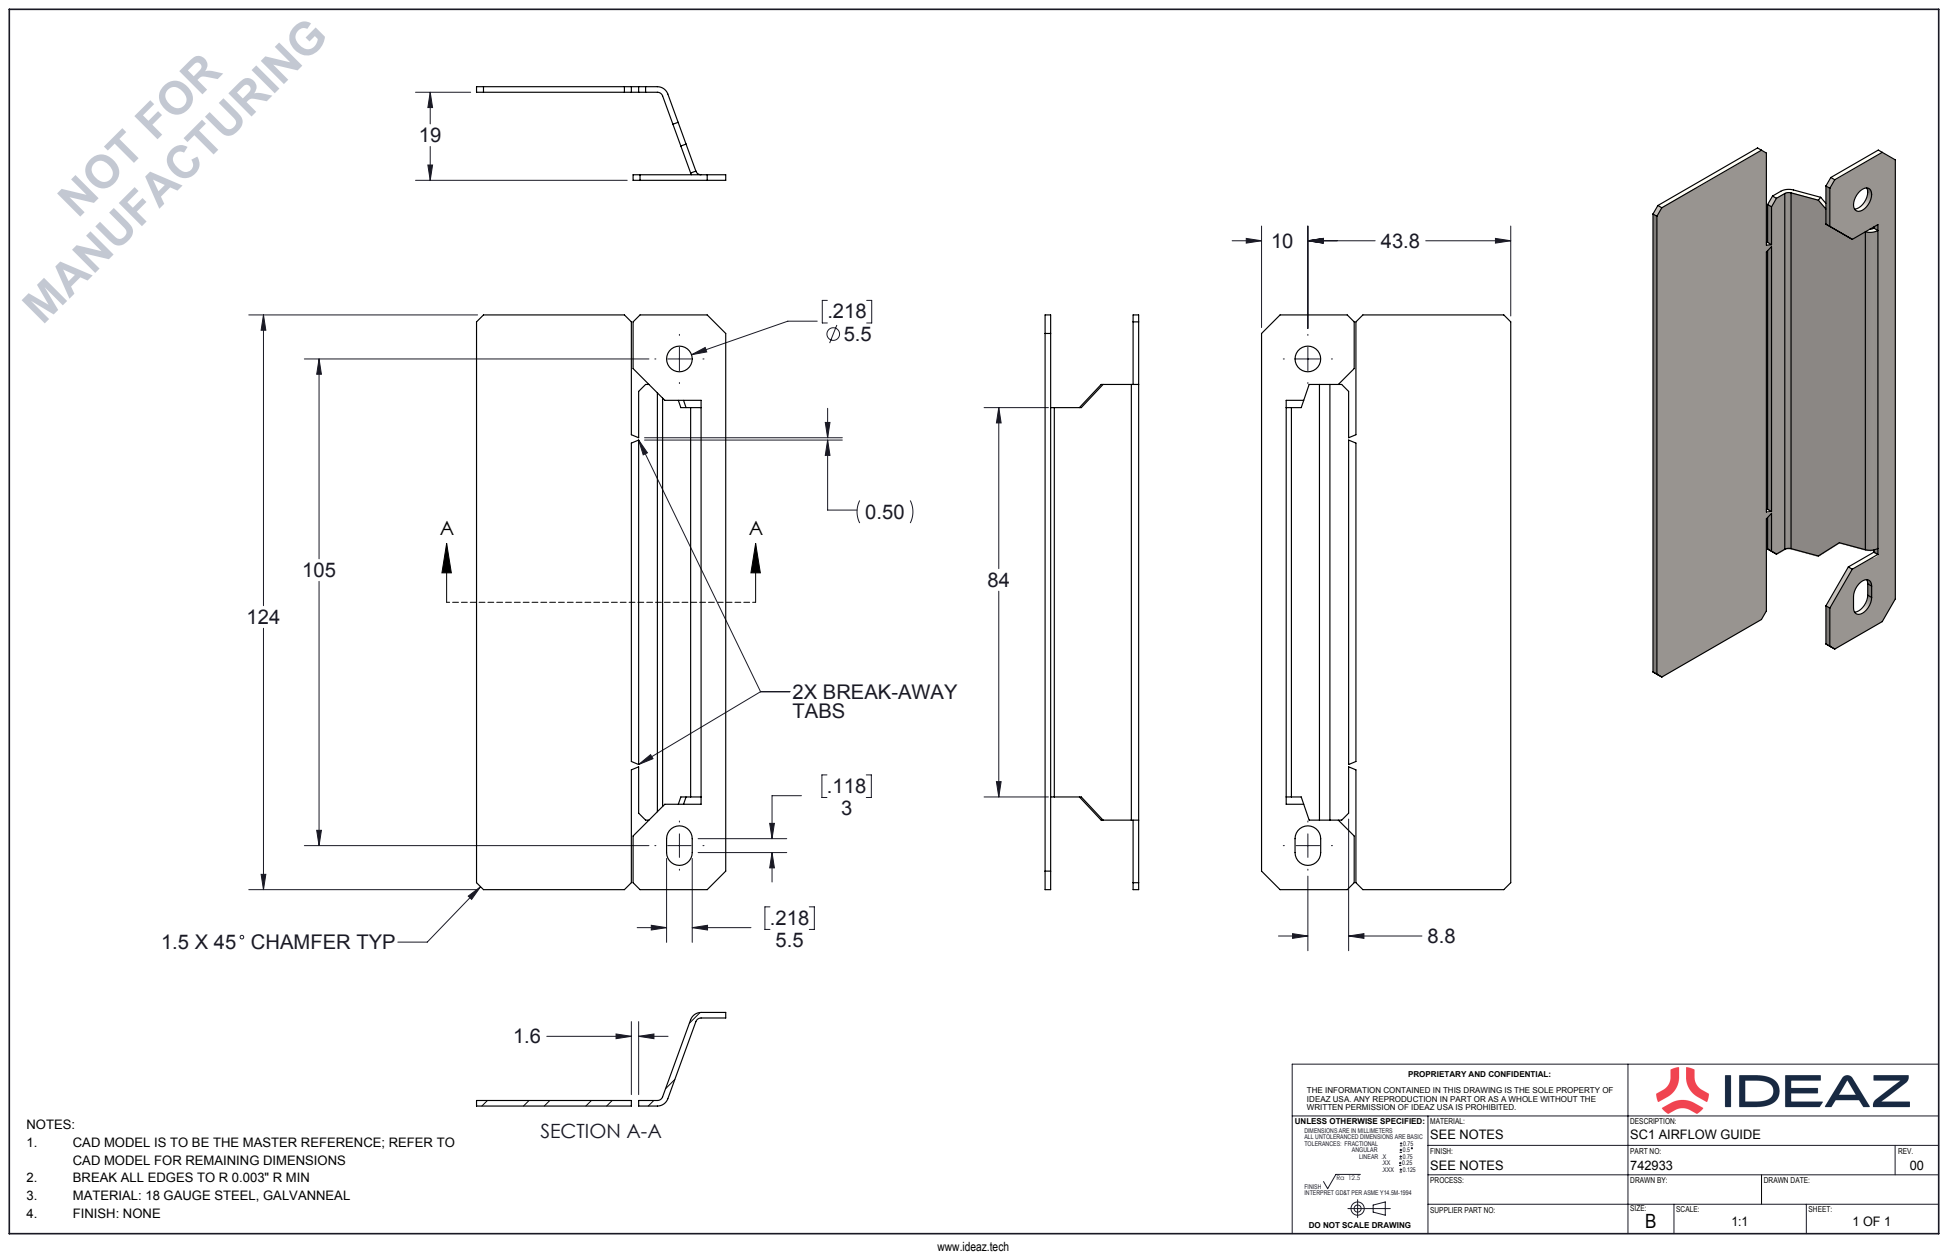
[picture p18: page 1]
2X BREAK-AWAY; 1.5 X 45 CHAMFER TYP; SECTION A-A; FINISH: NONE; NOT FOR

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

NOTES:
1. CAD MODEL IS TO BE THE MASTER REFERENCE; REFER TO
CAD MODEL FOR REMAINING DIMENSIONS
2. BREAK ALL EDGES TO R 0.003" R MIN
3. MATERIAL: 18 GAUGE STEEL, GALVANNEAL

UNLESS OTHERWISE SPECIFIED: DIMENSIONS ARE IN MILLIMETERS ALL UNTOLERANCED DIMENSIONS ARE BASIC TOLERANCES: FRACTIONAL 0.75 ANGULAR 0.5 LINEAR .X 0.75 .XX 0.25 .XXX 0.125 Ra 12.5 FINISH INTERPRET GD&T PER ASME Y14.5M-1994 DO NOT SCALE DRAWING | MATERIAL: SEE NOTES | DESCRIPTION: SC1 AIRFLOW GUIDE

FINISH: SEE NOTES | PART NO: REV. 742933 00

PROCESS: | DRAWN BY: | DRAWN DATE:
SUPPLIER PART NO: | SIZE: B | SCALE: | SHEET:

www.ideaz.tech

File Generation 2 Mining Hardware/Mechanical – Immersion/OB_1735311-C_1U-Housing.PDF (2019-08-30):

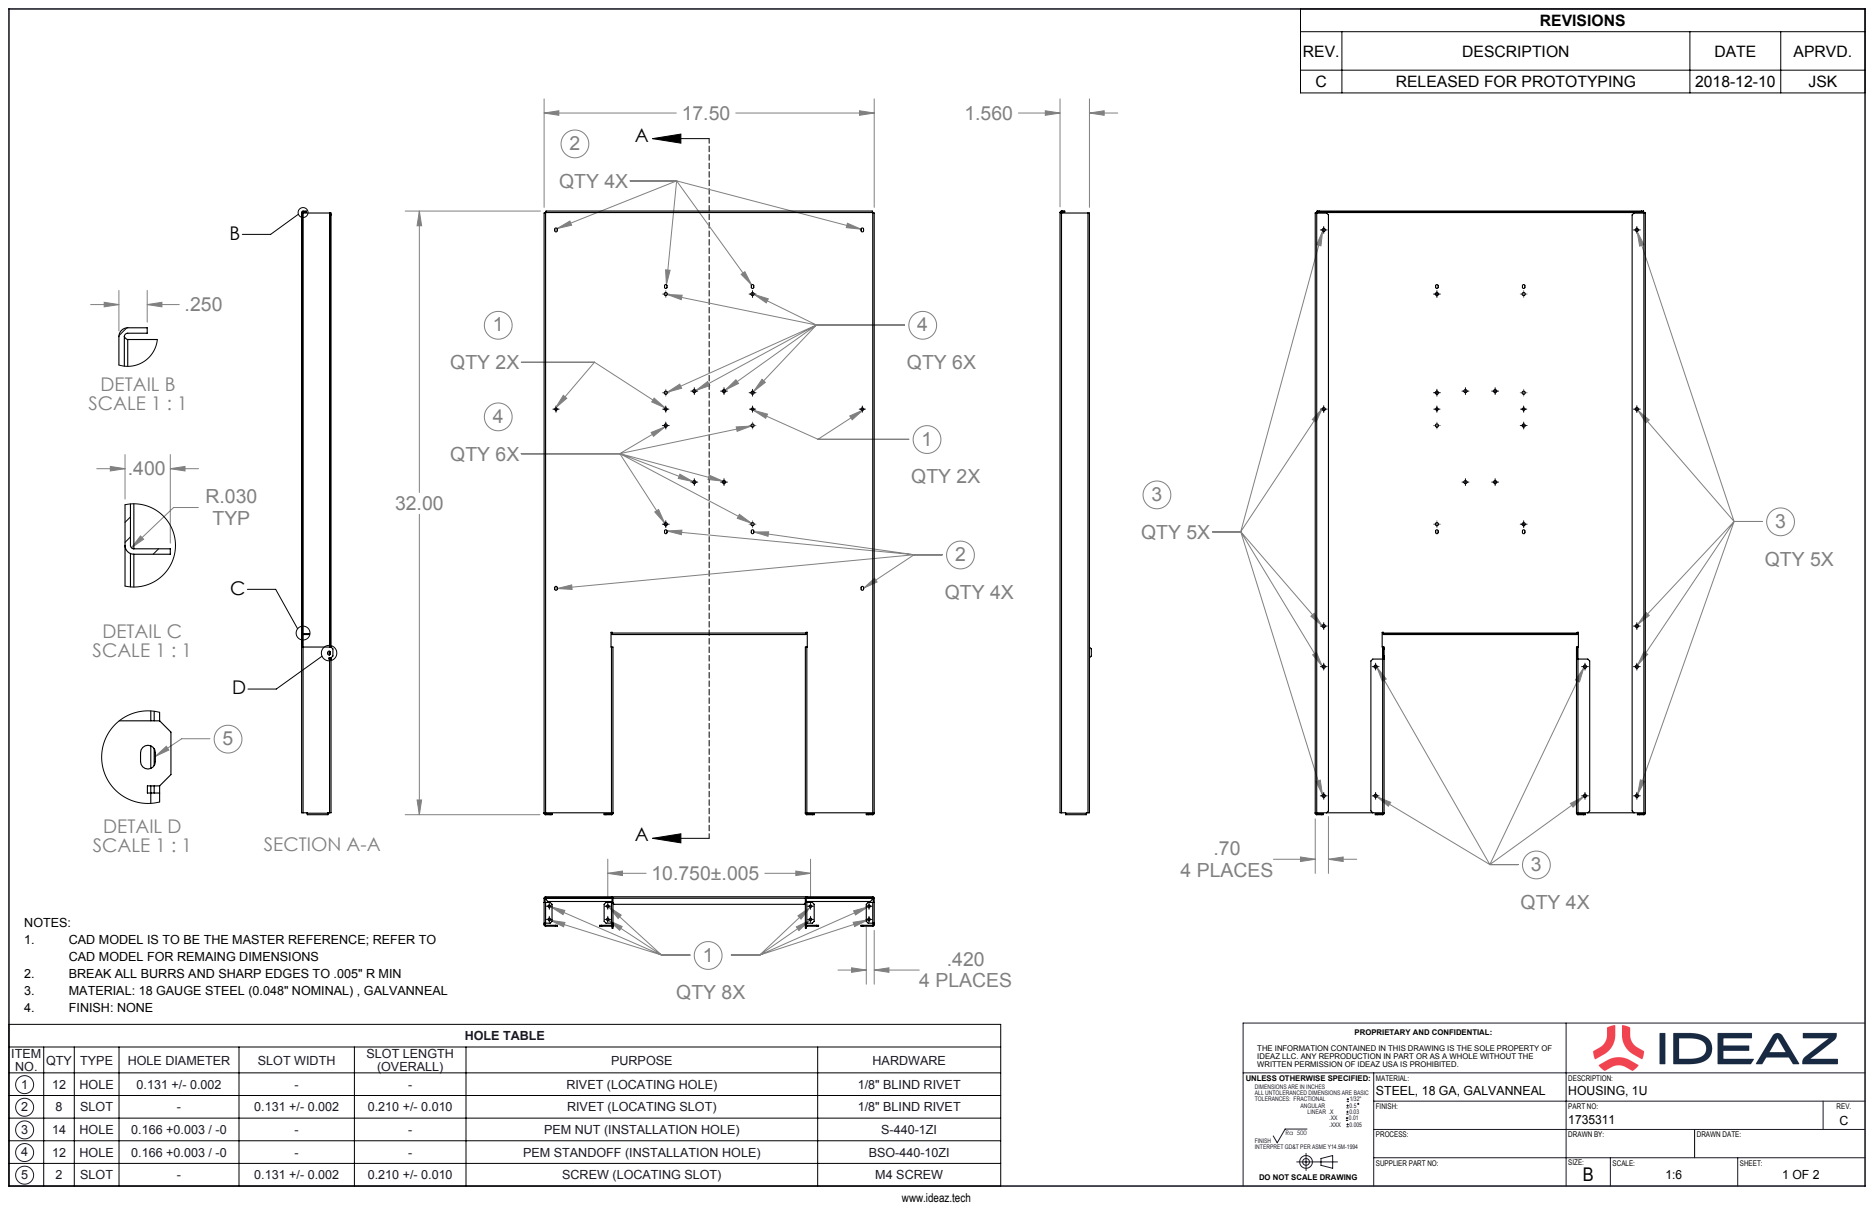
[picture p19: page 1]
TOLERANCES: FRACTIONAL; LINEAR .X; .XXX 0.005; 4 PLACES; QTY 5X; QTY 4X; QTY 2X; QTY 6X; QTY 8X; SECTION A-A; DETAIL B SCALE 1 : 1; DETAIL C SCALE 1 : 1; DETAIL D SCALE 1 : 1; HOLE TABLE; QTY; TYPE; HOLE DIAMETER; SLOT WIDTH; SLOT LENGTH; HOLE; RIVET (LOCATING HOLE); 1/8" BLIND RIVET; HOUSING, 1U

REVISIONS

REV. | DESCRIPTION | DATE | APRVD.
C | RELEASED FOR PROTOTYPING | 2018-12-10 | JSK

NOTES:
1. CAD MODEL IS TO BE THE MASTER REFERENCE; REFER TO
CAD MODEL FOR REMAING DIMENSIONS
2. BREAK ALL BURRS AND SHARP EDGES TO .005" R MIN
3. MATERIAL: 18 GAUGE STEEL (0.048" NOMINAL) , GALVANNEAL
4. FINISH: NONE

PROPRIETARY AND CONFIDENTIAL:

THE INFORMATION CONTAINED IN THIS DRAWING IS THE SOLE PROPERTY OF
IDEAZ LLC. ANY REPRODUCTION IN PART OR AS A WHOLE WITHOUT THE
WRITTEN PERMISSION OF IDEAZ USA IS PROHIBITED.
UNLESS OTHERWISE SPECIFIED:
DIMENSIONS ARE IN INCHES
ALL UNTOLERANCED DIMENSIONS ARE BASIC

MATERIAL:
STEEL, 18 GA, GALVANNEAL

2 | 8 | SLOT | - | 0.131 +/- 0.002 | 0.210 +/- 0.010 | RIVET (LOCATING SLOT) | 1/8" BLIND RIVET
3 | 14 | HOLE | 0.166 +0.003 / -0 | - | - | PEM NUT (INSTALLATION HOLE) | S-440-1ZI
4 | 12 | HOLE | 0.166 +0.003 / -0 | - | - | PEM STANDOFF (INSTALLATION HOLE) | BSO-440-10ZI
5 | 2 | SLOT | - | 0.131 +/- 0.002 | 0.210 +/- 0.010 | SCREW (LOCATING SLOT) | M4 SCREW

FINISH: | PART NO: REV. 1735311 C

FINISH
INTERPRET GD&T PER ASME Y14.5M-1994

PROCESS: | DRAWN BY: | DRAWN DATE:
SUPPLIER PART NO: | SIZE: B | SCALE: 1:6 | SHEET: 1 OF 2

DO NOT SCALE DRAWING

www.ideaz.tech

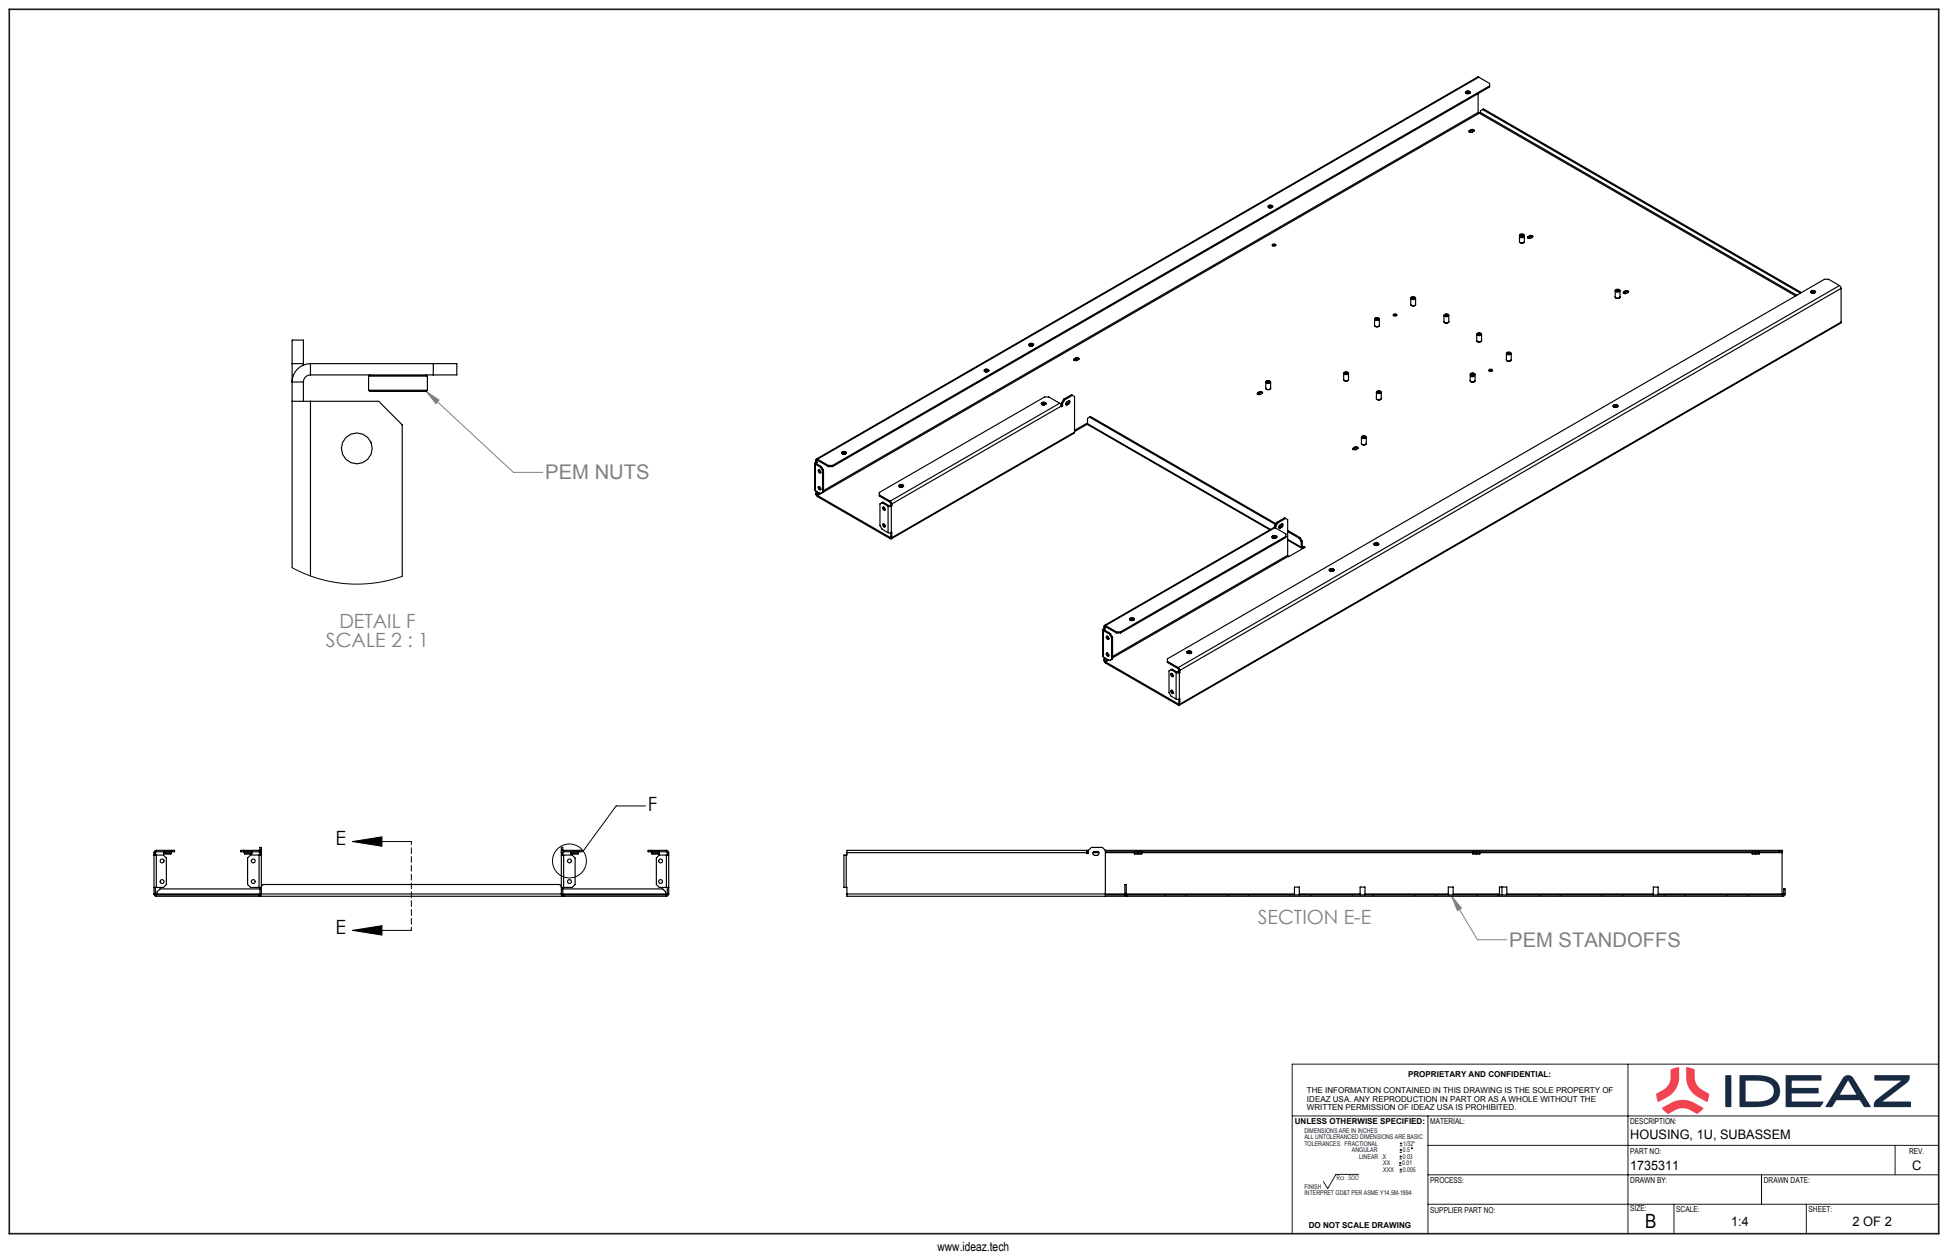
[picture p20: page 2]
SECTION E-E; PEM STANDOFFS; DETAIL F SCALE 2 : 1; PEM NUTS

PROPRIETARY AND CONFIDENTIAL: THE INFORMATION CONTAINED IN THIS DRAWING IS THE SOLE PROPERTY OF IDEAZ USA. ANY REPRODUCTION IN PART OR AS A WHOLE WITHOUT THE WRITTEN PERMISSION OF IDEAZ USA IS PROHIBITED.

UNLESS OTHERWISE SPECIFIED: DIMENSIONS ARE IN INCHES ALL UNTOLERANCED DIMENSIONS ARE BASIC TOLERANCES: FRACTIONAL 1/32" ANGULAR 0.5 LINEAR .X 0.03 .XX 0.01 .XXX 0.005 Ra 500 FINISH INTERPRET GD&T PER ASME Y14.5M-1994 DO NOT SCALE DRAWING | MATERIAL: | DESCRIPTION: HOUSING, 1U, SUBASSEM

PART NO: 1735311 | REV. C

PROCESS: | DRAWN BY: | DRAWN DATE:
SUPPLIER PART NO: | SIZE: B | SCALE: 1:4 | SHEET: 2 OF 2

www.ideaz.tech

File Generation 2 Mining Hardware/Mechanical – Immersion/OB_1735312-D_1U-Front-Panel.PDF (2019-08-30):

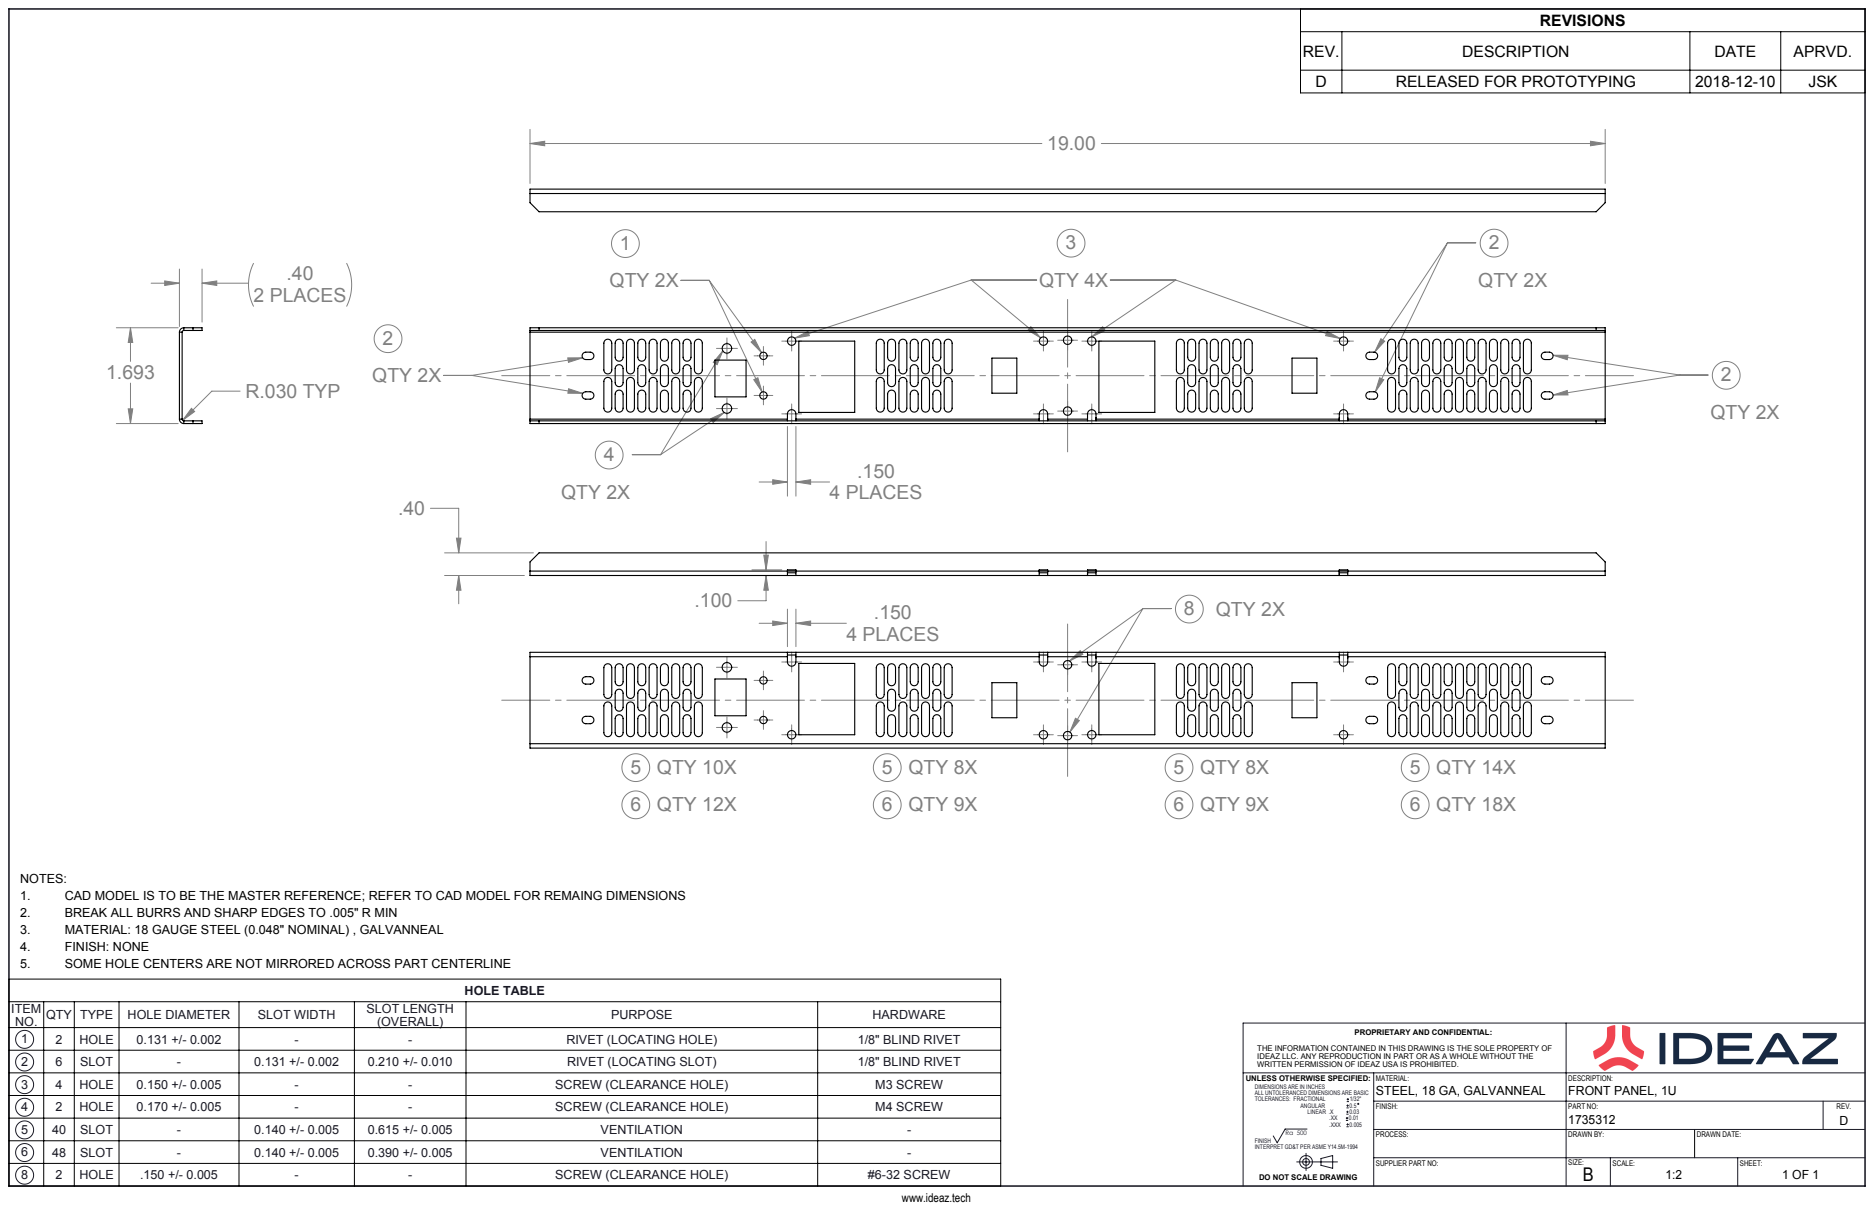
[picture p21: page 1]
TOLERANCES: FRACTIONAL; LINEAR .X; .XXX 0.005; 4 PLACES; QTY 2X; QTY 4X; R.030 TYP; 2 PLACES; 8 QTY 2X; 5 QTY 10X 6 QTY 12X; 5 QTY 14X 6 QTY 18X; 5 QTY 8X 6 QTY 9X; HOLE TABLE; HOLE; SCREW (CLEARANCE HOLE); M3 SCREW; FRONT PANEL, 1U

REVISIONS

REV. | DESCRIPTION | DATE | APRVD.
D | RELEASED FOR PROTOTYPING | 2018-12-10 | JSK

NOTES:
1. CAD MODEL IS TO BE THE MASTER REFERENCE; REFER TO CAD MODEL FOR REMAING DIMENSIONS
2. BREAK ALL BURRS AND SHARP EDGES TO .005" R MIN
3. MATERIAL: 18 GAUGE STEEL (0.048" NOMINAL) , GALVANNEAL
4. FINISH: NONE
5. SOME HOLE CENTERS ARE NOT MIRRORED ACROSS PART CENTERLINE

ITEM NO. | QTY | TYPE | HOLE DIAMETER | SLOT WIDTH | SLOT LENGTH (OVERALL) | PURPOSE | HARDWARE
1 | 2 | HOLE | 0.131 +/- 0.002 | - | - | RIVET (LOCATING HOLE) | 1/8" BLIND RIVET
2 | 6 | SLOT | - | 0.131 +/- 0.002 | 0.210 +/- 0.010 | RIVET (LOCATING SLOT) | 1/8" BLIND RIVET

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

UNLESS OTHERWISE SPECIFIED:
DIMENSIONS ARE IN INCHES
ALL UNTOLERANCED DIMENSIONS ARE BASIC

MATERIAL:
STEEL, 18 GA, GALVANNEAL

4 | 2 | HOLE | 0.170 +/- 0.005 | - | - | SCREW (CLEARANCE HOLE) | M4 SCREW
5 | 40 | SLOT | - | 0.140 +/- 0.005 | 0.615 +/- 0.005 | VENTILATION | -
6 | 48 | SLOT | - | 0.140 +/- 0.005 | 0.390 +/- 0.005 | VENTILATION | -
8 | 2 | HOLE | .150 +/- 0.005 | - | - | SCREW (CLEARANCE HOLE) | #6-32 SCREW

FINISH: | PART NO: REV. 1735312 D

FINISH
INTERPRET GD&T PER ASME Y14.5M-1994

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

DO NOT SCALE DRAWING

www.ideaz.tech

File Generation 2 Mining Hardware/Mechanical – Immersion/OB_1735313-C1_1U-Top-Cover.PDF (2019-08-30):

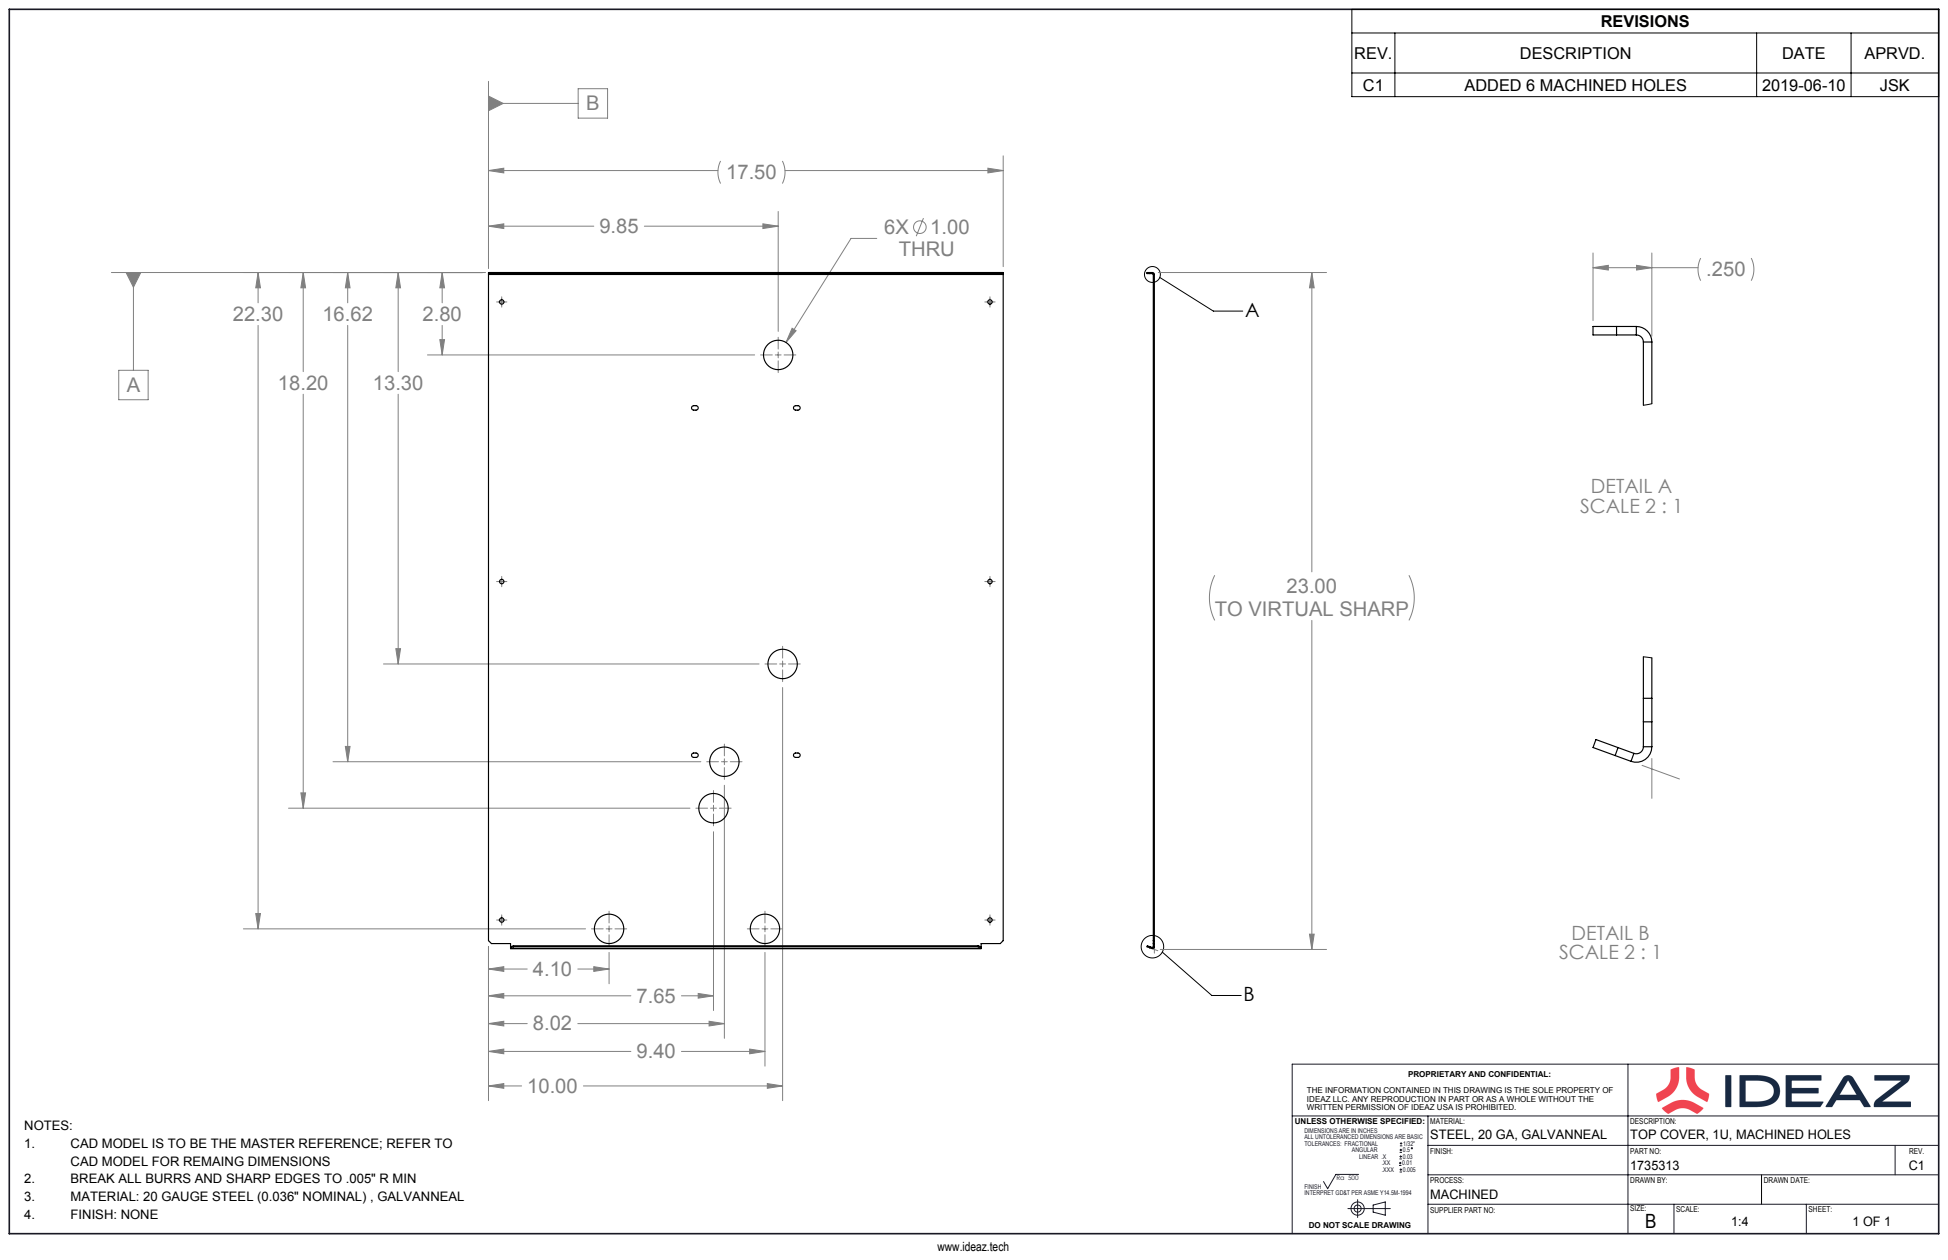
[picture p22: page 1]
DETAIL B SCALE 2 : 1; DETAIL A SCALE 2 : 1

REVISIONS

REV. | DESCRIPTION | DATE | APRVD.
C1 | ADDED 6 MACHINED HOLES | 2019-06-10 | JSK

TO VIRTUAL SHARP

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

NOTES:
1. CAD MODEL IS TO BE THE MASTER REFERENCE; REFER TO
CAD MODEL FOR REMAING DIMENSIONS
2. BREAK ALL BURRS AND SHARP EDGES TO .005" R MIN
3. MATERIAL: 20 GAUGE STEEL (0.036" NOMINAL) , GALVANNEAL
4. FINISH: NONE

UNLESS OTHERWISE SPECIFIED: DIMENSIONS ARE IN INCHES ALL UNTOLERANCED DIMENSIONS ARE BASIC TOLERANCES: FRACTIONAL 1/32" ANGULAR 0.5 LINEAR .X 0.03 .XX 0.01 .XXX 0.005 Ra 500 FINISH INTERPRET GD&T PER ASME Y14.5M-1994 DO NOT SCALE DRAWING | MATERIAL: STEEL, 20 GA, GALVANNEAL | DESCRIPTION: TOP COVER, 1U, MACHINED HOLES

FINISH: | PART NO: REV. 1735313 C1

PROCESS: MACHINED | DRAWN BY: | DRAWN DATE:
SUPPLIER PART NO: | SIZE: B | SCALE: 1:4 | SHEET: 1 OF 1

www.ideaz.tech

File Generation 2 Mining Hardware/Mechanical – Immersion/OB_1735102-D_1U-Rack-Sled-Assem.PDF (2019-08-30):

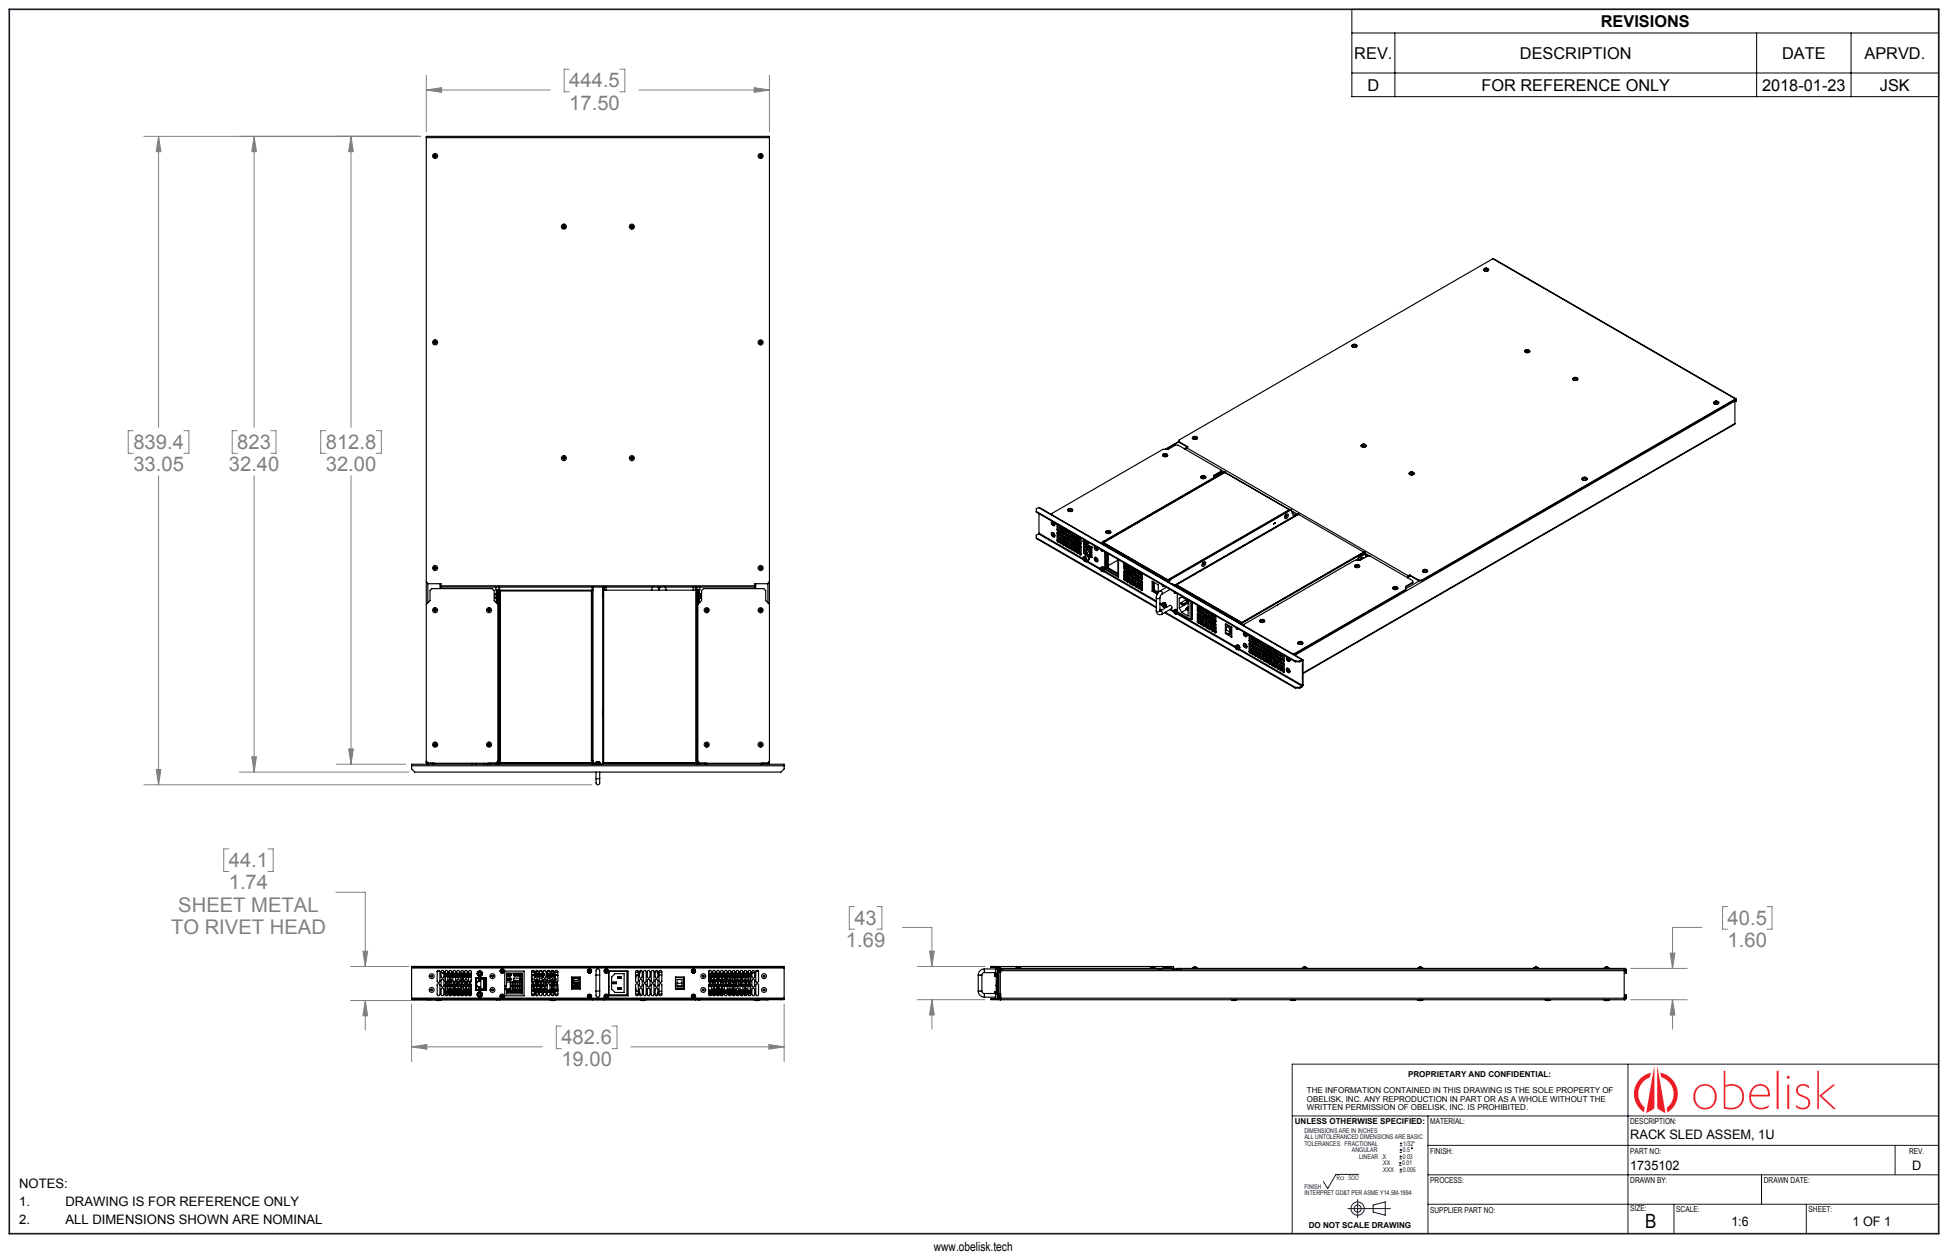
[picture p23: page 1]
SHEET METAL; TO RIVET HEAD

REVISIONS

REV. | DESCRIPTION | DATE | APRVD.
D | FOR REFERENCE ONLY | 2018-01-23 | JSK

PROPRIETARY AND CONFIDENTIAL: THE INFORMATION CONTAINED IN THIS DRAWING IS THE SOLE PROPERTY OF OBELISK, INC. ANY REPRODUCTION IN PART OR AS A WHOLE WITHOUT THE WRITTEN PERMISSION OF OBELISK, INC. IS PROHIBITED.

UNLESS OTHERWISE SPECIFIED: DIMENSIONS ARE IN INCHES ALL UNTOLERANCED DIMENSIONS ARE BASIC TOLERANCES: FRACTIONAL 1/32" ANGULAR 0.5 LINEAR .X 0.03 .XX 0.01 .XXX 0.005 Ra 500 FINISH INTERPRET GD&T PER ASME Y14.5M-1994 DO NOT SCALE DRAWING | MATERIAL: | DESCRIPTION: RACK SLED ASSEM, 1U

FINISH: | PART NO: REV. 1735102 D

NOTES:
1. DRAWING IS FOR REFERENCE ONLY
2. ALL DIMENSIONS SHOWN ARE NOMINAL

PROCESS: | DRAWN BY: | DRAWN DATE:
SUPPLIER PART NO: | SIZE: B | SCALE: 1:6 | SHEET: 1 OF 1

www.obelisk.tech

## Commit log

2019-08-30 First pass of all hardware files
    [93090A420_PRESS-FIT FEMALE ROUND STANDOFFS.SLDPRT, 95185A185_ZNC-PLTD STL PRESS-IN NUTS FOR SHEET MTL.SLDPRT, APS-Power-Supply_01.SLDPRT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]
2019-08-30 Updated folder name
    [APS-Power-Supply_01.SLDPRT, APS-Power-Supply_Assem_02.SLDASM, ATS-2476-C1-R0.SLDPRT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]
2019-09-10 unzipped folders
    [CC1B-STK-R1.xls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]
2019-09-12 Gen1 BOMs and Gen2 Heatsink
    [Control Board BOM.xlsx, DCR1 BOM.xlsx, Heatsink.SLDPRT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]
